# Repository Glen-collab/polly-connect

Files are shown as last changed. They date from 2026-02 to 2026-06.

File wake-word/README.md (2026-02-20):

# Wake Word Training - "Hey Polly"

This folder contains assets for training a custom wake word model.

## Current Status

Currently using **"Hey Jarvis"** from OpenWakeWord as a placeholder. Custom "Hey Polly" training is Phase 4.

## Training Process

### 1. Collect Audio Samples

**Positive samples** (47 recorded):
- Clear "Hey Polly" recordings
- Multiple speakers if possible
- Various distances from mic
- Different ambient noise levels

**Negative samples** (20 recorded):
- Random speech not containing wake word
- Common phrases that sound similar
- Background noise

### 2. Use Google Colab for Training

1. Go to [Google Colab](https://colab.research.google.com)
2. Open the OpenWakeWord training notebook:
   ```
   https://github.com/dscripka/openWakeWord/blob/main/notebooks/automatic_model_training.ipynb
   ```
3. Change runtime to **T4 GPU** (Runtime → Change runtime type)
4. Upload your samples:
   - `positive/` → "Hey Polly" clips
   - `negative/` → non-wake-word clips
5. Run all cells
6. Download the trained model (`.onnx` or `.tflite`)

### 3. Deploy to ESP32

**Option A: TFLite (recommended)**
- Smaller model size
- Native ESP32 support via TensorFlow Lite Micro
- Convert ONNX to TFLite if needed

**Option B: Edge Impulse**
- User-friendly web interface
- Handles conversion automatically
- Free tier available

### 4. Integration

Place the model file in `firmware/polly-esp32/` and update wake word detection code.

## Sample Requirements

### Recording Tips

- Use same mic type as target device (INMP441)
- 16kHz sample rate, mono
- 1-2 seconds per clip
- Include slight variations:
  - "Hey Polly"
  - "Hey, Polly"
  - "Hey Polly?"

### File Format

- WAV files preferred
- 16-bit PCM
- Naming: `positive_001.wav`, `negative_001.wav`

## Alternative: Picovoice Porcupine

For production, consider [Picovoice Porcupine](https://picovoice.ai/):
- Professional-grade accuracy
- Easy custom wake word training
- Free tier for personal use
- Native ESP32 support

## Resources

- [OpenWakeWord](https://github.com/dscripka/openWakeWord)
- [Edge Impulse](https://www.edgeimpulse.com/)
- [Picovoice Porcupine](https://picovoice.ai/platform/porcupine/)
- [TensorFlow Lite Micro](https://www.tensorflow.org/lite/microcontrollers)

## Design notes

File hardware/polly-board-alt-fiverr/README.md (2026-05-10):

# Polly PCB v2 — Fiverr alternate

Drop the Fiverr designer's KiCad project + production files here when ready.
This sits alongside `hardware/polly-board/` (Paul's canonical v2) so we can
manufacture and bench-test both designs and pick a winner.

Use `hardware/COMPONENTS_FOR_DESIGNER.md` as the spec and Paul's project at
`hardware/polly-board/` as the reference layout.

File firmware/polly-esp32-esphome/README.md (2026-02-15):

# Polly ESP32-S3 Voice Assistant (ESPHome + microWakeWord)

On-device wake word detection using **microWakeWord** integrated with Home Assistant and Polly Connect server.

## Why ESPHome + Home Assistant?

✅ **microWakeWord ecosystem** - Access to [hundreds of community wake words](https://github.com/TaterTotterson/microWakeWords)
✅ **Easy customization** - YAML configuration instead of C++ programming
✅ **Proven and stable** - Used by thousands in Home Assistant community
✅ **OTA updates** - Update firmware wirelessly
✅ **Web dashboard** - Monitor and control from browser

## Hardware Requirements

### Required:
1. **ESP32-S3 Development Board** with PSRAM (8MB recommended)
2. **INMP441 I2S MEMS Microphone** (~$2-5)

### Optional:
3. **RGB LED** for status indication (WS2812 or discrete RGB)

### Wiring Diagram (INMP441 → ESP32-S3):

```
INMP441 Pin    ESP32-S3 GPIO    Purpose
-----------    -------------    -------
WS             GPIO 42          I2S Word Select (LRCLK)
SD             GPIO 41          I2S Serial Data (DIN)
SCK            GPIO 40          I2S Serial Clock (BCLK)
L/R            GND              Channel Select (Left)
VDD            3.3V             Power
GND            GND              Ground
```

**Optional RGB LED:**
```
LED Pin        ESP32-S3 GPIO
-------        -------------
Red            GPIO 48
Green          GPIO 47
Blue           GPIO 21
GND            GND
```

## Software Requirements

### 1. Install Home Assistant

**Option A: Run on Same Computer as Polly Server**
```bash
# Install Home Assistant Core (Python)
python3 -m pip install homeassistant
hass
```
Access at: `http://localhost:8123`

**Option B: Separate Raspberry Pi / VM**
- Download Home Assistant OS: https://www.home-assistant.io/installation/
- Flash to SD card or install in VM
- Access at: `http://homeassistant.local:8123`

**Option C: Docker (Recommended for Testing)**
```bash
docker run -d \
  --name homeassistant \
  --privileged \
  --restart=unless-stopped \
  -e TZ=America/New_York \
  -v /PATH_TO_YOUR_CONFIG:/config \
  --network=host \
  ghcr.io/home-assistant/home-assistant:stable
```

### 2. Install ESPHome in Home Assistant

1. Open Home Assistant web interface
2. Go to **Settings** → **Add-ons**
3. Click **Add-on Store**
4. Search for **ESPHome**
5. Click **Install**
6. Start the ESPHome add-on
7. Open the ESPHome web UI

### 3. Install ESPHome CLI (Alternative)

If you prefer command-line:
```bash
pip install esphome
```

## Setup Steps

### Step 1: Configure Secrets

Edit `secrets.yaml`:
```yaml
wifi_ssid: "YourWiFiSSID"
wifi_password: "YourWiFiPassword"
api_encryption_key: ""  # Will be auto-generated
ota_password: "polly-ota-password"
```

Generate API encryption key:
```bash
openssl rand -base64 32
```

### Step 2: Compile and Flash Firmware

**Using ESPHome Dashboard (Easiest):**
1. Open ESPHome in Home Assistant
2. Click **+ New Device**
3. Give it a name: `polly-voice-assistant`
4. Choose **ESP32-S3**
5. Copy the contents of `polly-voice-assistant.yaml` into the editor
6. Click **Install** → **Plug into this computer**
7. Select the USB port and flash

**Using ESPHome CLI:**
```bash
cd firmware/polly-esp32-esphome

# Compile
esphome compile polly-voice-assistant.yaml

# Flash (ESP32 connected via USB)
esphome upload polly-voice-assistant.yaml
```

### Step 3: Verify Connection

1. Device should appear in Home Assistant **Settings** → **Devices & Services**
2. Click **Configure** and enter API encryption key
3. Device should show as "Online"

### Step 4: Test Wake Word Detection

1. Say **"Okay Nabu"** into the microphone
2. Watch the logs in ESPHome dashboard
3. LED should turn green when wake word detected
4. LED should turn blue when listening for command

**Check logs:**
```bash
esphome logs polly-voice-assistant.yaml
```

Expected output:
```
[microWakeWord] Wake word detected: Okay Nabu
[voice_assistant] Listening for command...
```

### Step 5: Bridge to Polly Server

#### A. Update Polly Server

The server has been updated with a new endpoint: `/api/commands/process`

This endpoint receives voice commands from Home Assistant and processes them through your Polly intent parser and database.

#### B. Configure Home Assistant Automation

1. In Home Assistant, go to **Settings** → **Automations & Scenes**
2. Click **Create Automation**
3. Choose **Start with an empty automation**
4. Switch to **YAML mode** (three dots menu)
5. Paste the contents from `home-assistant-config/polly-bridge-automation.yaml`
6. **Important**: Replace `YOUR_POLLY_SERVER_IP` with your actual server IP
7. Save the automation

**Or manually add to `configuration.yaml`:**
```yaml
# Add this to your Home Assistant configuration.yaml
automation: !include automations.yaml
rest_command: !include rest_commands.yaml
```

Then create `rest_commands.yaml`:
```yaml
polly_send_command:
  url: "http://192.168.1.100:8000/api/commands/process"
  method: POST
  content_type: "application/json"
  payload: >
    {
      "transcription": "{{ transcription }}",
      "device_id": "{{ device_id }}",
      "source": "home_assistant"
    }
```

### Step 6: Test End-to-End

1. **Start Polly Server:**
   ```bash
   cd server
   python main.py
   ```

2. **Say wake word:** "Okay Nabu"
3. **Say command:** "My keys are in the kitchen"
4. **Check Polly server logs:**
   ```
   [homeassistant] Received command: My keys are in the kitchen
   [intent_parser] Intent: store
   [database] Stored: keys → kitchen
   ```

5. **Test retrieval:**
   - Say: "Okay Nabu"
   - Say: "Where are my keys?"
   - Server should respond: "The keys are in the kitchen."

## Available Wake Words

### Pre-installed:
- **okay_nabu** (default)
- **hey_jarvis**
- **alexa**
- **hey_mycroft**

### Change Wake Word:

Edit `polly-voice-assistant.yaml`:
```yaml
micro_wake_word:
  model: hey_jarvis  # Change this line
  probability_cutoff: 0.97
  sliding_window_average_size: 5
```

Then reflash:
```bash
esphome upload polly-voice-assistant.yaml
```

### Use Community Wake Words:

Browse available models:
- https://github.com/TaterTotterson/microWakeWords
- https://github.com/esphome/micro-wake-word-models

Example using custom wake word from GitHub:
```yaml
micro_wake_word:
  models:
    - model: https://github.com/TaterTotterson/microWakeWords/raw/main/models/v2/computer.tflite
```

### Create Your Own Custom Wake Word:

1. Visit: https://www.kevinahrendt.com/micro-wake-word
2. Follow the training guide using Google Colab (free)
3. Download the `.tflite` model file
4. Host it on GitHub or local webserver
5. Reference it in your ESPHome config

**Or request from community:**
- Post in Home Assistant forums
- Many community members train wake words for others
- See: https://community.home-assistant.io

## Troubleshooting

### Wake word not detected

**Check microphone:**
```bash
esphome logs polly-voice-assistant.yaml
```

Look for I2S audio initialization:
```
[i2s_audio] Initializing I2S...
[microphone] Microphone started
```

**Adjust sensitivity:**
```yaml
micro_wake_word:
  probability_cutoff: 0.90  # Lower = more sensitive (default: 0.97)
  sliding_window_average_size: 3  # Lower = faster detection (default: 5)
```

**Check wiring:**
- INMP441 L/R pin MUST be connected to GND
- Verify GPIO pins match your configuration
- Check 3.3V power supply is stable

### Home Assistant not receiving commands

**Check automation:**
1. Go to **Settings** → **Automations & Scenes**
2. Find "Polly Voice Assistant Bridge"
3. Click **Run** to manually trigger
4. Check **Trace** for errors

**Check Polly server:**
```bash
curl -X POST http://localhost:8000/api/commands/process \
  -H "Content-Type: application/json" \
  -d '{"transcription":"test command","device_id":"test"}'
```

### ESP32 won't connect to WiFi

**Check secrets.yaml:**
- SSID is correct (case-sensitive)
- Password is correct
- WiFi is 2.4GHz (ESP32 doesn't support 5GHz)

**Enable fallback hotspot:**
1. ESP32 creates WiFi network: `polly-voice-assistant Fallback`
2. Password: `polly12345`
3. Connect and reconfigure WiFi

### OTA updates fail

**Use USB:**
```bash
esphome upload polly-voice-assistant.yaml --device /dev/ttyUSB0
```

**Increase timeout:**
```yaml
ota:
  - platform: esphome
    password: !secret ota_password
    safe_mode: true
    reboot_timeout: 15min
```

## Architecture Diagram

```
┌─────────────┐
│   INMP441   │ Microphone
└──────┬──────┘
       │ I2S Audio (16kHz)
       ↓
┌──────────────────────────────┐
│      ESP32-S3 (ESPHome)      │
│  ┌────────────────────────┐  │
│  │   microWakeWord        │  │
│  │   "Okay Nabu" → ✓      │  │
│  └───────────┬────────────┘  │
│              ↓                │
│  ┌────────────────────────┐  │
│  │   Voice Assistant      │  │
│  │   Record command audio │  │
│  └───────────┬────────────┘  │
└──────────────┼───────────────┘
               │ Home Assistant API
               ↓
┌──────────────────────────────┐
│      Home Assistant          │
│  ┌────────────────────────┐  │
│  │  Whisper (Transcribe)  │  │
│  │  "my keys are..."      │  │
│  └───────────┬────────────┘  │
│              ↓                │
│  ┌────────────────────────┐  │
│  │  Automation Bridge     │  │
│  │  Forward to Polly      │  │
│  └───────────┬────────────┘  │
└──────────────┼───────────────┘
               │ HTTP POST
               ↓
┌──────────────────────────────┐
│    Polly Connect Server      │
│  ┌────────────────────────┐  │
│  │  Intent Parser         │  │
│  │  "store: keys→kitchen" │  │
│  └───────────┬────────────┘  │
│              ↓                │
│  ┌────────────────────────┐  │
│  │  Database              │  │
│  │  Save location         │  │
│  └────────────────────────┘  │
└──────────────────────────────┘
```

## Performance

- **Wake Word Latency**: <100ms
- **End-to-End**: ~2-3 seconds (wake → response)
- **Bandwidth**: ~50KB for 5-second command
- **Power**: ~150mA @ 3.3V during listening

## Customization

### Add Speaker for TTS Response

```yaml
# Add I2S speaker (MAX98357A)
i2s_audio:
  - id: i2s_out
    i2s_lrclk_pin: GPIO13
    i2s_bclk_pin: GPIO12

speaker:
  - platform: i2s_audio
    id: speaker
    dac_type: external
    i2s_dout_pin: GPIO14
    mode: mono

# Update voice assistant to use speaker
voice_assistant:
  microphone: mic
  speaker: speaker  # Add this line
```

### Change LED Pins

Update the `output` section:
```yaml
output:
  - platform: ledc
    id: led_red
    pin: GPIO1  # Change to your red LED pin
  - platform: ledc
    id: led_green
    pin: GPIO2  # Change to your green LED pin
  - platform: ledc
    id: led_blue
    pin: GPIO3  # Change to your blue LED pin
```

### Multiple Wake Words

```yaml
micro_wake_word:
  models:
    - model: okay_nabu
    - model: hey_jarvis
    - model: alexa
```

ESP32-S3 can run up to 4 models simultaneously!

## Resources

- **ESPHome Documentation**: https://esphome.io
- **microWakeWord**: https://www.kevinahrendt.com/micro-wake-word
- **Community Wake Words**: https://github.com/TaterTotterson/microWakeWords
- **Home Assistant**: https://www.home-assistant.io
- **Polly Connect**: [Your GitHub repo]

## Support

For issues:
1. Check ESPHome logs first
2. Verify Home Assistant automation
3. Test Polly server endpoint manually
4. Ask in Home Assistant community forums

## License

This project integrates multiple open-source components:
- ESPHome: MIT License
- microWakeWord: Apache 2.0
- Home Assistant: Apache 2.0

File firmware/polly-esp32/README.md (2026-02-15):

# Polly ESP32-S3 - Porcupine Wake Word Integration

On-device wake word detection for ESP32-S3 using Picovoice Porcupine.

## Overview

This firmware implements local wake word detection on ESP32-S3 hardware, eliminating the need for continuous audio streaming to the server. The device only sends audio data to the Polly Connect server **after** detecting the wake word locally, reducing bandwidth by 90%+ and improving response latency.

**Features:**
- ✅ On-device wake word detection using Porcupine
- ✅ INMP441 I2S MEMS microphone support
- ✅ WiFi connectivity with auto-reconnect
- ✅ WebSocket communication with Polly Connect server
- ✅ 2-second pre-wake audio buffering (for better transcription)
- ✅ Dual-core FreeRTOS architecture
- ✅ PSRAM utilization for large buffers

## Hardware Requirements

### Required Components:
1. **ESP32-S3 Development Board**
   - Must have PSRAM (8MB recommended)
   - Any ESP32-S3 variant will work (DevKit, WROOM, etc.)

2. **INMP441 I2S MEMS Microphone**
   - Digital I2S output
   - High-quality omnidirectional
   - ~$2-5 on AliExpress/Amazon

### Wiring (INMP441 → ESP32-S3):
```
INMP441 Pin    ESP32-S3 GPIO    Purpose
-----------    -------------    -------
WS             GPIO 42          I2S Word Select (LRCLK)
SD             GPIO 41          I2S Serial Data (DIN)
SCK            GPIO 40          I2S Serial Clock (BCLK)
L/R            GND              Channel Select (Left)
VDD            3.3V             Power
GND            GND              Ground
```

**Note:** You can change GPIO pins by editing `main/config.h`

## Software Requirements

### 1. ESP-IDF Installation

Install ESP-IDF v5.1 or later:

```bash
# Clone ESP-IDF
cd ~
git clone --recursive https://github.com/espressif/esp-idf.git
cd esp-idf
git checkout v5.1  # or latest stable release

# Install ESP-IDF
./install.sh esp32s3

# Setup environment (add to ~/.bashrc for persistence)
. ~/esp-idf/export.sh
```

Verify installation:
```bash
idf.py --version
# Should show: ESP-IDF v5.1.x or later
```

### 2. Porcupine Library and Models

**Step 1: Create Picovoice Account**
1. Go to https://console.picovoice.ai/
2. Sign up for a free account
3. Copy your Access Key (you'll need this later)

**Step 2: Download Porcupine Library**

The pre-compiled Porcupine library for ESP32-S3:

```bash
cd components/porcupine/lib/

# Download from Porcupine repository
# Note: Check the latest Porcupine releases for the exact URL
wget https://github.com/Picovoice/porcupine/raw/master/lib/esp32/libpv_porcupine.a
```

**Step 3: Download Porcupine Header**

```bash
cd components/porcupine/include/

# Download the header file
wget https://github.com/Picovoice/porcupine/raw/master/include/pv_porcupine.h
```

**Step 4: Download Wake Word Model**

Choose one of the built-in wake words:

```bash
cd components/porcupine/models/

# Download "Jarvis" wake word model (recommended)
wget https://github.com/Picovoice/porcupine/raw/master/resources/keyword_files/esp32/jarvis_esp.ppn

# Or download other wake words:
# wget https://github.com/Picovoice/porcupine/raw/master/resources/keyword_files/esp32/alexa_esp.ppn
# wget https://github.com/Picovoice/porcupine/raw/master/resources/keyword_files/esp32/computer_esp.ppn
```

**Alternative: Custom Wake Word**
- Train custom wake word at https://console.picovoice.ai/
- Download `.ppn` file for ESP32 platform
- Update `components/porcupine/CMakeLists.txt` with new model name

## Configuration

Configure the project before building:

```bash
cd firmware/polly-esp32
idf.py menuconfig
```

Navigate to **"Polly ESP32 Configuration"** and set:

| Setting | Description | Example |
|---|---|---|
| WiFi SSID | Your WiFi network name | `MyHomeWiFi` |
| WiFi Password | Your WiFi password | `MyPassword123` |
| Maximum Retry | WiFi reconnect attempts | `5` |
| Server WebSocket URI | Polly Connect server URL | `ws://192.168.1.100:8000/api/audio/stream` |
| Picovoice Access Key | Your Picovoice access key | `YOUR_ACCESS_KEY_HERE` |
| Wake word sensitivity | Detection sensitivity (0.0-1.0) | `0.5` |
| Pre-wake audio buffer | Seconds of pre-buffered audio | `2` |

**Important Notes:**
- Replace `192.168.1.100` with your server's actual IP address
- You can find your server IP with: `ip addr show` (Linux) or `ipconfig` (Windows)
- Higher sensitivity = more detections but more false positives
- Lower sensitivity = fewer false positives but might miss wake words

## Building and Flashing

### Build the Firmware

```bash
cd firmware/polly-esp32

# Clean previous builds (optional)
idf.py fullclean

# Build the project
idf.py build
```

Expected output:
```
Project build complete. To flash, run:
  idf.py -p (PORT) flash
```

### Flash to ESP32-S3

Connect your ESP32-S3 via USB, then:

```bash
# Auto-detect port and flash
idf.py flash

# Or specify port explicitly
idf.py -p /dev/ttyUSB0 flash    # Linux
idf.py -p COM3 flash             # Windows
```

### Monitor Serial Output

```bash
# Start serial monitor
idf.py monitor

# Or flash and monitor in one command
idf.py flash monitor
```

**Keyboard shortcuts in monitor:**
- `Ctrl+]` - Exit monitor
- `Ctrl+T` then `Ctrl+H` - Show help

## Expected Boot Sequence

After flashing, you should see:

```
========================================
  Polly ESP32-S3 - Porcupine Wake Word
========================================
[main] Connecting to WiFi SSID: MyHomeWiFi
[wifi_manager] WiFi initialization complete
[wifi_manager] Got IP:192.168.1.150
[wifi_manager] Connected to SSID:MyHomeWiFi
[porcupine] Initializing Porcupine
[porcupine] Model size: 85234 bytes
[porcupine] Sensitivity: 0.50
[porcupine] Porcupine initialized successfully
[porcupine] Frame length: 512 samples
[porcupine] Sample rate: 16000 Hz
[audio_capture] Allocated circular buffer: 62 frames (63488 bytes)
[audio_capture] I2S initialized (16kHz, mono, 16-bit)
[audio_capture] GPIO: WS=42, SD=41, SCK=40
[websocket] WebSocket client started
[websocket] WebSocket connected
[main] Creating tasks...
[audio_capture] Audio capture task started
[wake_word] Wake word task started
[streaming] Streaming task started
========================================
System initialized successfully!
Listening for wake word...
========================================
```

## Testing Wake Word Detection

### 1. Basic Wake Word Test

Say **"Jarvis"** clearly into the microphone (1-3 meters away).

Expected logs:
```
[porcupine] *** WAKE WORD DETECTED! (index: 0) ***
[main] WAKE WORD DETECTED!
[main] State transition: IDLE -> WAKE_DETECTED
[streaming] Starting audio streaming...
[websocket] Sent wake_word_detected event
[streaming] Streaming 62 frames of pre-buffered audio
[streaming] Streaming live audio (max 5 seconds)...
```

### 2. Full Command Test

1. Say **"Jarvis"** (wake word)
2. Wait for acknowledgment (LED/log)
3. Say command: **"where are my keys"**
4. Wait for response

Expected logs:
```
[porcupine] *** WAKE WORD DETECTED! (index: 0) ***
[main] Starting audio streaming...
[websocket] Sent wake_word_detected event
[streaming] Audio streaming complete (312 live frames sent)
[websocket] Sent command_end event
[main] State transition: WAKE_DETECTED -> PROCESSING
[main] Transcription: where are my keys
[main] Intent: retrieve_item
[main] Response: The keys are in the kitchen.
[main] State transition: PROCESSING -> IDLE
[main] Ready for next wake word
```

### 3. Server Verification

On your Polly Connect server, check the logs:

```bash
cd server
python main.py
```

Expected server output:
```
[audio] Device connected: esp32-s3-001
[audio] Wake word detected by device: esp32-s3-001
[transcription] Transcribing audio...
[transcription] Result: where are my keys
[intent_parser] Intent: retrieve_item
[database] Query: SELECT location FROM items WHERE item='keys'
[audio] Response: The keys are in the kitchen.
```

## Troubleshooting

### Problem: Wake word not detected

**Solutions:**
1. **Increase sensitivity**: `idf.py menuconfig` → Set sensitivity to `0.7`
2. **Check microphone wiring**: Verify INMP441 connections
3. **Test microphone**: Check I2S logs for audio capture activity
4. **Check model**: Ensure correct wake word model is embedded
5. **Speak clearly**: Pronounce "Jarvis" distinctly, 1-2 meters from mic

Debug commands:
```bash
# Check if audio is being captured
idf.py monitor | grep "audio_capture"

# Check Porcupine processing
idf.py monitor | grep "porcupine"
```

### Problem: WebSocket connection fails

**Solutions:**
1. **Verify server IP**: `idf.py menuconfig` → Check Server URI
2. **Ping server**: `ping 192.168.1.100` from ESP32's network
3. **Check firewall**: Ensure port 8000 is open
4. **Restart server**: `cd server && python main.py`
5. **Check WiFi**: Verify ESP32 has IP address

Test WebSocket manually:
```bash
# Install wscat
npm install -g wscat

# Test connection
wscat -c ws://192.168.1.100:8000/api/audio/stream
```

### Problem: Out of memory error

**Solutions:**
1. **Verify PSRAM**: Check `sdkconfig.defaults` has `CONFIG_SPIRAM=y`
2. **Check hardware**: ESP32-S3 board must have PSRAM chip
3. **Reduce buffer**: Lower `AUDIO_BUFFER_SECONDS` in menuconfig

Check memory usage:
```bash
idf.py monitor | grep "Heap"
# Should show: Heap: ~200000 bytes, PSRAM: ~8000000 bytes
```

### Problem: Poor audio quality

**Solutions:**
1. **Check L/R pin**: INMP441 L/R must be connected to GND
2. **Verify GPIO**: Confirm WS=42, SD=41, SCK=40 in `config.h`
3. **Check power**: Ensure stable 3.3V supply
4. **Reduce noise**: Keep wires short, away from power lines

### Problem: False positives (random detections)

**Solutions:**
1. **Decrease sensitivity**: Set to `0.3` or `0.4`
2. **Reduce noise**: Move away from fans, air conditioners
3. **Use different wake word**: Try "Computer" instead of "Jarvis"

### Problem: Build errors

**Common errors:**

**"pv_porcupine.h: No such file"**
```bash
# Download the header file
cd components/porcupine/include/
wget https://github.com/Picovoice/porcupine/raw/master/include/pv_porcupine.h
```

**"libpv_porcupine.a: No such file"**
```bash
# Download the library
cd components/porcupine/lib/
wget https://github.com/Picovoice/porcupine/raw/master/lib/esp32/libpv_porcupine.a
```

**"jarvis_esp.ppn: No such file"**
```bash
# Download the wake word model
cd components/porcupine/models/
wget https://github.com/Picovoice/porcupine/raw/master/resources/keyword_files/esp32/jarvis_esp.ppn
```

## Customization

### Change Wake Word

To use a different wake word (e.g., "Computer" instead of "Jarvis"):

1. Download the model:
   ```bash
   cd components/porcupine/models/
   wget https://github.com/Picovoice/porcupine/raw/master/resources/keyword_files/esp32/computer_esp.ppn
   ```

2. Update `components/porcupine/CMakeLists.txt`:
   ```cmake
   target_add_binary_data(${COMPONENT_LIB}
       "${CMAKE_CURRENT_SOURCE_DIR}/models/computer_esp.ppn"
       BINARY
   )
   ```

3. Update `main/porcupine_manager.c`:
   ```c
   extern const uint8_t computer_ppn_start[] asm("_binary_computer_esp_ppn_start");
   extern const uint8_t computer_ppn_end[]   asm("_binary_computer_esp_ppn_end");

   ctx->model_buffer = computer_ppn_start;
   ctx->model_size = computer_ppn_end - computer_ppn_start;
   ```

4. Rebuild and flash:
   ```bash
   idf.py build flash
   ```

### Change GPIO Pins

Edit `main/config.h`:

```c
// GPIO Configuration (INMP441)
#define I2S_WS              GPIO_NUM_42  // Change to your WS pin
#define I2S_SD              GPIO_NUM_41  // Change to your SD pin
#define I2S_SCK             GPIO_NUM_40  // Change to your SCK pin
```

Then rebuild:
```bash
idf.py build flash
```

### Adjust Sensitivity

Via menuconfig:
```bash
idf.py menuconfig
# → Polly ESP32 Configuration → Wake word sensitivity
```

Or edit `main/config.h`:
```c
#define PORCUPINE_SENSITIVITY   0.7f  // Range: 0.0-1.0
```

## Architecture Overview

### System Flow

```
┌─────────────┐
│   INMP441   │ (Microphone)
│  Microphone │
└──────┬──────┘
       │ I2S Audio (16kHz, 16-bit, mono)
       ↓
┌─────────────────────────────────────────┐
│           ESP32-S3 Firmware             │
│  ┌─────────────────────────────────┐   │
│  │  Audio Capture Task (Core 0)    │   │
│  │  - Read 512-sample frames       │   │
│  │  - Store in circular buffer     │   │
│  │  - Send to queue                │   │
│  └───────────┬─────────────────────┘   │
│              │                          │
│              ↓                          │
│  ┌─────────────────────────────────┐   │
│  │  Wake Word Task (Core 1)        │   │
│  │  - Porcupine processing         │   │
│  │  - Detect "Jarvis"              │   │
│  │  - Trigger streaming task       │   │
│  └───────────┬─────────────────────┘   │
│              │ (wake detected)          │
│              ↓                          │
│  ┌─────────────────────────────────┐   │
│  │  Streaming Task (Core 0)        │   │
│  │  - Send wake_word_detected      │   │
│  │  - Stream pre-buffered audio    │   │
│  │  - Stream live audio (5s)       │   │
│  │  - Send command_end             │   │
│  └───────────┬─────────────────────┘   │
│              │ WebSocket                │
└──────────────┼─────────────────────────┘
               │
               ↓
┌──────────────────────────────────────────┐
│      Polly Connect Server (Python)       │
│  - Receive wake_word_detected event     │
│  - Receive audio_stream data            │
│  - Transcribe with Whisper              │
│  - Parse intent                          │
│  - Generate response                     │
│  - Send TTS audio (future)               │
└──────────────────────────────────────────┘
```

### Memory Layout

- **Flash (8MB)**:
  - Application: ~300 KB
  - Porcupine library: ~1.5 MB
  - Wake word model: ~100 KB
  - Remaining: ~6.1 MB free

- **SRAM (512 KB)**:
  - FreeRTOS tasks: ~50 KB
  - WiFi/TCP stack: ~100 KB
  - Remaining: ~360 KB free

- **PSRAM (8 MB)**:
  - Circular audio buffer: ~64 KB
  - Porcupine runtime: ~200 KB
  - Frame buffers: ~10 KB
  - Remaining: ~7.7 MB free

### FreeRTOS Tasks

| Task | Core | Priority | Stack | Purpose |
|---|---|---|---|---|
| `audio_capture` | 0 | 5 | 8 KB | Read I2S audio frames |
| `wake_word` | 1 | 6 | 16 KB | Porcupine wake word detection |
| `audio_stream` | 0 | 5 | 8 KB | Stream audio to server |
| `websocket` | 0 | 4 | 8 KB | WebSocket communication |

## Performance Metrics

- **Wake Word Latency**: <100ms from speech to detection
- **Bandwidth Savings**: 90%+ reduction (only streams 3-5s after wake)
- **Power Consumption**: ~150mA @ 3.3V during active listening
- **Detection Range**: 1-3 meters in quiet environment
- **False Positive Rate**: <1 per hour (at sensitivity 0.5)

## Future Enhancements

### Voice Activity Detection (VAD)
- Auto-detect end of command (no 5-second timeout)
- Implement silence detection algorithm
- Reduce latency by 2-3 seconds

### TTS Audio Playback
- Add I2S speaker output (e.g., MAX98357A)
- Receive and play `audio_chunk` events
- Complete offline voice assistant

### LED Feedback
- WS2812 RGB LED on GPIO 48
- Blue: Idle/listening
- Green: Wake word detected
- Yellow: Processing
- Red: Error

### Over-the-Air (OTA) Updates
- ESP-IDF OTA component integration
- Server endpoint for firmware updates
- No physical access needed for updates

## License

This project uses Picovoice Porcupine which requires attribution:
- Porcupine is licensed under Apache 2.0
- Attribution: "This product uses Porcupine from Picovoice"
- See https://picovoice.ai for terms

## Support

**Issues:**
- ESP32-S3 firmware: Check this README's Troubleshooting section
- Porcupine library: https://github.com/Picovoice/porcupine
- Polly Connect server: Check server documentation

**Resources:**
- ESP-IDF Documentation: https://docs.espressif.com/projects/esp-idf/
- Porcupine Documentation: https://picovoice.ai/docs/porcupine/
- Picovoice Console: https://console.picovoice.ai/

## Credits

- **Picovoice** for Porcupine wake word engine
- **Espressif** for ESP32-S3 and ESP-IDF
- **Polly Connect** server integration

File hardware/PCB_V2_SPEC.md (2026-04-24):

# Polly PCB v2 — Fully Assembled Production Board

## Status
**Schematic + PCB layout finalized by Paul P. (Upwork), April 17, 2026.** Glen approved; Paul closed his contract April 20 with ~24 hours logged. A separate designer was engaged to produce the manufacturing files (gerbers, BOM, CPL) from Paul's KiCad output and has not responded as of this file's date — if they don't surface, a new designer can pick this up directly from Paul's KiCad files.

**Final board render from Paul**: [`polly-board/polly_board_v2_final.png`](polly-board/polly_board_v2_final.png). This is what the delivered design looks like — dimensions, component placement, and test-point layout along the bottom edge all visible. A new designer should match this render exactly when producing manufacturing files.

**What a new designer needs to know:**
- The **schematic and board layout are done**. The remaining work is purely producing JLCPCB-ready manufacturing outputs: gerbers, drill files, a BOM CSV in LCSC format, and a CPL/POS CSV for pick-and-place.
- Paul's final KiCad files should live in `hardware/polly-board/` — if they're missing from the repo, Glen needs to get them from Paul before handoff.
- **Do NOT trust `polly_pcb_bom_jlcpcb.csv` or `polly_pcb-top-pos.csv` currently checked in.** Those are from the earlier Fiverr revision (5-pin headers for mic/amp, "5.1" ohm pull-downs instead of 5.1 kΩ, ~10 mm button spacing instead of 15 mm). They must be regenerated from Paul's final files.

For the full upstream paper trail, see:
- `polly-board/SCHEMATIC-FIXES.md` — 20 fixes applied to the first (Fiverr) designer's schematic
- `polly-board/DESIGNER-REVIEW.md` — review of first designer's revised schematic
- `polly-board/PCB-STATUS.md` — verified net list after schematic fixes

## Goal
Board comes from JLCPCB fully assembled. Zero hand soldering. Only two plug-in connections a customer ever touches: speaker wire (JST 2-pin) and LED wire for Polly's eyes (JST 3-pin). Flash firmware via USB-C, ship. No exposed programming header, no pin headers, no loose wires.

## Overview
- **MCU**: ESP32-S3-WROOM-1-N16R8 (built-in PCB antenna, 16MB flash, 8MB PSRAM)
- **Microphone**: ICS-43434 MEMS mic, I2S (soldered directly on board) — replaces INMP441 (out of stock at JLCPCB)
- **Amplifier**: MAX98357A I2S DAC (soldered directly on board)
- **LED**: WS2812B-mini addressable RGB (soldered on board, optional JST for external eyes)
- **Power**: USB-C 5V input → AMS1117-3.3 for 3.3V rail
- **Buttons**: BOOT (GPIO0, doubles as "Story" button in firmware) + RESET (EN) — minimum 15 mm apart on the perch edge
- **Programming**: USB-C for flashing. UART fallback exposed as **test points only** (no through-hole header, no DNP connector)
- **Board size**: 45 mm × 35 mm (2-layer)

---

## Components & LCSC Part Numbers

### U1 — ESP32-S3-WROOM-1-N16R8
- **LCSC**: C2913202
- **Package**: SMD module (19.2mm x 18mm)
- **CRITICAL**: Must be N16R8 (16MB flash + 8MB octal PSRAM). **NO SUBSTITUTIONS.** Previous order substituted N4R2 which is incompatible.
- Built-in PCB antenna (NOT the 1U variant — no external antenna needed)
- Pin assignments below

### U2 — AMS1117-3.3 (3.3V Regulator)
- **LCSC**: C6186
- **Package**: SOT-223
- **Connections**: VIN → +5V (VBUS), VOUT → +3.3V rail, GND → GND

### U3 — ICS-43434 MEMS Microphone (I2S)
- **LCSC**: confirm against Paul's final BOM when received. ICS-43434 was confirmed in JLCPCB stock as of Apr 2026; if it has since gone out of stock, the replacement must be **I2S** (not PDM — firmware does not support PDM).
- **Why not INMP441**: the original spec called for INMP441 (C2837371) but it was out of stock at JLCPCB when Paul sourced components. ICS-43434 (TDK) is the same-family successor — same I2S interface, same LGA-6 footprint class, and drop-in compatible with the firmware's SCK/WS/SD pinout.
- **Package**: LGA-6 (≈4×3 mm, bottom-port MEMS)
- **Connections**:
  - SCK → GPIO6 (clock)
  - WS → GPIO5 (word select)
  - SD → GPIO4 (data out)
  - L/R (channel select) → GND (hard-wired on PCB trace — selects left channel)
  - VDD → +3.3V (do NOT connect to +5V — will damage the part)
  - GND → GND
- **PCB notes**:
  - **Edge-mounted on the perch edge** — acoustic port faces outward (sideways through the stump wall), NOT down through the PCB
  - Verify ICS-43434 port orientation against the datasheet before placing — pinout and port location can differ from INMP441
  - Keep away from noisy traces (power, high-speed digital)
  - Keep as far as practical from the speaker JST to reduce acoustic feedback
  - Recommended: 100nF decoupling cap on VDD close to the mic

### U4 — MAX98357A I2S Amplifier
- **LCSC**: C2682619 (or search "MAX98357AETE+T")
- **Package**: TQFN-16 (3mm x 3mm)
- **Connections**:
  - BCLK → GPIO12 (bit clock)
  - LRCLK → GPIO11 (left/right clock)
  - DIN → GPIO10 (data in)
  - VDD → +5V (VBUS) — amp runs on 5V for louder output
  - GND → GND
  - GAIN → leave unconnected (default 9dB) or tie to GND for 12dB
  - SD_MODE → pull high with 100kΩ to VDD (enables amp; can tie to GPIO for mute control)
  - OUTP → Speaker + (via JST connector)
  - OUTN → Speaker - (via JST connector)
- **Supporting components**:
  - C5: 10µF ceramic cap on VDD (close to chip)
  - C6: 0.1µF ceramic cap on VDD (close to chip)
  - FB1: Ferrite bead on VDD line (optional, reduces noise)
  - R5: 100kΩ pull-up on SD_MODE to VDD

### LED1 — WS2812B-Mini (Addressable RGB LED)
- **LCSC**: C2890037 (or search "WS2812B-Mini" 3.5x3.5mm)
- **Package**: SMD 3535
- **Connections**:
  - DIN → GPIO48 (data in — NO series resistor, direct connection)
  - VDD → +3.3V or +5V
  - GND → GND
  - DOUT → JST connector pin 1 (for daisy-chaining to external LED eyes)
- **PCB notes**:
  - NO resistor on data line (remove R4 from v1 design)
  - Place on board edge so it's visible, or just use as data passthrough to JST

### J1 — USB-C Receptacle (Power + Data)
- **LCSC**: C165948 (HRO TYPE-C-31-M-12, 16-pin)
- **Connections** (same as v1):
  - VBUS → +5V rail
  - GND → GND
  - CC1 → 5.1kΩ → GND (R2)
  - CC2 → 5.1kΩ → GND (R3)
  - D+ → GPIO20 (USB data)
  - D- → GPIO19 (USB data)

### J2 — Speaker Output (JST-PH 2-pin)
- **LCSC**: C131337 (JST-PH 2.0mm, right-angle or vertical)
- **Connections**:
  - Pin 1 → MAX98357A OUTP
  - Pin 2 → MAX98357A OUTN

### J3 — LED Eyes (JST-PH 3-pin)
- **LCSC**: C157929 (JST-PH 2.0mm 3-pin, right-angle or vertical)
- **Connections**:
  - Pin 1 → WS2812B DOUT (data for external LEDs)
  - Pin 2 → +5V (power for external LEDs)
  - Pin 3 → GND

### SW1 — BOOT / Story Button
- **LCSC**: C221880 (PTS645 SMD tactile) — or right-angle / side-actuated equivalent (see perch-edge notes below)
- **Connection**: GPIO0 → GND when pressed
- **Firmware dual-use**: short press triggers story recording; holding on power-up enters flash mode. There is **no separate Story button** on the board — BOOT doubles as Story.

### SW2 — RESET Button
- **LCSC**: C221880 — or right-angle / side-actuated equivalent (see perch-edge notes below)
- **Connection**: EN → GND when pressed
- **Spacing from SW1**: minimum **15 mm** on the perch edge — needed so 3D-printed button caps don't collide and a user can press one without hitting the other.

### Passive Components

| Ref | Value | Package | LCSC | Purpose |
|-----|---|---|---|---|
| C1 | 100nF | 0805 | C49678 | Regulator output decoupling |
| C2 | 10µF | 0805 | C15850 | Regulator output bulk |
| C3 | 100nF | 0805 | C49678 | ESP32 decoupling |
| C4 | 10µF | 0805 | C15850 | Regulator input filter |
| C5 | 10µF | 0805 | C15850 | MAX98357A VDD bulk |
| C6 | 100nF | 0805 | C49678 | MAX98357A VDD decoupling |
| C7 | 100nF | 0805 | C49678 | INMP441 VDD decoupling |
| R1 | 10kΩ | 0805 | C17414 | EN pull-up |
| R2 | 5.1kΩ | 0805 | C27834 | USB CC1 pull-down |
| R3 | 5.1kΩ | 0805 | C27834 | USB CC2 pull-down |
| R5 | 100kΩ | 0805 | C25803 | MAX98357A SD_MODE pull-up |

**NOTE**: No R4 in v2. The 330Ω resistor on GPIO48 from v1 is removed — WS2812 needs a direct data connection.

---

## ESP32-S3 GPIO Pin Assignments

| GPIO | ESP32 Module Pin | Function | Connected To |
|---|---|---|---|
| GPIO0 | Pin 27 | BOOT button | SW1 → GND |
| GPIO4 | Pin 4 | Mic SD (data) | INMP441 SD |
| GPIO5 | Pin 5 | Mic WS (word select) | INMP441 WS |
| GPIO6 | Pin 6 | Mic SCK (clock) | INMP441 SCK |
| GPIO10 | Pin 18 | Amp DIN (data) | MAX98357A DIN |
| GPIO11 | Pin 19 | Amp LRC (left/right clock) | MAX98357A LRCLK |
| GPIO12 | Pin 20 | Amp BCLK (bit clock) | MAX98357A BCLK |
| GPIO19 | Pin 13 | USB D- | USB-C D- |
| GPIO20 | Pin 14 | USB D+ | USB-C D+ |
| GPIO48 | Pin 25 | LED Data | WS2812B DIN |
| EN | Pin 3 | Reset | R1 pull-up + SW2 → GND |

All other GPIO pins unused and left floating.

---

## PCB Layout Notes for Designer

### Placement
- ESP32 module near center, antenna end overhanging board edge OR clear of ground pour
- AMS1117 near USB-C connector (short power path)
- INMP441 near board edge, sound hole facing outward/upward
- MAX98357A near JST speaker connector
- Decoupling caps as close as possible to their respective ICs

### Perch Edge — Buttons, LED & Mic Cluster (IMPORTANT)
The PCB mounts **vertically** inside a 3D-printed parrot stump/perch that sits on a table. One edge of the board (the "perch edge") faces outward through the side of the stump. **All user-facing components must be grouped on this single edge.**

**Components on the perch edge** (final order, left to right, as approved with Paul):

```
SW2 (Reset) ─── LED1 ─── U3 (Mic) ─── SW1 (Story/Boot)
           ≥15 mm between SW1 and SW2 end-to-end
```

**Why the mic is on the perch edge:** The board is vertical inside the stump. If the mic faces down (bottom of board), it would be muffled against the table. If it faces up, it's buried inside the parrot body. Mounting the mic on the perch edge means the sound hole faces outward through the stump wall — clear line to the user's voice.

**Layout requirements:**
- **Button spacing: ≥15 mm between SW1 and SW2** (center-to-center). This is a firm rule — Glen confirmed it with Paul, driven by 3D-printed button-cap clearance and ergonomic press. The earlier Fiverr-era `polly_pcb-top-pos.csv` has them ~10 mm apart, which is WRONG — regenerate CPL from Paul's final layout, don't use the old file.
- **SW1 and SW2**: Use **right-angle / side-actuated tactile switches** so the press direction is horizontal (sideways off the board, toward the user through the stump wall). If right-angle variants aren't available in JLCPCB's assembly library, place top-press switches flush with the board edge so they can still be actuated through cutouts. Button caps are part of the 3D-printed stump design.
- **LED1 (WS2812B)**: Place on the board edge **side-firing** so light shines outward through the stump. The stump will have a small window/slot for the LED to glow through.
- **U3 (ICS-43434 mic)**: Mount on the perch edge with the **acoustic port hole facing outward** (not down through the PCB). Verify port orientation against the ICS-43434 datasheet before placing — do NOT copy the INMP441 orientation from memory, the port location may differ. The stump has a small hole aligned with the mic for voice pickup. Keep the mic as far as practical from the speaker JST (J2) to reduce acoustic feedback.
- **Alignment**: All four components should be flush with or within 1 mm of the Edge.Cuts boundary on the perch edge. The 3D-printed stump has precise cutouts for buttons, LED window, and mic hole — tolerances assume this alignment.
- **USB-C connector (J1)**: Place on the **bottom edge** (the edge that faces down into the table). Power cable runs out the bottom of the stump, hidden from view. USB-C is only used for flashing and power, not daily interaction.
- **JST connectors (J2 speaker, J3 LED eyes)**: Place on a non-perch edge (top or back). Wires run internally through the parrot body.
- **Programming test points**: In Paul's final render, the test points are laid out along the **bottom edge** alongside USB-C, as six labeled pads: **3P3, GND, EN, TX, RX, BOOT**. This is the UART fallback for field recovery — pogo-pin compatible, no through-hole header, no DNP connector. Nothing customer-facing beyond the USB-C plug and the two JSTs. Match the pad labels and ordering from the render.

### Routing
- Keep analog audio traces (INMP441 SD, MAX98357A output) away from digital noise
- Ground pour on both layers
- No copper under ESP32 antenna area
- VDD and GND traces to INMP441 should be clean (no switching noise nearby)
- USB D+/D- should be ~90Ω differential impedance (short traces OK)

### Ground Pour
- Both layers, connected with vias
- Keep clear under ESP32 antenna area

### Board Size
- **Final: 45 mm × 35 mm** (width × height, per `polly-board/polly_board_v2_final.png`). Paul's Apr 14 intermediate was 36×45; the final delivered layout is 45×35 — always match the render, not any in-flight numbers from Upwork messages.
- 2-layer (F.Cu + B.Cu)

---

## What the Customer Gets

A fully assembled PCB with:
1. ESP32-S3 with WiFi (no external antenna)
2. Built-in microphone (hears voice)
3. Built-in amplifier (drives speaker)
4. RGB LED (status indicator)
5. USB-C (power + firmware flash)
6. Two JST connectors to plug in: **speaker** and **LED eyes**

Flash firmware via USB-C. Plug in speaker. Plug in LED wire to parrot eyes. Done.

---

## JLCPCB Order Notes

1. **SMT Assembly**: All components assembled by JLCPCB (both sides if needed)
2. **BOM verification**: Verify ALL LCSC part numbers before ordering. Parts go out of stock.
3. **NO SUBSTITUTIONS on U1 (ESP32-S3-WROOM-1-N16R8, C2913202)**. Add order note: "Do not substitute ESP32 module. Must be N16R8 variant."
4. **Quantity**: Order 5-10 prototypes first to verify before production run
5. **Include JST connectors in BOM** — they should solder the JST headers on the board too

---

## Files Needed from Designer

1. Updated KiCad schematic (.kicad_sch)
2. Updated PCB layout (.kicad_pcb)
3. JLCPCB-ready exports:
   - Gerber files (board outline, copper, mask, silk, drill)
   - BOM CSV (LCSC format: Comment, Designator, Footprint, LCSC Part#)
   - CPL/POS CSV (component placement: Designator, Mid X, Mid Y, Rotation, Layer)
4. Assembly drawings (if needed for INMP441 orientation)

## Existing KiCad Project

Base files in `hardware/polly-board/`:
- `polly_pcb.kicad_pro` — project
- `polly_pcb.kicad_sch` — schematic (v1/Fiverr revision — Paul's finalized schematic should replace this once delivered)
- `polly_pcb.kicad_pcb` — layout (v1/Fiverr revision — Paul's finalized layout should replace this once delivered)
- `PCB-STATUS.md` — v1 net list reference (pin assignments still valid)

---

## Designer Handoff — What's Left To Finish

If a new designer is picking this up to produce manufacturing files, here's the punch list. **The schematic and board layout are already done** (by Paul P., Apr 2026). This is not a from-scratch redesign — do not re-route the board unless Paul's final files turn out to be unrecoverable.

### 1. Obtain Paul's final KiCad files
- Glen to request from Paul, or retrieve from Upwork message attachments (last deliverable was posted Apr 16–17, 2026 with screenshot reference `image (311).png`).
- Expected files: `polly_pcb.kicad_sch`, `polly_pcb.kicad_pcb`, `polly_pcb.kicad_pro`, and any library tables Paul added.
- Drop them into `hardware/polly-board/`, replacing the v1 files currently there.

### 2. Verify Paul's design against this spec
Before generating manufacturing files, open the KiCad project and confirm:
- [ ] Mic footprint is **ICS-43434** (LGA-6), acoustic port facing outward on the perch edge
- [ ] SW1 and SW2 are **≥15 mm apart** on the perch edge
- [ ] Perch-edge order is SW2 — LED1 — U3 — SW1 (left to right)
- [ ] USB-C on the bottom edge
- [ ] J2 (speaker JST) and J3 (LED eyes JST) on a non-perch edge
- [ ] No mid-board programming header — UART exposed as test points only
- [ ] R2, R3 are **5.1 kΩ** pull-downs to GND on CC1/CC2 (NOT 5.1 ohms, NOT pull-ups — this was bug #1 from the Fiverr revision)
- [ ] ESP32 3V3 and GND are not swapped (Fiverr-revision bug #2)
- [ ] USB D+/D- on **GPIO20 / GPIO19**, not GPIO38 / GPIO45
- [ ] SW1 → GPIO0, SW2 → EN (not GPIO18)
- [ ] ICS-43434 VDD tied to **+3.3V**, not +5V
- [ ] MAX98357A VIN tied to **+5V (VBUS)**, not +3.3V
- [ ] WS2812B DIN wired directly to GPIO48 (no series resistor — R4 removed from v1 design)
- [ ] Board outline is **45 × 35 mm** (match `polly-board/polly_board_v2_final.png`)
- [ ] Bottom-edge test points labeled **3P3, GND, EN, TX, RX, BOOT**

Full fix list is in `hardware/polly-board/SCHEMATIC-FIXES.md` (20 original errors) and `hardware/polly-board/DESIGNER-REVIEW.md` (remaining issues after first revision). Paul's final design should have all of these resolved — this checklist is just a spot-check.

### 3. Generate JLCPCB-ready outputs
- **Gerbers**: standard JLCPCB preset (F.Cu, B.Cu, F.Mask, B.Mask, F.Silks, B.Silks, Edge.Cuts, F.Paste, B.Paste, and drill files)
- **BOM CSV**: LCSC format — columns `Comment, Designator, Footprint, LCSC`. Every line must have a valid in-stock LCSC part number. Verify every part right before ordering; LCSC parts go out of stock routinely.
- **CPL / POS CSV**: pick-and-place. Columns: `Designator, Mid X, Mid Y, Rotation, Layer`
- Save outputs into `hardware/polly-board/production/` (create the folder). Do NOT overwrite the stale `polly_pcb_bom_jlcpcb.csv` or `polly_pcb-top-pos.csv` already in the repo — those are v1 Fiverr-era and kept for history only.

### 4. Critical order notes for JLCPCB
- **U2 (ESP32 module)**: the BOM entry must be `ESP32-S3-WROOM-1-N16R8` / **LCSC C2913202**. **Add a human-readable order note: "Do not substitute the ESP32 module. Must be N16R8 (16MB flash + 8MB octal PSRAM)."** A previous order was substituted to N4R2, which is incompatible with this firmware and bricked the batch.
- **SMT assembly**: both sides if Paul placed components on F.Cu and B.Cu (confirm from his layout)
- **Include the JST headers (J2, J3) in the SMT BOM** — they should be soldered by JLCPCB too, not hand-soldered later
- **Quantity**: order 5–10 prototypes first, validate, then scale

### 5. Deliverables back to Glen
- `.zip` of gerbers + drill
- BOM CSV
- CPL CSV
- Assembly drawing (if ICS-43434 orientation needs it — recommended)
- Updated KiCad project committed to the repo

---

## History

- **2026-03-02** — Initial schematic from Fiverr contractor; 20 errors documented in `SCHEMATIC-FIXES.md`
- **2026-03-02** — Fiverr designer's revision reviewed; 4 real fixes still needed plus 3 clarifications (see `DESIGNER-REVIEW.md`)
- **2026-03-03** — Schematic verified correct after Fiverr fixes applied (`PCB-STATUS.md`)
- **2026-04-08** — Upwork contract awarded to Paul P. for PCB layout
- **2026-04-09** — Paul flagged MSM261DGT003 as PDM (incompatible with firmware) and INMP441 as out of stock; Glen proposed ICS-43434 (TDK, I2S, LGA-6) as replacement
- **2026-04-12** — Paul confirmed ICS-43434 in stock, proposed converting mid-board programming header to test points
- **2026-04-13** — Glen confirmed: keep BOOT + RESET only (BOOT doubles as Story in firmware), 15 mm button separation, test points over header
- **2026-04-14** — Paul delivered reworked layout at 36 × 45 mm; MEMS mic confirmed I2S; programming header converted to test points
- **2026-04-16** — Paul posted final PCB layout for review (`image (311).png` in Upwork thread, archived in the repo as `polly-board/polly_board_v2_final.png`). Final board size **45 × 35 mm**, six labeled bottom-edge test points (3P3 / GND / EN / TX / RX / BOOT)
- **2026-04-17** — Glen approved
- **2026-04-20** — Paul closed contract, ~24 hours logged. Manufacturing-file generation handed to a separate designer (currently unresponsive as of 2026-04-24).

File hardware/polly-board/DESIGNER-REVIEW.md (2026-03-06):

# Designer's Revised Schematic — Review Notes

**Date:** 2026-03-02
**Reviewed against:** Working breadboard prototype + SCHEMATIC-FIXES.md

---

## What the Designer FIXED CORRECTLY

| Item | Before | After | Status |
|---|---|---|---|
| ESP32 3V3/GND | Swapped (would fry chip) | 3V3 → +3.3V, GND → GND | FIXED |
| VBUS → Regulator | SBU2 was feeding U1 | VBUS → U1 pin 3 (IN) | FIXED |
| U1 GND | Floating | Connected to GND | FIXED |
| USB-C GND | Isolated | Connected to GND | FIXED |
| USB D+ | GPIO38 (wrong) | GPIO20 (correct) | FIXED |
| USB D- | GPIO45 (wrong) | GPIO19 (correct) | FIXED |
| Shield | Floating | Connected to GND | FIXED |
| EN pull-up (R1) | Connected to GPIO37 | Connected to EN | FIXED |
| R3/R5 CC values | 5.1 ohm | 5.1kΩ | FIXED |
| GPIO48 LED | Was on GPIO43 | Now on J4 through R4 (330Ω) | FIXED |
| C4 | On wrong net | Between VBUS/IN and GND | FIXED |

---

## ISSUES STILL REMAINING

### Issue 1: CC1 and CC2 are PULL-UPS — should be PULL-DOWNS (CRITICAL)

**What the designer did:**
- CC1 → R3 (5.1kΩ) → **+3.3V**
- CC2 → R5 (5.1kΩ) → **+3.3V**

**What it should be:**
- CC1 → R3 (5.1kΩ) → **GND**
- CC2 → R5 (5.1kΩ) → **GND**

**Why this matters:** The USB-C spec requires 5.1kΩ pull-DOWN resistors to GND on CC1 and CC2. This tells the USB host "I am a device that wants power" (UFP / sink). Pull-ups to 3.3V would signal the opposite — that this board is a power SOURCE (DFP / host). The USB host may refuse to supply power, or worse, both sides try to source power.

**Fix:** Change R3 and R5 from connecting to +3.3V to connecting to **GND**.

---

### Issue 2: SW2 connects to GPIO18 — should be EN for reset

**What the designer did:**
- SW1 → GPIO0 → GND (labeled "Reset")
- SW2 → GPIO18 → GND

**What it should be:**
- SW1 → GPIO0 → GND (this is the **BOOT** button, not reset)
- SW2 → **EN** → GND (this is the **RESET** button)

**Why this matters:** There is no reset button on this board. SW2 on GPIO18 does nothing useful — GPIO18 has no special boot/reset function. The EN pin already has R1 (10kΩ) pulling it high, so it just needs a button to pull it low for reset.

To flash firmware, you hold BOOT (GPIO0 low), tap RESET (EN low), then release both. Without a working reset button, the user has to unplug/replug USB to reset.

**Fix:**
- Disconnect SW2 from GPIO18
- Connect SW2 between **EN** and **GND**
- Relabel SW1 as "BOOT" (not "Reset")
- Relabel SW2 as "RESET"

---

### Issue 3: J2 Pin 1 = +5V — INMP441 mic is a 3.3V device

**What the designer did:** J2 (mic header) Pin 1 → +5V

**What it should be:** The INMP441 mic is rated **1.8V to 3.3V max**. Applying 5V will damage it.

**Fix:** J2 power pin → **+3.3V** rail (AMS1117 output), not +5V

---

### Issue 4: J5 only has 4 pins — needs 5 pins

**What the designer did:** J5 is a 1x4 header (message was cut off at "Pin 1 → +3.")

**What it should be:** The MAX98357A breakout board has 5 connections: BCLK, LRC, DIN, VIN, GND. A 4-pin header is missing one signal.

J5 should be **1x5** with:

| Pin | Signal | Net |
|-----|---|-----|
| 1 | BCLK | GPIO12 |
| 2 | LRC | GPIO11 |
| 3 | DIN | GPIO10 |
| 4 | VIN | +5V (VBUS, for max speaker volume) |
| 5 | GND | GND |

**Also:** If J5 Pin 1 goes to +3.3V as the cutoff text suggests, the MAX98357A will work but at lower volume. **+5V is recommended** for audible speech volume in a room.

---

### Issue 5: J2 has 6 pins — expected 5 for INMP441

**What the designer did:** J2 is a 1x6 header. Pins 3-6 go to GPIOs (unspecified which ones).

**What it should be:** The INMP441 breakout has 5 pins: SCK, WS, SD, VDD, GND. A 6-pin header has one extra pin.

Confirm J2 pinout matches:

| Pin | Signal | Net |
|-----|---|-----|
| 1 | SCK | GPIO6 |
| 2 | WS | GPIO5 |
| 3 | SD | GPIO4 |
| 4 | VDD | +3.3V |
| 5 | GND | GND |
| 6 | (L/R select — optional) | GND or +3.3V (sets left/right channel) |

Pin 6 could be the INMP441 L/R pin — tie to GND for left channel (default). If the designer intended this, it's fine. Just needs to be confirmed.

---

### Issue 6: R2 (10kΩ) — unclear purpose

**What the designer added:** A new R2 = 10kΩ that wasn't in the original design. Its connections aren't described.

**Possible uses:**
- Pull-up on GPIO0 (boot button) — acceptable but not required since the ESP32-S3 has an internal pull-up on GPIO0
- Something else — needs confirmation from designer

**Ask the designer:** What does R2 (10kΩ) connect between?

---

### Issue 7: AMS1117 pin numbering — verify against footprint

**What the designer described:**
- Pin 3 = IN
- Pin 2 = GND
- Pin 1 = OUT

**Standard KiCad AMS1117 symbol:**
- Pin 1 = GND
- Pin 2 = Vout (output)
- Pin 3 = Vin (input)

The designer's description has pins 1 and 2 swapped compared to the standard symbol. This might just be ChatGPT misreading the schematic, OR the designer used a different symbol/footprint with non-standard pin numbering.

**Ask the designer:** Confirm the AMS1117 symbol pin mapping matches the SOT-223 footprint. On the physical SOT-223 package: Pin 1 (left) = GND, Pin 2 (center/tab) = Vout, Pin 3 (right) = Vin.

---

## Summary

| # | Issue | Severity | Fix |
|---|---|---|-----|
| 1 | CC1/CC2 pull-ups instead of pull-downs | **CRITICAL** — USB won't supply power | R3, R5 → GND not +3.3V |
| 2 | SW2 on GPIO18 instead of EN | **HIGH** — no reset button | SW2 → EN pin |
| 3 | J2 power pin = +5V | **HIGH** — will damage INMP441 mic | J2 power → +3.3V |
| 4 | J5 only 4 pins | **MEDIUM** — missing a connection | Change to 1x5 header |
| 5 | J2 has 6 pins | **LOW** — verify pinout | Confirm pin 6 purpose |
| 6 | R2 (10kΩ) unknown | **LOW** — verify | Ask designer what it connects to |
| 7 | AMS1117 pin numbering | **LOW** — may be description error | Verify against footprint |

**4 of the 7 are real fixes. The other 3 are just clarifications to confirm with the designer.**

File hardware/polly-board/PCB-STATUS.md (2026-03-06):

# Polly PCB - Layout Status

## Current State: SCHEMATIC VERIFIED — Ready for PCB Routing

**KiCad version:** 9.0.7
**Board size:** ~70mm x 50mm (Edge.Cuts rectangle)
**Layers:** 2-layer (F.Cu front, B.Cu back)
**Schematic verified:** 2026-03-03
**Designer:** Fiverr contractor (schematic fixes applied, reviewed and confirmed)

## Schematic: VERIFIED COMPLETE
All schematic errors from initial review have been fixed. Pin assignments confirmed to match the working breadboard prototype. Ready for PCB layout/routing.

## Components

| Ref | Component | Value/Footprint | Purpose |
|-----|---|---|---|
| U2 | ESP32-S3-WROOM-1 | PCM_Espressif | Main MCU |
| U1 | AMS1117-3.3 | SOT-223 | 5V → 3.3V regulator |
| J1 | USB-C Receptacle (16P) | HRO TYPE-C-31-M-12 | Power + USB data |
| J2 | 5-pin header (INMP441 mic) | PinHeader 2.54mm | Microphone breakout |
| J5 | 5-pin header (MAX98357A amp) | PinHeader 2.54mm | Amplifier breakout |
| J4 | 2-pin header (LED) | PinHeader 2.54mm | Status LED |
| SW1 | Push button (BOOT) | PTS645 SMD | GPIO0 → GND (flash mode) |
| SW2 | Push button (RESET) | PTS645 SMD | EN → GND (reset) |
| C1 | 100nF | 0805 SMD | Regulator output decoupling |
| C2 | 10uF | 0805 SMD | Regulator output bulk bypass |
| C3 | 100nF | 0805 SMD | ESP32 decoupling |
| C4 | 10uF | 0805 SMD | Regulator input filter |
| R1 | 10kΩ | 0805 SMD | EN pull-up |
| R2 | 5.1kΩ | 0805 SMD | USB CC2 pull-down to GND |
| R3 | 5.1kΩ | 0805 SMD | USB CC1 pull-down to GND |
| R4 | 330Ω | 0805 SMD | LED current limiter (GPIO48) |

## Verified Net List

```
USB-C (J1):
  VBUS (A4/A9/B4/B9) → +5V rail → U1 pin 3 (VI) → C4
  GND (A1/A12/B1/B12) → GND net
  CC1 (A5) → R3 (5.1kΩ) → GND
  CC2 (B5) → R2 (5.1kΩ) → GND
  D+ (A6/B6) → U2 pin 14 (GPIO20)
  D- (A7/B7) → U2 pin 13 (GPIO19)
  Shield (S1) → GND

AMS1117-3.3 Regulator (U1):
  Pin 3 (VI) → +5V (from VBUS)
  Pin 2 (VO) → +3.3V rail
  Pin 1 (GND) → GND

ESP32-S3-WROOM-1 (U2):
  Pin 1 (GND) → GND
  Pin 2 (3V3) → +3.3V
  Pin 3 (EN) → R1 (10kΩ) → +3.3V, also → SW2 → GND
  Pin 4 (GPIO4) → J2 pin 3 (mic SD)
  Pin 5 (GPIO5) → J2 pin 2 (mic WS)
  Pin 6 (GPIO6) → J2 pin 1 (mic SCK)
  Pin 13 (GPIO19) → USB D-
  Pin 14 (GPIO20) → USB D+
  Pin 18 (GPIO10) → J5 pin 3 (amp DIN)
  Pin 19 (GPIO11) → J5 pin 2 (amp LRC)
  Pin 20 (GPIO12) → J5 pin 1 (amp BCLK)
  Pin 25 (GPIO48) → R4 (330Ω) → J4 pin 1 (LED)
  Pin 27 (GPIO0) → SW1 → GND
  Pin 40 (GND) → GND
  Pin 41 (GND) → GND

Mic Header (J2) — INMP441:
  Pin 1 → GPIO6 (SCK)
  Pin 2 → GPIO5 (WS)
  Pin 3 → GPIO4 (SD)
  Pin 4 → +3.3V
  Pin 5 → GND

Amp Header (J5) — MAX98357A:
  Pin 1 → GPIO12 (BCLK)
  Pin 2 → GPIO11 (LRC)
  Pin 3 → GPIO10 (DIN)
  Pin 4 → +5V (VBUS)
  Pin 5 → GND

LED Header (J4):
  Pin 1 → R4 (330Ω) → GPIO48
  Pin 2 → GND

Capacitors:
  C1 (100nF): +3.3V → GND (near U1)
  C2 (10uF): +3.3V → GND (near U1)
  C3 (100nF): +3.3V → GND (near U2)
  C4 (10uF): +5V → GND (near U1 input)

Buttons:
  SW1 (BOOT): GPIO0 → GND when pressed
  SW2 (RESET): EN → GND when pressed
```

## PCB Routing Notes (for designer)

### Placement Guidelines
- U1 (regulator) near J1 (USB-C) — short power path
- C1, C2 close to U1 output
- C4 close to U1 input or J1
- C3 close to U2 pin 2 (3V3)
- ESP32-S3 antenna must overhang board edge or have ground clearance (no copper/ground pour under antenna)
- SW1 (BOOT) and SW2 (RESET) accessible from board edge

### After Routing
1. Add ground pour on both F.Cu and B.Cu (net = GND)
2. Keep antenna area clear of copper
3. Run DRC — should be clean except cosmetic silkscreen warnings
4. Fix any silkscreen overlaps

## ESP32-S3 Pin Assignments (from working prototype)

| Function | GPIO | ESP32-S3 Module Pin | Header |
|---|---|---|---|
| INMP441 SCK | GPIO 6 | Pin 6 | J2 Pin 1 |
| INMP441 WS | GPIO 5 | Pin 5 | J2 Pin 2 |
| INMP441 SD | GPIO 4 | Pin 4 | J2 Pin 3 |
| MAX98357A BCLK | GPIO 12 | Pin 20 | J5 Pin 1 |
| MAX98357A LRC | GPIO 11 | Pin 19 | J5 Pin 2 |
| MAX98357A DIN | GPIO 10 | Pin 18 | J5 Pin 3 |
| Status LED | GPIO 48 | Pin 25 | J4 Pin 1 (via R4) |
| Boot button | GPIO 0 | Pin 27 | SW1 → GND |
| EN/Reset | EN | Pin 3 | R1 pull-up + SW2 → GND |
| USB D- | GPIO 19 | Pin 13 | J1 D- |
| USB D+ | GPIO 20 | Pin 14 | J1 D+ |

## Files
- `polly_pcb.kicad_pro` — project settings
- `polly_pcb.kicad_sch` — schematic (verified complete)
- `polly_pcb.kicad_pcb` — PCB layout (needs re-routing after schematic changes)
- `SCHEMATIC-FIXES.md` — original fix list sent to designer (20 fixes)
- `DESIGNER-REVIEW.md` — review of designer's first revision

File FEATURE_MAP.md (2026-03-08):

# Polly Connect - Full Feature Map

## Core Identity
A parrot companion device for elderly users. Revolves around **one primary user** and their story. Caretakers/family can interact too (Polly asks their name). Web/mobile app for editing and management.

**The R2-D2 of devices, disguised as a parrot.**

---

## Feature 1: Legacy Book Writer (Story Mode)

### Story Mode
- User talks freely to Polly, WAV is recorded and saved
- Transcribed via Amazon Transcribe (or Whisper)
- Transcriptions are themed, organized by chapter/topic
- Compiled over time into a legacy family book

### Question Mode
- 5 guided questions per week + 15 follow-up questions = 20 questions/week
- 1,000+ total questions across a year
- Questions organized by themes: childhood, career, marriage, regrets, lessons, faith, etc.
- Answers are transcribed and stored (text only, no WAV)
- Both Story Mode and Question Mode feed into the same book

### Subscription Tiers
- **Basic**: 15 min/week story mode
- **Premium**: 30+ min/week story mode
- **Overage**: If user goes over, prompt to keep recording at premium upsell price

---

## Feature 2: WAV Button (Story Capture)

- Physical button on the ESP32 device (K1/+ on Waveshare, BOOT on breadboard)
- Caretaker or family member presses it to capture special family moments
- User can press it themselves to just talk and save for the book
- Press once to start recording, press again to stop (or auto-stops at 30 minutes)
- LED turns solid during recording; Polly announces "Recording started" / "Recording stopped"
- Saved WAV is transcribed and feeds into Legacy Book alongside Story Mode and Questions
- Think of it as a "save this moment" button

---

## Feature 3: Memory Storage ("Where's the hammer?")

### Voice Mode (Working)
- Store items + locations by voice: "The hammer is in the garage"
- Retrieve by voice: "Where's the hammer?" → "The hammer is in the garage"

### Camera Mode (Web/Mobile App)
- Take a photo of a wall, shelf, drawer, toolbox, etc.
- AI (ChatGPT Vision) identifies all visible items in a list
- User assigns a location: "put on west wall", "in right kitchen drawer"
- Bulk-imports all identified items into memory storage
- Makes retrieval easy later when user asks by voice

---

## Feature 4: Medication Reminders

### Scheduling
- Add via mobile app or by voice: "Grandma takes X pill at Y time"
- Add/remove/edit schedules easily on phone

### Alerts
- Polly squawks at the scheduled time
- Speaks: "Reminder! Take [X pill], [X amount] now."
- Follow-up check later: "Did you take your pills?"

### Compliance Tracking
- Documents whether pills were taken (yes/no + timestamp)
- Caretaker can view history on web/mobile app
- Huge value for remote family members monitoring care

---

## Feature 5: Daily Bible Verse

- 365+ verses, one per day
- Organized by ~50 topics:
  - Resilience, strength, old age, marriage, blessings, forgiveness, gratitude,
    hope, patience, wisdom, courage, comfort, peace, joy, faith, love,
    family, friendship, loss, healing, purpose, prayer, trust, mercy,
    kindness, humility, perseverance, rest, provision, protection,
    guidance, renewal, praise, thankfulness, contentment, grace,
    redemption, faithfulness, generosity, compassion, truth,
    righteousness, eternal life, salvation, obedience, service,
    community, stewardship, creation, sovereignty
- User or caretaker picks topic focus for the week (via voice or app)
- Daily verse + brief reflection/message about the verse
- Polly reads it each morning automatically or on command

---

## Feature 6: Weather (Real + Almanac)

- Trigger: "What's the weather?" / "Do I need an umbrella?"
- **Real weather** from Weather.gov API (free, no key needed)
- Auto-detects location from device IP via geolocation
- Current conditions + today's forecast + tomorrow + Farmer's Almanac fun fact
- Falls back to pre-loaded almanac forecasts if API fails
- 2-hour cache per IP to minimize API calls

---

## Feature 7: Personalized Music (Suno AI)

- Takes legacy questions + answers from the user's story
- Generates personalized songs from their life experiences
- User picks genre preference (country, gospel, folk, jazz, etc.)
- Frequency: once a month or based on subscription tier
- Example: A country song about grandma growing up on the farm
- Delivered via app and/or played through the device
- Emotional keepsake tied directly to their legacy book content

---

## Feature 8: Jokes & Personality

- 1,040+ jokes + 100 kid jokes (fart, poop, dinosaur, unicorn)
- Casual conversation triggers: "Tell me a joke", "Make me laugh", "Cheer me up"
- Kid jokes: "Tell me a kid joke", "Tell me a fart joke", "Tell me a dinosaur joke"
- SSML punchline timing with 2-second dramatic pause
- Seasonal rotation keeps it fresh
- This is what makes Polly feel alive — not just a tool, but a companion

---

## Feature 8b: Parrot Sounds & Ambient Personality

- 5 short squawks (0.6-1.8s) + 3 parakeet chatter clips (~50s each)
- **Startup squawk**: plays when device connects (confirms Polly is ready)
- **Post-response squawk**: 50% chance after any TTS response
- **Idle squawk**: random every 5-60 minutes (configurable)
- **Chatter**: random every 15 min-4 hours (configurable)
- **Quiet Hours**: Polly goes to sleep at bedtime, wakes up in the morning (configurable)
- **Snooze**: temporarily quiet all sounds from web portal (30 min, 1 hr, 2 hr, 8 hr)
- **Interruptible**: "Be quiet", "Shut up", "Hush", "Shush" with sassy responses
- All sounds server-side — no firmware changes needed

---

## Feature 9: Help & Navigation

- Voice-driven commands:
  - "What can you do?" / "Help" → capabilities overview
  - "Repeat that" / "Say that again" → replays last response
  - "Skip" / "Next question" / "I don't know" → moves on
  - "Stop" / "I'm done" / "That's enough" → ends current interaction
  - "Be quiet" / "Hush" → silences Polly's squawking
  - "What time is it?" → current time
  - "What day is it?" → current date
  - "Thank you" → polite response
  - "Who is [name]?" → family tree lookup
  - "Goodbye" / "Good night" → farewell
- Discoverable and forgiving — designed for elderly users

---

## Feature 9b: Family Message Board

- **Status updates**: "Dad is going to work" / "I'm going for a walk"
- **Direct messages**: "Tell Dad I'm going to the store"
- **Check messages**: "Any messages?" / "Read my messages"
- **Person queries**: "Where is Dad?"
- **Clear by person**: "Dad is home" (clears dad's messages)
- **Clear all**: "Clear the board"
- Messages auto-expire after 24 hours
- Web message board at /web/messages (send/delete/clear)
- Family tree names loaded for person recognition

---

## Feature 10: Web & Mobile App (Caretaker Portal)

### For Caretakers / Family
- Edit transcriptions (fix misspelled names, pronunciation errors, clean up flow)
- Manage medication schedules (add/remove/edit)
- View medication compliance history
- Choose Bible verse topics for the week
- View and export legacy book progress

### Camera → Memory Storage
- Take photo of wall/shelf/drawer
- AI identifies items → assign locations → bulk import to memory

### For the Primary User (simplified view)
- Listen to their stories
- View their book progress
- Play their personalized songs

---

## Multi-User Model

- **Device = one primary user** (the elder whose story it is)
- Others can contribute stories — Polly asks for their name
- All contributions tagged by speaker, feed into the legacy book
- Caretakers manage everything via the app
- Multiple family members can have app access

---

## Subscription Tiers (Proposed)

| Feature | Basic ($20/mo) | Premium ($29/mo) | Notes |
|---|---|---|---|
| Memory Storage | Unlimited | Unlimited | Core feature |
| Question Mode | 5 questions/week | 20 questions/week | + follow-ups |
| Story Mode | 15 min/week | 30+ min/week | WAV saved |
| WAV Button | Yes | Yes | |
| Medication Reminders | 3 reminders | Unlimited | |
| Bible Verse | Daily | Daily + topic choice | |
| Farmer's Almanac | Weekly | Weekly | |
| Jokes | Yes | Yes | |
| Personalized Song | — | 1/month (Suno) | Premium perk |
| Web/Mobile App | View only | Full edit access | |
| Legacy Book Export | Annual | Quarterly + on-demand | |

---

## Tech Stack (Current → Target)

### Deployed Stack (Live at polly-connect.com)
- **Hardware:** ESP32-S3 (breadboard + Waveshare ESP32-S3-AUDIO)
- **Server:** AWS EC2 + Python 3.11 + FastAPI + Uvicorn
- **STT:** Google Cloud STT (free tier)
- **TTS:** AWS Polly (female voice, SSML support)
- **Database:** SQLite (22 tables, WAL mode)
- **AI:** OpenAI GPT-4o (Vision photo scan, chapter drafts), GPT-3.5-turbo (follow-ups)
- **Weather:** Weather.gov API (free) + IP geolocation
- **SSL:** Let's Encrypt via certbot + Nginx reverse proxy
- **Domain:** polly-connect.com (GoDaddy)
- **Wake word:** Server-side VAD (RMS threshold detection)
- **WiFi Provisioning:** AP captive portal ("Polly-Setup") with DNS redirect

---

## Architecture Overview

```
[ ESP32 Parrot Device ]
        |
        |  audio / wake word / button
        v
[ Brain API — AWS Cloud ]
        |
        ├── Amazon Transcribe (speech → text)
        ├── Amazon Polly (text → speech)
        ├── OpenAI API (reasoning, writing, vision)
        ├── Suno API (music generation)
        |
        ├── S3 (WAV, transcripts, books, songs)
        ├── DynamoDB (memory, Q&A, meds, profiles)
        |
        v
[ Web / Mobile App ]
        |
        ├── Caretaker portal (edit, manage, view)
        └── Camera → AI item recognition → memory
```

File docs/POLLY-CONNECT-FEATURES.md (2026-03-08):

# Polly Connect - Complete Feature Reference

**Version:** March 2026
**Live URL:** https://polly-connect.com
**Status:** Deployed and operational

---

## What Is Polly Connect?

Polly Connect is a voice-powered companion device and cloud platform designed for elderly care and family legacy preservation. A small ESP32-S3 device sits in the home and listens for voice commands. It tells jokes, reads bible verses, asks guided questions, records family stories, manages medication reminders, and over time builds a printed family legacy book from the conversations it captures.

The system has three audiences:
- **The elder** — talks to Polly like a companion, shares stories, hears jokes and scripture
- **The caretaker** — manages medications, reviews transcripts, monitors engagement via web portal
- **The family** — views stories, photos, and book progress through a read-only family portal

---

## Hardware

### Breadboard Prototype (ESP32-S3)
- **Board:** ESP32-S3-WROOM-1 with 8MB PSRAM and 16MB flash
- **Microphone:** INMP441 I2S MEMS mic (GPIO 4/5/6)
- **Speaker:** MAX98357A I2S amplifier (GPIO 10/11/12)
- **Status LED:** GPIO 48 (solid on during recording, blinks on wake)
- **Story Button:** GPIO 0 (BOOT button, doubles as story record toggle during runtime)
- **Power:** USB-C, 5V via AMS1117-3.3 regulator
- **Connectivity:** WiFi (2.4GHz), streams audio to cloud server via WebSocket

### Waveshare ESP32-S3 AI Smart Speaker
- **Board:** Waveshare ESP32-S3-AUDIO with ES7210 (4-ch ADC), ES8311 (DAC), TCA9555 (I/O expander)
- **I2C bus:** SDA=GPIO11, SCL=GPIO10 (shared for ES7210, ES8311, TCA9555)
- **I2S bus:** MCLK=GPIO12, BCLK=GPIO13, WS=GPIO14, DOUT=GPIO16, DIN=GPIO15
- **Buttons:** K1/+ (story record), K2/SET, K3, BOOT, Reset — via TCA9555 I/O expander
- **Story Button:** K1/+ (TCA9555 Port 1 bit 1) — press to start/stop story recording
- **WiFi Provisioning:** AP captive portal ("Polly-Setup"), DNS redirect, force-provision via BOOT hold

### Custom PCB (In Progress)
- KiCad 9.0.7 schematic verified and complete
- 70mm x 50mm 2-layer board
- All components on 5-pin breakout headers for mic and amp
- Boot button (GPIO0) and Reset button (EN)
- USB-C for power and firmware flashing

---

## Voice Features

### Wake Word Detection
- Server-side VAD (Voice Activity Detection) with RMS threshold monitoring
- ESP32 streams continuous audio to server; server detects speech onset
- Pre-roll buffer captures 1.5 seconds before trigger so nothing is missed
- 3-second cooldown after responses to prevent speaker feedback loops

### Speech-to-Text
- **Engine:** Google Cloud STT (free tier: 60 minutes/month)
- Real-time transcription of voice commands and story answers
- Segment-based transcription during long recordings (3s silence gaps)

### Text-to-Speech
- **Engine:** AWS Polly (female voice)
- Audio sent back to ESP32 as chunked base64 over WebSocket
- Plays through MAX98357A speaker

### Conversation Modes
| Mode | Trigger | Behavior |
|---|---|---|
| COMMAND | Wake word | Normal mode — listens for commands, 2s silence timeout |
| STORY_PROMPT | "Ask me a question" | Polly asks a guided question, waits for answer (8s timeout) |
| STORY_LISTEN | "Record my story" | Free-form storytelling, Polly just listens (8s timeout) |
| FOLLOWUP_WAIT | After story answer | ECHO-BRIDGE-INVITE follow-up question (8s timeout) |
| STORY_RECORD | Button press | Full WAV recording with live transcription (15s timeout, 30min max) |
| AWAITING_RELATIONSHIP | New speaker intro | Asks "How do you know [owner]?" (8s timeout) |

### Voice Commands
- "Tell me a joke" — random joke from 1,040-joke database
- "Tell me a kid joke" / "Tell me a fart joke" — 100 silly kid jokes
- "Read me a bible verse" / "Verse about hope" — daily verse from 336-verse collection
- "What's the weather" / "Do I need an umbrella?" — real local weather + almanac fun fact
- "Ask me a family question" — guided family question (story mode)
- "Tell me a story" / "Record my story" — free-form story mode
- "How many stories do I have?" — story progress
- "My keys are on the counter" / "Where are my keys?" — item memory
- "What are my medications?" / "I took my medicine" — medication info + logging
- "Tell Dad I'm going to the store" — leave a message
- "Dad is going to work" / "I'm going for a walk" — status update
- "Any messages?" — check message board
- "Where is Dad?" — person location query
- "Dad is home" — clear person's messages
- "Clear the board" — clear all messages
- "Who is Mia?" — family tree lookup
- "What time is it?" / "What day is it?" — time and date
- "Be quiet" / "Hush" / "Shut up" — silence squawking
- "My name is [name]" — speaker introduction and identity tracking
- "Help" / "What can you do?" — capabilities overview
- K1/+ button press — start/stop WAV story recording (up to 30 minutes)

---

## Story Collection System

### How Stories Are Captured

**Voice-triggered (always available):**
1. User says "ask me a question" or "record my story"
2. Polly enters conversational mode (no wake word needed between exchanges)
3. User speaks; audio is transcribed in real time
4. Transcript saved to database

**Button-triggered WAV recording (GPIO0):**
1. User or caretaker presses the story button
2. LED turns solid on; Polly announces "Recording started"
3. ALL audio is captured as a WAV file while also transcribing in segments
4. Press button again to stop (or auto-stops at 30 minutes)
5. WAV file saved to server + full transcript saved to database
6. Original voice recording available for playback on web portal

### ECHO-BRIDGE-INVITE Follow-Up Engine
After each story answer, Polly generates a natural follow-up using behavioral psychology:

- **ECHO** — Reflects back a keyword from what the person said ("The kitchen table...")
- **BRIDGE** — Connects emotionally ("That sounds like it meant something special.")
- **INVITE** — Asks a follow-up question ("What did it smell like when she was cooking?")

Follow-ups are template-based (always free) with optional AI enhancement when OpenAI API key is configured. Up to 3 follow-ups per question, then a warm closing.

### Memory Extraction
Every story answer is automatically analyzed and tagged:
- **People mentioned** (family words + proper names)
- **Locations** (place keywords with context)
- **Emotions** (12 categories: joy, love, nostalgia, sadness, fear, anger, pride, gratitude, humor, courage, peace, adventure)
- **Life phase** (childhood, adolescence, young adult, adult, midlife, elder)
- **Jungian bucket** (see Legacy Book section below)

No machine learning required — pure keyword heuristics that run instantly.

---

## Legacy Book System

### The Jungian Narrative Arc (Hero's Journey)
Every memory is automatically classified into one of six narrative stages:

| Stage | What It Covers | Example |
|---|---|---|
| Ordinary World | Everyday life, family rhythms, childhood | "What did a normal day look like?" |
| Call to Adventure | Moments that changed everything | "When did you realize things were different?" |
| Crossing Threshold | Big decisions, no going back | "What was the hardest decision you made?" |
| Trials, Allies & Enemies | Hard times, who helped, who didn't | "Who stood by you when it got tough?" |
| Transformation | How you changed, what you became | "How were you different after all that?" |
| Return with Knowledge | Wisdom, lessons, legacy | "What would you tell your grandkids?" |

### Intelligent Question Selection
The Engagement Tracker monitors which narrative buckets and life phases have gaps:
- If "transformation" stories are thin, Polly asks deeper reflective questions
- If "childhood" is well-covered but "young adult" is empty, Polly steers there
- Perspective rotation after 10+ memories: revisit stories from emotion, relationship, lesson, and legacy angles

### Chapter Assembly
The Book Builder groups memories into 14 chapter templates:
- "Where It All Started" (ordinary world / childhood)
- "The Kitchen Table" (ordinary world / childhood)
- "Growing Up" (ordinary world / adolescence)
- "When Things Changed" (call to adventure / adolescence)
- "Stepping Out" (call to adventure / young adult)
- "The Decision" (crossing threshold / young adult)
- "Love and Beginnings" (crossing threshold / young adult)
- "The Hard Years" (trials / adult)
- "Who Stood By Me" (trials / adult)
- "Raising a Family" (trials / adult)
- "How I Changed" (transformation / adult)
- "Finding My Way" (transformation / midlife)
- "What I Know Now" (return with knowledge / reflection)
- "For the Grandkids" (return with knowledge / reflection)

Each chapter needs 5+ memories to be marked "ready." Large groups automatically split into parts. Chapters can always receive more memories and be regenerated.

### AI Chapter Draft Generation
When a chapter has enough memories, one click generates a full narrative draft:
- OpenAI GPT-4o weaves 5-10 memories into 7-10 paragraphs of prose
- Preserves the speaker's voice and emotional tone
- Adds gentle transitions between memories
- Opens with scene-setting, closes with reflection
- Cost: ~$0.02-0.05 per chapter, under $1 for a full book

### PDF Book Export
Print-ready 6x9 inch PDF generated on demand:
- **Trim size:** 6" x 9" (standard memoir format)
- **Margins:** gutter 0.85", outside 0.65", top/bottom 0.75" (KDP/Lulu safe for soft and hardcover)
- **Layout:** title page, copyright, optional dedication, table of contents, chapters, back matter
- **Typography:** Times Roman, justified body text, indented paragraphs
- **QR codes:** Each chapter can include a scannable code linking to the original voice recording
- **Page numbers:** Centered bottom, skipped on title/copyright
- **Compatible with:** Amazon KDP (via Book Bolt), Lulu, IngramSpark, Blurb

### Service Tiers
| Tier | Price | What's Included |
|---|---|---|
| Free (with device) | $0 | Voice capture, web dashboard, transcript review, story progress |
| Legacy Book | $49-99 | AI chapters, PDF export, 1 printed softcover book |
| Premium Package | $149-249 | Editor review, custom cover, 3 hardcover copies, QR audio companion |

---

## Medication Reminder System

### Setup
- Add medications via web portal: name, dosage, times, active days
- Accepts flexible time input: "8am", "2:30 PM", "14:00"
- Day-of-week checkboxes for active days

### Voice Reminders
- Background scheduler checks medication times every minute
- At scheduled time: plays a squawk sound (random 1-of-5) + TTS announcement
- Pushed directly to ESP32 via WebSocket — no user action needed
- Tenant-aware: only sends to devices belonging to the medication's tenant
- Dedup prevents duplicate sends within the same minute

### Dashboard Alerts
- Live medication status on dashboard (polls every 60 seconds)
- Color-coded badges: OVERDUE (red), Soon (yellow), Scheduled (green), Not Today (gray)
- Countdown minutes to next dose

### Calendar Export
- Download .ics file for phone calendar import
- RRULE-based recurring events with 5-minute advance alarms
- Works with Apple Calendar, Google Calendar, Outlook

---

## Web Portal

**URL:** https://polly-connect.com/web/
**Design:** Mobile-first, Tailwind CSS, responsive
**Auth:** Cookie-based sessions, 72-hour duration

### Pages

| Page | URL | Who Can Access | Purpose |
|---|-----|---|---|
| Login | /web/login | Everyone | Email + password login |
| Register | /web/register | Everyone | Create account + household |
| Family Login | /web/family | Everyone | 6-digit code + name (no password) |
| Dashboard | /web/dashboard | All logged in | Stats, recent stories, med alerts, book progress |
| Stories | /web/stories | All logged in | Story list with audio playback, edit links |
| Story Edit | /web/stories/{id}/edit | All logged in | Edit transcript and speaker name |
| Legacy Book | /web/book | All logged in | Book progress, arc coverage, chapter outline, PDF export |
| Book Chapters | /web/book/chapters | All logged in | Chapter list with status badges and memory previews |
| Chapter Detail | /web/book/chapters/{n} | All logged in | Source memories, AI draft editor, generate/regenerate |
| Book Export | /web/book/export | All logged in | Download 6x9 print-ready PDF |
| Transcriptions | /web/transcriptions | All logged in | Review/verify/correct transcripts |
| Photos | /web/photos | All logged in | Photo gallery with upload, tags, captions |
| Memory | /web/memory | All logged in | Item storage + AI photo scan |
| Medications | /web/medications | All logged in | Add/edit/delete medications |
| Med Edit | /web/medications/{id}/edit | Owner only | Edit medication details |
| Med Calendar | /web/medications/calendar | All logged in | Download .ics calendar |
| Setup | /web/setup | Owner only | Owner/caretaker names and emails |
| Settings | /web/settings | Owner only | Preferences, squawk intervals, quiet hours, snooze, family codes |
| Messages | /web/messages | All logged in | Family message board (send/delete/clear) |
| Devices | /web/devices | Owner only | Manage Polly devices + API keys |

### AI Photo Scan
- Upload a photo of a shelf, wall, drawer, etc.
- OpenAI GPT-4o Vision identifies specific items ("claw hammer" not "hammer")
- Items appear as editable cards — user can rename before saving
- Location field with autocomplete from previously-used locations
- Batch save stores all items to Polly's memory
- Cost: ~$0.005-0.01 per scan

### Family Access
- Owner generates a 6-digit family access code in Settings
- Family members log in with just their name + the code (no email/password)
- Family sessions are read-only — can view stories, photos, book progress
- Cannot edit medications, settings, or device management

---

## Multi-Tenant Architecture

- Each household is a "tenant" with isolated data
- **Tables:** tenants, accounts, web_sessions
- **tenant_id** on all 15 data tables (not shared data like bible_verses)
- Per-device API keys for ESP32 authentication
- Backward compatible: global POLLY_API_KEY falls back to tenant #1
- SQLite with WAL mode for concurrent access
- Password hashing: SHA-256 with random salt

---

## Infrastructure

### Server
- **AWS EC2** instance at 3.14.130.158
- **OS:** Amazon Linux
- **Runtime:** Python 3.11 + FastAPI + Uvicorn
- **Database:** SQLite (21 tables, WAL mode)
- **Process:** systemd service (auto-restart)

### Domain and SSL
- **Domain:** polly-connect.com (GoDaddy, auto-renews Jan 2027)
- **SSL:** Let's Encrypt via certbot (auto-renewing, expires May 2026)
- **Proxy:** Nginx reverse proxy (port 80/443 to :8000)

### Deployment
```
git push origin master
ssh into EC2
cd /opt/polly-connect && git pull origin master
sudo systemctl restart polly-connect
```

---

## Parrot Sounds & Ambient Personality

- 5 short squawks (0.6-1.8s) + 3 parakeet chatter clips (~50s each)
- Startup squawk on device connect (confirms Polly is ready)
- Post-response squawk: 50% chance after any TTS response
- Idle squawk interval: configurable (5-60 minutes, default 10)
- Chatter interval: configurable (15 min-4 hours, default 45 min)
- **Quiet Hours**: automatic bedtime/wake schedule (default 9 PM-7 AM)
- **Snooze**: temporarily quiet all sounds from web portal (30 min / 1 hr / 2 hr / 8 hr)
- **Interruptible**: "Be quiet", "Shut up", "Hush", "Shush" with sassy responses
- All sounds auto-converted to 16kHz mono, volume reduced to 30%
- All server-side — no firmware changes needed

---

## Family Message Board

- Voice status updates: "Dad is going to work" / "I'm going for a walk"
- Voice messages: "Tell Dad I'm going to the store"
- Voice queries: "Any messages?" / "Where is Dad?"
- "Dad is home" clears dad's messages from board
- Messages auto-expire after 24 hours
- Web message board at /web/messages (send/delete/clear)
- Family tree names loaded for person recognition
- Status vs. direct message readback formatting

---

## Database Schema (22 Tables)

| Table | Purpose |
|---|---|
| tenants | Household/account grouping |
| accounts | User login credentials |
| web_sessions | Active browser sessions |
| user_profiles | Owner preferences and settings |
| devices | ESP32 devices with API keys |
| stories | Voice transcripts and WAV recordings |
| story_tags | Tags on stories (speaker, topic) |
| memories | Structured memories (tagged with bucket, life phase, emotions) |
| memory_verifications | Audit trail for verified memories |
| chapter_drafts | AI-generated book chapter text |
| question_sessions | Which questions have been asked/answered |
| medications | Medication names, dosages, schedules |
| medication_logs | Medication reminder delivery log |
| items | Stored items (location memory) |
| photos | Uploaded photos with captions and tags |
| family_members | Known family members and relationships |
| sessions | Voice conversation sessions |
| joke_history | Which jokes have been told |
| bible_verses | 336 verses (shared, not per-tenant) |
| almanac_weather | 52-week weather forecasts (shared) |
| family_messages | Message board (from, to, message, expiry) |

---

## Data Content

| Content Type | Count | Source |
|---|---|---|
| Jokes | 1,040 | Curated JSON files |
| Family Questions | 70 | Curated, Jungian-tagged |
| General Questions | 312 | Curated JSON files |
| Bible Verses | 336 | Curated, topic-categorized |
| Almanac Forecasts | 52 | Weekly forecasts |

---

## Key Technical Files

| File | Purpose |
|---|---|
| server/main.py | FastAPI app, service wiring, static mount |
| server/config.py | Settings, .env loading, timezone |
| server/core/database.py | 21 tables, migrations, all CRUD |
| server/core/command_processor.py | All voice intent handling |
| server/core/conversation_state.py | 6 conversation modes, timeouts |
| server/api/audio.py | WebSocket audio streaming (continuous + event-based) |
| server/api/web.py | All web portal routes |
| server/core/echo_bridge_invite.py | ECHO-BRIDGE-INVITE follow-up engine |
| server/core/narrative_arc.py | Jungian arc tracking, question guidance |
| server/core/memory_extractor.py | Auto-tagging of people, emotions, life phase |
| server/core/book_builder.py | Chapter assembly + AI draft generation |
| server/core/book_pdf.py | 6x9 PDF export with QR codes |
| server/core/story_recorder.py | WAV recording session manager |
| server/core/engagement.py | Question selection + progress tracking |
| server/core/vision.py | OpenAI GPT-4o Vision for photo scanning |
| server/core/family_identity.py | Speaker intro + relationship tracking |
| server/core/web_auth.py | Session handling, login, family access |
| server/core/medications.py | Medication scheduler + voice push |
| server/core/squawk.py | Parrot sounds, intervals, quiet hours, snooze |
| server/core/intent_parser.py | Voice command recognition (35+ intents) |
| firmware/polly-s3-wakeword/main/main.c | ESP32 firmware — breadboard (INMP441 + MAX98357A) |
| firmware/polly-waveshare-s3/main/main.c | ESP32 firmware — Waveshare (ES7210 + ES8311 + TCA9555 + K1 button) |

---

## What's Next

### Immediate (Pre-Trial)
- Flash second Waveshare device for family deployment
- Full end-to-end voice pipeline test (test_A automated suite)
- Family trial: real story capture with Grandma

### Short Term
- Install OpenAI package on EC2 for AI chapter generation
- Test print via Book Bolt / KDP
- Audio companion web page behind QR codes

### Medium Term
- KiCad PCB routing and fabrication
- Lulu API integration for automated print-on-demand
- Cover template generator with family photos
- Mobile app wrapper (PWA or native)
- Suno AI personalized music generation

### Long Term
- Multi-device household support
- Video message recording
- Integration with smart home (Home Assistant)
- Subscription model for ongoing story capture + annual book updates

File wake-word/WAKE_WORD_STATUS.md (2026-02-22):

# Wake Word Training Status

## Current State: v3 Model Working!

| Version | Recall | False Positive Rate | Notes |
|---|---|---|---|
| v1 | 0% | 0% | Said "no" to everything |
| v2 | 100% | 100% | Said "yes" to everything |
| **v3** | **57% (55/96)** | **8% (12/149)** | **Usable!** |

**v3 training stats (from Colab):**
- Accuracy: 74%, Recall: 73.2%, False Positives/Hour: 0.0
- 3 training sequences (10000 + 1000 + 1000 steps)
- Trained with 5000 synthetic Piper TTS samples + 96 real positives
- 4 Piper voices: libritts_r (904 speakers), lessac, amy, cori
- Augmented across 254 batches with room impulse responses + background noise

**v3 local test results:**
- Positive avg score: 0.494, most detections score 0.8+
- Negative avg score: 0.075, most score 0.001
- 12 false positives worth investigating (could be phonetically similar phrases)
- Threshold 0.5 — lowering to 0.4 would improve recall but increase false positives

### Files on PC
- `hey_polly.onnx` + `hey_polly.onnx.data` — v3 model (working)
- `test_model.py` — Local test script (`py test_model.py`)
- `COLAB_CLEAN_SLATE.md` — Battle-tested Colab training guide (v3)
- `positive/` — 96 real "Hey Polly" samples
- `negative/` — 149 real non-wake-word samples
- `record_samples.py` / `analyze_samples.py` — Sample recording/analysis tools
- `hey_polly_samples.zip` — Zipped samples for Colab upload

### Google Drive Backup
- `My Drive/hey_polly_training/` — Model + training log + augmented data

## Hardware (ESP32-S3-WROOM-1-N16R8)
- **Mic:** INMP441 — SCK=GPIO6, WS=GPIO5, SD=GPIO4
- **Speaker:** MAX98357A — BCLK=GPIO12, LRC=GPIO11, DIN=GPIO10
- **LED:** GPIO48
- **Flash:** 16MB, **PSRAM:** 8MB Octal

## Firmware Options

### Option A: Server-Side Wake Word (Fastest to Deploy)
The .onnx model can't run directly on ESP32-S3 (OpenWakeWord is too heavy). Instead:
1. ESP32 streams audio to Polly server over WiFi
2. Server runs OpenWakeWord with `hey_polly.onnx`
3. On detection → server signals ESP32 to start recording command
4. Server runs Whisper STT → processes → returns TTS audio

**Pros:** Uses the model we just trained, no conversion needed
**Cons:** Requires WiFi connection, slight latency, server must be running

### Option B: ESPHome + microWakeWord (Best On-Device)
The ESPHome config (`firmware/polly-esp32-esphome/polly-voice-assistant.yaml`) already has microWakeWord set up with "okay_nabu". To use a custom "Hey Polly":
1. Retrain using microWakeWord's training pipeline (separate from OpenWakeWord)
2. Produces a .tflite model optimized for ESP32-S3
3. Load custom model in ESPHome config
4. Integrates with Home Assistant voice pipeline

**Pros:** Fully on-device wake word, low latency, works offline
**Cons:** Requires retraining with microWakeWord pipeline, needs Home Assistant

### Option C: ESP-IDF Standalone (Current Firmware)
The ESP-IDF firmware (`firmware/polly-s3-wakeword/`) uses ESP-SR WakeNet with "Hi ESP":
- Could swap to server-side detection (Option A hybrid)
- ESP-SR WakeNet uses its own model format, can't load .onnx directly
- Self-contained, talks directly to Polly FastAPI server

## What Needs to Happen Next

### Step 1: Choose Deployment Path
- **Option A** is fastest — just add an audio streaming endpoint to the server
- **Option B** is best long-term — on-device detection, no server dependency for wake word

### Step 2: Server Endpoint (for Option A or as fallback)
- Add WebSocket or HTTP streaming endpoint to FastAPI server
- Run OpenWakeWord with `hey_polly.onnx` on incoming audio
- After detection: Whisper STT → process query → TTS response

### Step 3: Flash and Test
- Update WiFi credentials in firmware for home network
- Install ESP-IDF v5.4.x (if using Option C) or ESPHome (if Option B)
- Build, flash, test end-to-end

### Step 4: Improve Model (Optional)
- Record more samples (200+ positive, 300+ negative)
- Investigate the 12 false positive negative samples
- Retrain with more Piper voices and higher augmentation rounds
- Target: 80%+ recall with <3% false positives

## Colab Training Guide
See `COLAB_CLEAN_SLATE.md` for the full, tested Colab notebook guide. All dependency issues and patches are documented and built into the cells.

## Recording More Samples
```bash
cd C:\Users\big_g\Desktop\polly-connect\wake-word
python record_samples.py positive    # say "Hey Polly" naturally
python record_samples.py negative    # say other phrases, background noise
python record_samples.py review      # listen back to recordings
python analyze_samples.py            # check quality
```

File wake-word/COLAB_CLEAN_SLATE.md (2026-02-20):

# Hey Polly Wake Word Training — Clean Slate v3

> Start a **brand new Colab notebook**. Paste each cell in order.
> Every phase saves a checkpoint to Google Drive so you never lose progress.

---

## Phase 1: Google Drive + System Setup

### Cell 1 — Mount Google Drive FIRST
```python
from google.colab import drive
drive.mount('/content/drive')

import os
SAVE = "/content/drive/MyDrive/hey_polly_training"
os.makedirs(SAVE, exist_ok=True)
print(f"Save dir: {SAVE}")
print("Everything important gets backed up here!")
```

### Cell 2 — Check environment
```python
!python --version
!nvidia-smi --query-gpu=name,memory.total --format=csv,noheader 2>/dev/null || echo "CPU-only (slower but works)"
```

### Cell 3 — Install ALL system dependencies at once
```python
%%bash
apt-get update -qq > /dev/null 2>&1
apt-get install -y -qq espeak-ng git-lfs ffmpeg > /dev/null 2>&1
espeak-ng --version
git lfs version
echo "System deps OK"
```

### Cell 4 — Install ALL Python dependencies at once
```python
import sys
!{sys.executable} -m pip install -q \
    piper-tts \
    openwakeword \
    onnxruntime \
    numpy \
    soundfile \
    audiomentations \
    scipy \
    torch \
    torchaudio \
    speechbrain \
    torchinfo \
    torchmetrics \
    torch_audiomentations \
    pronouncing \
    mutagen \
    acoustics \
    onnxscript \
    datasets \
    huggingface_hub \
    tensorflow \
    tqdm \
    pyyaml

# Verify the two critical imports
from piper import PiperVoice
print("piper-tts OK")
from openwakeword.model import Model
print("openwakeword OK")
```

> **If openwakeword fails to import**, restart the runtime (Runtime → Restart runtime),
> then re-run Cell 1 (Drive mount) and Cell 4 only.

---

## Phase 2: Download Voice Models

### Cell 5 — Download Piper voice models
```python
from huggingface_hub import hf_hub_download
import os, shutil

voices_dir = "/content/voices"
os.makedirs(voices_dir, exist_ok=True)

models = [
    ("rhasspy/piper-voices", "en/en_US/lessac/medium/en_US-lessac-medium.onnx"),
    ("rhasspy/piper-voices", "en/en_US/lessac/medium/en_US-lessac-medium.onnx.json"),
    ("rhasspy/piper-voices", "en/en_US/libritts_r/medium/en_US-libritts_r-medium.onnx"),
    ("rhasspy/piper-voices", "en/en_US/libritts_r/medium/en_US-libritts_r-medium.onnx.json"),
    ("rhasspy/piper-voices", "en/en_US/amy/medium/en_US-amy-medium.onnx"),
    ("rhasspy/piper-voices", "en/en_US/amy/medium/en_US-amy-medium.onnx.json"),
    ("rhasspy/piper-voices", "en/en_GB/cori/medium/en_GB-cori-medium.onnx"),
    ("rhasspy/piper-voices", "en/en_GB/cori/medium/en_GB-cori-medium.onnx.json"),
]

for repo_id, filename in models:
    basename = filename.split("/")[-1]
    print(f"Downloading {basename}...")
    path = hf_hub_download(repo_id=repo_id, filename=filename, local_dir=voices_dir)
    flat_path = f"{voices_dir}/{basename}"
    if os.path.abspath(path) != os.path.abspath(flat_path):
        shutil.copy2(path, flat_path)
    print(f"  {os.path.getsize(flat_path):,} bytes")

print("\nAll voice models OK")
```

---

## Phase 3: Clone Repos + Fix Resource Models

### Cell 6 — Clone piper-sample-generator
```python
!rm -rf /content/piper-sample-generator
!git clone --depth 1 https://github.com/rhasspy/piper-sample-generator.git /content/piper-sample-generator
print("piper-sample-generator OK")
```

### Cell 7 — Clone OpenWakeWord + copy resource models from pip package
```python
import os, shutil

# Clone the repo (for training scripts)
!rm -rf /content/openWakeWord
!git clone --depth 1 https://github.com/dscripka/openWakeWord.git /content/openWakeWord

# Git LFS doesn't reliably pull the resource models on Colab.
# Instead, copy them from the pip-installed openwakeword package.
import openwakeword
pip_res = os.path.join(os.path.dirname(openwakeword.__file__), "resources", "models")
git_res = "/content/openWakeWord/openwakeword/resources/models"
os.makedirs(git_res, exist_ok=True)

print("Copying resource models from pip package to git clone:")
for f in os.listdir(pip_res):
    shutil.copy2(f"{pip_res}/{f}", f"{git_res}/{f}")
    print(f"  {f}: {os.path.getsize(f'{git_res}/{f}'):,} bytes")

# Verify the two critical files
for needed in ["melspectrogram.onnx", "embedding_model.onnx"]:
    path = f"{git_res}/{needed}"
    assert os.path.exists(path) and os.path.getsize(path) > 1000, f"MISSING: {needed}"

print("\nResource models OK!")
```

### Cell 8 — Install OpenWakeWord training extras
```python
import sys
!cd /content/openWakeWord && {sys.executable} -m pip install -q ".[train]"
print("Training extras installed OK")
```

---

## Phase 4: Verify Piper TTS Works

### Cell 9 — Generate 5 test samples
```python
import sys, os
sys.path.insert(0, '/content/piper-sample-generator')
from generate_samples import generate_samples_onnx

test_dir = "/content/test_piper"
os.makedirs(test_dir, exist_ok=True)

print("Generating 5 test samples...")
generate_samples_onnx(
    text=["hey polly"],
    output_dir=test_dir,
    model="/content/voices/en_US-lessac-medium.onnx",
    max_samples=5,
    length_scales=(0.75, 1.0, 1.25),
    noise_scales=(0.667,),
    noise_scale_ws=(0.8,),
)

files = sorted(os.listdir(test_dir))
print(f"\nGenerated {len(files)} files:")
for f in files:
    print(f"  {f} — {os.path.getsize(f'{test_dir}/{f}'):,} bytes")

assert len(files) >= 5, f"FAILED: Expected 5 files, got {len(files)}"
print("\n=== PIPER TTS WORKS! ===")
```

### Cell 10 — Listen to a sample
```python
import IPython.display as ipd
ipd.Audio("/content/test_piper/0.wav")
```

> **STOP if Cell 9 failed.** Don't continue until Piper generates files.

---

## Phase 5: Generate Full Synthetic Dataset

### Cell 11 — Generate ~5000 samples
```python
import sys, os, shutil
sys.path.insert(0, '/content/piper-sample-generator')
from generate_samples import generate_samples_onnx

output_dir = "/content/synthetic_positive"
if os.path.exists(output_dir):
    shutil.rmtree(output_dir)

counter = 0

def gen(model_path, n, length_scales, noise_scales, noise_ws, max_spk=None):
    global counter
    temp = "/content/_temp"
    if os.path.exists(temp): shutil.rmtree(temp)
    os.makedirs(temp)
    kw = dict(text=["hey polly"], output_dir=temp, model=model_path,
              max_samples=n, length_scales=length_scales,
              noise_scales=noise_scales, noise_scale_ws=noise_ws)
    if max_spk: kw["max_speakers"] = max_spk
    generate_samples_onnx(**kw)
    os.makedirs(output_dir, exist_ok=True)
    for f in sorted(os.listdir(temp)):
        os.rename(f"{temp}/{f}", f"{output_dir}/{counter}.wav")
        counter += 1
    shutil.rmtree(temp)

print("=== libritts_r (4000 samples) ===")
gen("/content/voices/en_US-libritts_r-medium.onnx", 4000,
    (0.75, 0.85, 1.0, 1.15, 1.3), (0.667, 0.8), (0.8,), max_spk=200)
print(f"  Total: {counter}")

print("\n=== lessac (350 samples) ===")
gen("/content/voices/en_US-lessac-medium.onnx", 350,
    (0.7,0.8,0.9,1.0,1.1,1.2,1.3,1.5), (0.5,0.667,0.8,1.0), (0.6,0.8,1.0))
print(f"  Total: {counter}")

print("\n=== amy (350 samples) ===")
gen("/content/voices/en_US-amy-medium.onnx", 350,
    (0.7,0.8,0.9,1.0,1.1,1.2,1.3,1.5), (0.5,0.667,0.8,1.0), (0.6,0.8,1.0))
print(f"  Total: {counter}")

print("\n=== cori (300 samples) ===")
gen("/content/voices/en_GB-cori-medium.onnx", 300,
    (0.7,0.8,0.9,1.0,1.1,1.2,1.3,1.5), (0.5,0.667,0.8,1.0), (0.6,0.8,1.0))

print(f"\n{'='*40}")
print(f"TOTAL: {counter} synthetic samples")
```

### Cell 12 — CHECKPOINT: Save synthetic samples to Drive
```python
import shutil, os
SAVE = "/content/drive/MyDrive/hey_polly_training"

# Zip for faster copy
!cd /content && zip -q -r synthetic_positive.zip synthetic_positive/
shutil.copy2("/content/synthetic_positive.zip", f"{SAVE}/synthetic_positive.zip")
size = os.path.getsize(f"{SAVE}/synthetic_positive.zip") / 1e6
print(f"Saved synthetic_positive.zip to Drive ({size:.0f} MB)")
```

---

## Phase 6: Upload Real Samples + Organize
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

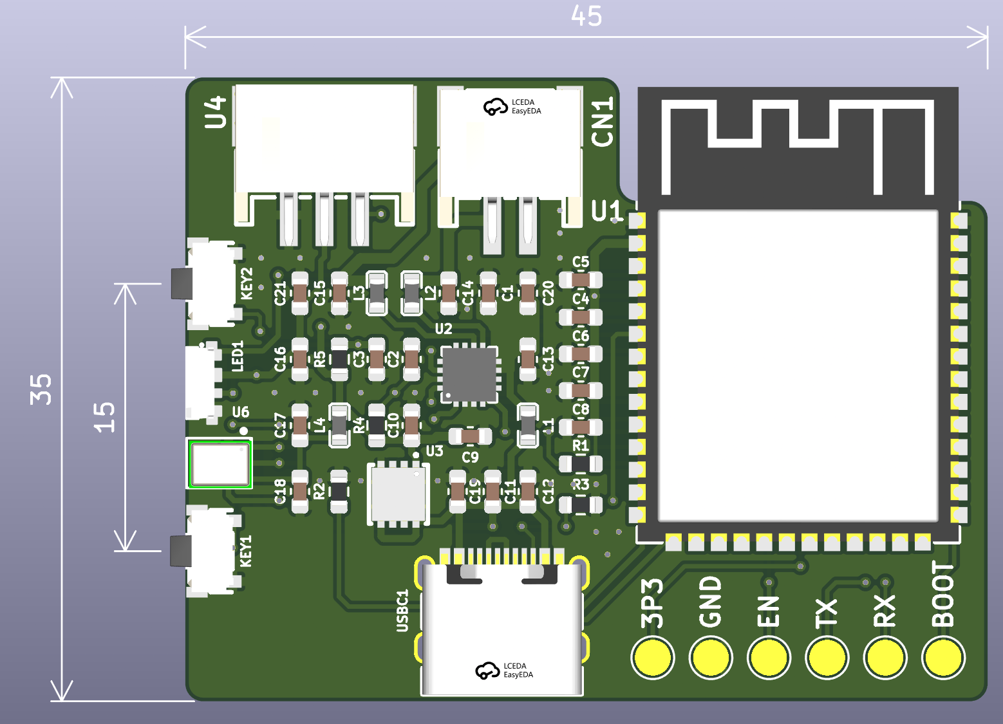
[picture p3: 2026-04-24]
hardware/polly-board/polly_board_v2_final.png

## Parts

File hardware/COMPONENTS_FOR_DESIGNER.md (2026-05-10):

# Polly PCB v2 — Canonical Spec

**Source of truth:** `hardware/polly-board/Polly_v2.*` — the KiCad project Paul P. (Upwork) delivered in April 2026.
The schematic, BOM, CPL, and gerbers there are what gets manufactured. This document explains the choices and the
non-negotiable details so a new designer can review or extend the board without re-litigating decisions.

**Board:** 45 × 35 mm, 2-layer FR4, fully SMT-assembled by JLCPCB.

**End-user connections (only these are customer-facing):**
- USB-C (power + firmware flash)
- JST-PH 2-pin SMD (speaker wire out)
- JST-PH 3-pin SMD (LED chain to Polly's eyes)

No exposed pin headers. No hand soldering. UART fallback exposed as **labeled SMD test pads along the bottom edge**
(pogo-pin probe, not a connector).

---

## BOM (Paul's v2, manufactured by JLCPCB)

All part numbers are JLCPCB LCSC codes. Verify stock right before ordering — LCSC parts rotate in and out.

| Ref | Component | LCSC | Package | Notes |
|-----|---|---|---|---|
| U1 | **ESP32-S3-WROOM-1-N16R8** | **C2913202** | SMD module | **DO NOT SUBSTITUTE.** Must be N16R8 (16 MB flash, 8 MB octal PSRAM). A previous order was substituted to N4R2, which is incompatible with the firmware. Add this as a human-readable order note to JLCPCB. |
| U2 | MAX98357AETE+T | C910544 | TQFN-16 (3×3 mm) | I2S mono audio amp. Runs on **+5V (SP_5V)** for max volume — do NOT tie VDD to +3.3V. **GAIN_SLOT tied to GND = 15 dB (loudest setting).** **SD_MODE controlled by GPIO13** (firmware drives high to enable amp, low to mute — saves power and kills idle hiss). |
| U3 | AP7361-33FGE-7 | C460392 | DFN-8 | 5V → 3.3V LDO regulator, 1 A capability, low noise. Replaces AMS1117 from the v1 spec — better part for clean audio rails. |
| U6 | **ICS-43434** (TDK, I2S MEMS mic) | **C5656610** | LGA-6 | I2S MEMS mic. Replaces MSM261DGT003 (PDM, incompatible with firmware) and INMP441 (out of stock at JLCPCB). 3.3V only (5V will damage the part). |
| LED1 | **SK6812SIDE-A-RVS** | **C2890037** | SMD 4P, side-emit reverse-mount | Addressable RGB, side-firing through a window in the perch / stump wall. Same one-wire 800 kHz protocol as WS2812 — firmware works unchanged. **No series resistor on the data line** (direct GPIO48 → DIN). DOUT chains off-board through the LED-eyes JST. |
| USBC1 | USB-C receptacle (16-pin) | C165948 | TYPE-C-31-M-12 | Power + USB 2.0 data. Place on the **bottom edge** of the board. |
| CN1 | JST-PH 2-pin SMD (speaker out) | **C295747** | S2B-PH-SM4-TB, 2.0 mm pitch, side-entry SMD | Pin 1 = OUTP, Pin 2 = OUTN. SMD = no through-hole soldering at JLCPCB. |
| U4 | JST-PH 3-pin SMD (LED eyes out) | **C265101** | S3B-PH-SM4-TB, 2.0 mm pitch, side-entry SMD | **Pin 1 = DATA (chain-out from LED1 DOUT), Pin 2 = +5V, Pin 3 = GND.** Customer pigtails MUST match this pin order — DATA is on pin 1, not the middle pin. |
| KEY1 | **RESET button** | C255810 | SMD tactile (1TS003B-2500-3500A-CT) | EN → GND when pressed. |
| KEY2 | **BOOT / Story button** | C255810 | SMD tactile (1TS003B-2500-3500A-CT) | GPIO0 → GND when pressed. Doubles as Story button in firmware (short press = record, hold on power-up = flash mode). |

**Passives (all 0603):**

| Ref | Value | LCSC | Purpose |
|-----|---|---|---|
| C1, C20 | 4.7 µF | C69335 | USB_5V / SP_5V bulk |
| C10, C12, C13, C18, C2, C21, C3, C4, C5 | 100 nF | C1590 | Decoupling across rails (ESP32, LDO, amp, mic) — including **C2 100nF on EN-to-GND** (RC reset filter) and **C3 100nF on BOOT-to-GND** (debounce) |
| C11, C17, C19, C6, C7, C8, C9 | 10 µF | C70225 | Bulk caps on 3.3V rails and USB VBUS |
| C14, C15 | 470 pF | C1620 | Class-D speaker output EMI filter (paired with L2/L3) |
| C16 | 1 µF | C1592 | LED chain bulk |
| L1, L2, L3, L4 | 120 Ω @ 100 MHz | C14709 | Ferrite beads — **L1 splits USB_5V from SP_5V** (audio gets clean 5V), **L2/L3 on speaker outputs** (Class-D filter), **L4 splits ESP_3V3 from MIC_3V3** (clean mic supply) |
| R1 | 100 kΩ | C14675 | MAX98357A SD_MODE pull-up to GPIO13 |
| R2, R3 | 5.1 kΩ | C14677 | USB-C CC1 / CC2 pull-**downs to GND** |
| R4, R5 | 10 kΩ | C15401 | EN pull-up + BOOT pull-up to +3.3V |

---

## GPIO Pin Assignments (firmware-locked — DO NOT CHANGE)

| GPIO | Function | Connected to |
|---|---|---|
| GPIO0 | BOOT / Story button | KEY2 → GND |
| GPIO4 | Mic SD (I2S data) | U6 SD |
| GPIO5 | Mic WS (I2S word select) | U6 WS |
| GPIO6 | Mic SCK (I2S clock) | U6 SCK |
| GPIO10 | Amp DIN | U2 DIN |
| GPIO11 | Amp LRCLK | U2 LRCLK |
| GPIO12 | Amp BCLK | U2 BCLK |
| **GPIO13** | **Amp SD_MODE (software enable)** | U2 SD_MODE via R1 100k. Firmware must drive HIGH at boot to enable the amp. |
| GPIO19 | USB D- | USBC1 D- |
| GPIO20 | USB D+ | USBC1 D+ |
| GPIO48 | RGB LED data | LED1 DIN |
| EN | Reset | R4 pull-up + KEY1 → GND, with C2 100nF RC filter |

All other GPIOs left floating.

---

## Layout Rules (must match)

See `polly-board/polly_board_v2_final.png` for the visual reference.

1. **Board size: 45 × 35 mm**, 2-layer.
2. **Perch edge** (the edge that faces outward through the 3D-printed stump wall) carries all user-facing components:
   - Left to right: **KEY1 (Reset) — LED1 — U6 (Mic) — KEY2 (Story/BOOT)**
   - **Minimum 15 mm between KEY1 and KEY2** (button cap clearance, ergonomic press)
   - Mic acoustic port faces outward sideways, not down through the PCB
   - LED side-firing through a window in the stump
   - All four components flush with or within 1 mm of the Edge.Cuts boundary
3. **Bottom edge** carries USB-C and six labeled SMD test pads: **3P3, GND, EN, TX, RX, BOOT** (for UART-based firmware recovery via pogo pins).
4. **JSTs (CN1 speaker, U4 LED eyes)** on a non-perch edge — top or back. Wires route internally.
5. **Mic ↔ speaker JST** kept as far apart as the board allows, to reduce acoustic feedback.
6. **ESP32 PCB antenna** overhangs board edge OR has no ground pour / no copper directly beneath it.

---

## Non-negotiable electrical details (don't repeat past mistakes)

- **CC1 and CC2**: 5.1 **kΩ** (NOT 5.1 Ω) pull-**down** to GND (NOT pull-up to 3.3V). USB-C host will refuse to supply power otherwise.
- **USB D+ = GPIO20, USB D- = GPIO19** (native USB).
- **KEY1 (RESET) on EN**, **KEY2 (BOOT) on GPIO0**.
- **R4 (EN pull-up) tied to EN pin** + **C2 100nF on EN-to-GND** for clean reset.
- **ICS-43434 VDD = +3.3V only**. +5V damages it.
- **MAX98357A VDD = +5V (SP_5V via L1 ferrite bead from VBUS)**, NOT +3.3V (quieter at 3.3V).
- **MAX98357A GAIN_SLOT = GND** for 15 dB max gain.
- **MAX98357A SD_MODE = GPIO13 via R1 100k** — firmware must drive HIGH at boot.
- **WS2812 / SK6812 data line direct from GPIO48** — no series resistor.
- **ESP32 module 3V3 pin → +ESP_3P3, GND pins → GND**. Not swapped.
- **Ground pour on both layers**, connected by vias, clear of antenna area.

---

## What to deliver

1. KiCad project (`.kicad_pro`, `.kicad_sch`, `.kicad_pcb`) — already committed at `hardware/polly-board/Polly_v2.*`
2. JLCPCB-ready gerbers (zip) — already at `hardware/polly-board/production/Polly_V2.zip`
3. BOM CSV in LCSC format (`Designator, Footprint, Quantity, Value, LCSC Part #`) — at `hardware/polly-board/production/Polly_V2_bom.csv`
4. CPL / POS CSV (`Designator, Mid X, Mid Y, Rotation, Layer`) — at `hardware/polly-board/production/Polly_V2_positions.csv`

Order quantity: **5–10 prototypes first** for validation before any production run.

---

## Alternate designs in flight

- **Paul P. (Upwork) — `hardware/polly-board/`** — current canonical, manufactured-ready.
- **Fiverr designer (alt) — `hardware/polly-board-alt-fiverr/`** — alternate v2 layout being developed in parallel as a price/quality comparison. Glen plans to assemble both and bench-test before locking in a single design for production.

If you're a new designer joining the project, **start from Paul's files**. If asked to do an "alt" version, copy his project as your starting reference rather than redrawing from scratch.

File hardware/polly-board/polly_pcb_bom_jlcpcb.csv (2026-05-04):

Comment | Designator | Footprint | LCSC
100nF | C1,C3 | C_0805_2012Metric | C49678
10uF | C2,C4 | C_0805_2012Metric | C15850
USB_C_Receptacle_USB2.0_16P | J1 | USB_C_Receptacle_HRO_TYPE-C-31-M-12 | C165948
Conn_01x05 | J2,J5 | PinHeader_1x05_P2.54mm_Vertical | C358687
Conn_01x02 | J4 | PinHeader_1x02_P2.54mm_Vertical | C376042
10k | R1 | R_0805_2012Metric | C17414
5.1k | R2,R3 | R_0805_2012Metric | C27834
330 | R4 | R_0805_2012Metric | C23138
SW_Push | SW1,SW2 | SW_SPST_PTS645Sx43SMTR92 | C221880
AMS1117-3.3 | U1 | SOT-223-3_TabPin2 | C6186
ESP32-S3-WROOM-1-N16R8 | U2 | ESP32-S3-WROOM-1 | C2913202

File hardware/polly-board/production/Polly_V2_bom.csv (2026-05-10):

Designator | Footprint | Quantity | Value | LCSC Part #
C1, C20 | 0603 | 2 | 4.7uF | C69335
C10, C12, C13, C18, C2, C21, C3, C4, C5 | 0603 | 9 | 100nF | C1590
C11, C17, C19, C6, C7, C8, C9 | 0603 | 7 | 10uF | C70225
C14, C15 | 0603 | 2 | 470pF | C1620
C16 | 0603 | 1 | 1uF | C1592
CN1 | CONN-SMD_P2.00_S2B-PH-SM4-TB-LF-SN | 1 | S2B-PH-SM4-TB | C295747
KEY1, KEY2 | KEY-SMD_1TS003B-2500-3500A-CT | 2 | SW2 | C255810
L1, L2, L3, L4 | L0603 | 4 | 120Ω@100MHz | C14709
LED1 | LED-SMD_4P-L4.0-W1.6-L | 1 | SK6812SIDE-A-RVS | C2890037
R1 | 0603 | 1 | 100k | C14675
R2, R3 | 0603 | 2 | 5.1k | C14677
R4, R5 | 0603 | 2 | 10k | C15401
U1 | WIRELM-SMD_ESP32-S3-WROOM-1 | 1 | ESP32-S3-WROOM-1 | C2913202
U2 | TQFN-16_L3.0-W3.0-P0.50-BL-EP1.5 | 1 | MAX98357AETE+T | C910544
U3 | U-DFN3030-8_L3.0-W3.0-P0.65-BL-EP | 1 | AP7361-33FGE-7 | C460392
U4 | CONN-SMD_S3B-PH-SM4-TB-LF-SN | 1 | S3B-PH-SM4-TB | C265101
U6 | MIC-SMD_6P-L3.5-W2.7-P0.90-BL | 1 | ICS-43434_C5656610 | C5656610
USBC1 | USB-C_SMD-TYPE-C-31-M-12_1 | 1 | TYPE-C-31-M-12 | C165948

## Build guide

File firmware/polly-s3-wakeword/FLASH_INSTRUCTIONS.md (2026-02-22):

# Polly S3 Wake Word - Flash Instructions

## What This Does
- ESP32-S3 listens continuously for "Hi ESP" wake word (placeholder)
- On detection: beep → record your speech → send to Polly server → play response
- Wake word runs 100% locally on the chip (no cloud needed for detection)
- Custom "Hey Polly" wake word will replace "Hi ESP" after training

## Hardware Wiring

### INMP441 Microphone
| INMP441 Pin | ESP32-S3 Pin |
|---|---|
| VDD | 3.3V |
| GND | GND |
| SCK | GPIO6 |
| WS | GPIO5 |
| SD | GPIO4 |
| L/R | GND |

### MAX98357A Speaker Amp
| MAX98357A Pin | ESP32-S3 Pin |
|---|---|
| VIN | 5V |
| GND | GND |
| BCLK | GPIO12 |
| LRC | GPIO11 |
| DIN | GPIO10 |

### Speaker
- Connect speaker wires to + and - on MAX98357A

## Step 1: Install ESP-IDF (One Time)

1. Download the **ESP-IDF v5.4.x Windows Installer** from:
   https://dl.espressif.com/dl/esp-idf/

2. Run the installer:
   - Install to default `C:\Espressif\`
   - Select ESP-IDF v5.4.x
   - Check ALL chip targets (especially ESP32-S3)
   - Let it install everything (Python, Git, CMake, toolchains)

3. After install, you'll have a new shortcut:
   **"ESP-IDF 5.4 CMD"** in your Start Menu
   USE THIS for all commands below (not regular cmd/PowerShell)

## Step 2: Plug In ESP32-S3

1. Connect ESP32-S3 to your PC via USB cable
2. Check which COM port it's on:
   - Open Device Manager → Ports (COM & LPT)
   - Look for "USB-SERIAL" or "CP210x" or "CH340"
   - Note the COM number (e.g., COM3)

   If no COM port shows up, you may need a driver:
   - CP2102: https://www.silabs.com/developers/usb-to-uart-bridge-vcp-drivers
   - CH340: https://www.wch-ic.com/downloads/CH341SER_EXE.html

## Step 3: Build

Open **ESP-IDF 5.4 CMD** from Start Menu, then:

```
cd C:\Users\big_g\Desktop\polly-connect\firmware\polly-s3-wakeword

idf.py set-target esp32s3

idf.py build
```

First build takes 5-10 minutes (downloads ESP-SR models, compiles everything).
Subsequent builds are much faster.

## Step 4: Flash

```
idf.py -p COM3 flash
```

Replace COM3 with your actual COM port from Step 2.

If it says "failed to connect":
1. Hold the BOOT button on the ESP32-S3
2. Press and release the RESET button
3. Release the BOOT button
4. Try the flash command again

## Step 5: Monitor (See Serial Output)

```
idf.py -p COM3 monitor
```

You should see:
```
=== Polly Connect - ESP32-S3 Wake Word ===
Microphone initialized (INMP441 on GPIO 5/4/6)
Speaker initialized (MAX98357A on GPIO 15/16/17)
WiFi connected! IP: 192.168.x.x
WakeNet initialized - listening for 'Hi ESP'
Say 'Hi ESP' to activate!
```

When you say "Hi ESP", you should see:
```
*** WAKE WORD DETECTED! ***
Recording started...
Silence detected - stopping recording
Recorded 24000 samples (1.5 seconds)
Sending 48000 bytes to server...
```

Press Ctrl+] to exit the monitor.

## Step 6: Build + Flash + Monitor (All at Once)

For convenience, you can do all three in one command:

```
idf.py -p COM3 flash monitor
```

## Troubleshooting

### "No COM port found"
- Try a different USB cable (some are charge-only)
- Try the other USB port on the ESP32-S3 (some boards have two)
- Install the USB driver (see Step 2)

### "Failed to connect to ESP32-S3"
- Use the BOOT + RESET button combo (see Step 4)
- Make sure you're using USB, not UART

### "WiFi connection failed"
- Edit `main/main.c` line 60-61 with your home WiFi credentials
- Rebuild and reflash

### "No wake word model found"
- Make sure `sdkconfig.defaults` has `CONFIG_SR_WN_WN9_HIESP=y`
- Delete the `build/` folder and rebuild: `idf.py fullclean && idf.py build`

### Mic not working (no audio levels)
- Check wiring: SCK→GPIO5, WS→GPIO4, SD→GPIO6, L/R→GND
- Make sure INMP441 gets 3.3V (NOT 5V!)
- Try swapping L/R pin to 3.3V (right channel) and change code

## Before Flashing: Edit Your WiFi

Open `main/main.c` and update lines 60-61 with your HOME WiFi:

```c
#define WIFI_SSID      "Your_Home_WiFi"
#define WIFI_PASSWORD   "Your_Home_Password"
```

Also update line 64 with your PC's IP address on your home network:

```c
#define SERVER_HOST     "192.168.1.100"
```

To find your PC's IP: open CMD and type `ipconfig`

## What's Next

After confirming wake word works with "Hi ESP":
1. Train custom "Hey Polly" model using your recorded samples
2. Swap the model file
3. Design PCB in KiCad with these exact pin assignments

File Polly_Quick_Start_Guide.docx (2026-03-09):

# Polly Connect

Quick Start Guide

Step 1: Plug In Polly

- Plug the power cable into Polly and into a wall outlet. Place Polly in the kitchen or living room where you spend the most time. Wait for the green light.

Step 2: Connect to WiFi

- On your phone, go to WiFi settings.
- Look for a network called "Polly-Setup" and connect to it.
- A setup page will appear — select your home WiFi and enter the password.
- Polly will restart and connect. The light will turn solid green when ready.

Step 3: Talk to Polly

- Say "Hey Polly" to wake her up, then ask your question or give a command.

Step 4: Try These Commands

- "Hey Polly, what time is it?" — Get the current time
- "Hey Polly, what's the weather?" — Hear today's forecast
- "Hey Polly, tell me a joke" — Hear a joke
- "Hey Polly, tell me a kid joke" — Kid-friendly joke
- "Hey Polly, read me a Bible verse" — Daily scripture
- "Hey Polly, tell me a story" — Hear a family story
- "Hey Polly, what are my medications?" — Medication reminders
- "Hey Polly, ask me a question" — Record a family story

Step 5: Record a Story (Button)

- Press the + button on Polly to start recording a story. Press it again to stop. Polly will save it automatically.

Step 6: View Stories Online

- Go to polly-connect.com on any phone or computer.
- Log in with the email and password your caretaker set up.
- Family members can use the 6-digit Family Access Code to view stories (read-only).

Need help? Contact your caretaker or visit polly-connect.com

Polly Connect © 2026

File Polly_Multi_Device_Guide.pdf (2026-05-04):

# Polly Connect — Multi-Device Guide

### Setting Up a New Polly Device

1. Power on your new Polly. It will create a WiFi network called Polly-Setup.
2. On your phone, connect to the Polly-Setup WiFi network.
3. A setup page will appear. Enter your home WiFi name, password, and the 6-digit claim code from your setup card.
4. Polly will restart, connect to your WiFi, and link to the server.
5. Log in at polly-connect.com. If you see a 'Connect Your Device' prompt, enter the same claim code. If it already shows as claimed, you're all set!

Each device gets its own unique identity. You can name them (Kitchen Polly, Bedroom Polly, etc.) on the Devices page.

### Customizing Each Polly

When you have multiple Pollys, the Settings page shows device tabs so you can customize each one:
Polly Sounds — Different squawk intervals, chatter frequency, and volume per device. Quiet Hours — Bedroom Polly sleeps 9 PM–7 AM, Office Polly sleeps 8 PM–3 AM. Snooze — Snooze one Polly without affecting the others.
Kid Mode — Turn on kid-friendly jokes for the kids' room Polly.
Reminders — Assign reminders to specific devices. Morning vitamins on Kitchen Polly, bedtime reminder on Bedroom Polly.

If you don't customize a device, it inherits the default settings from your account.

### What All Your Pollys Share

All devices on your account share the same:
Stories, photos, and family tree
Legacy book and chapters
Family message board — leave a message on one, hear it on any Stored items ('Where are my keys?')
Blessings and prayer recordings

Think of it like having the same parrot in multiple rooms — same personality, same memories, different perch.

### Tips for Multiple Pollys

Talk to the closest one. Each Polly listens independently. Talk to whichever is nearest.
Two people can talk at the same time — to different Pollys. Each handles its own conversation.
Messages sync instantly. Leave a message at work, your family hears 'Message! Message!' at home.
Snooze is per-device. Snooze the bedroom Polly for nap time without silencing the kitchen one.
Reminders are flexible. Your 4 AM vitamins can go to just your device — your partner's Polly stays quiet.

polly-connect.com

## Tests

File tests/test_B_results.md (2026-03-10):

# Test Suite B — Prayer & Story Intent Coverage

**Date:** 2026-03-10
**Result:** 270 tests passed, 0 failed
**Combined (A + B):** 453 tests passed, 0 failed

---

## What Test B Covers

Test B systematically tests the two newest feature sets — **Prayer** (Phase 27) and **Stories** (Phases 0-5, 23) — covering every voice phrase, theme route, edge case, and cross-intent guard.

### Prayer Tests (175 cases)

| Category | Tests | What's Covered |
|---|---|---|
| Basic phrases | 19 | Every way to say "pray" — direct, polite, casual |
| Time-based themes | 6 | Bedtime, goodnight, morning, evening → correct theme |
| Emotional triggers | 28 | Natural speech ("I'm worried", "I miss her") → correct theme |
| Theme keywords | 26 | "Pray for strength/hope/peace..." → themed prayer, NOT person name |
| Keyword NOT person | 28 | All 28 theme words confirmed as NOT extracted as pray_for |
| Pray for person | 16 | Name extraction: "pray for Ryan", "prayer for Glen", "pray over Ryan" |
| Generic not extracted | 5 | "pray for me/us/family/kids" → pray_for stays None |
| Family-specific | 6 | Family prayer phrases → family theme |
| Healing contexts | 2 | Health/healing triggers |
| Edge cases | 11 | Cross-intent guards, unknown names, skip list coverage |
| Natural speech | 9 | Realistic STT transcriptions with "polly" prefix |
| Regressions | 4 | All prayer bugs from bugs.md |

### Story Tests (95 cases)

| Category | Tests | What's Covered |
|---|---|---|
| Hear stories | 26 | "tell me a story", "read me a story", "play my stories", "what did grandma say" |
| Query extraction | 4 | "tell me about grandma" → query="grandma" |
| Tell/record story | 16 | "let me tell you about...", "record my story", "story time" |
| Family questions | 14 | "interview me", "ask me about my life", "give me a question" |
| Story progress | 11 | "how many stories", "how's my book", "book progress" |
| Introductions | 5 | "This is Sarah", "My name is Joe" + relationship extraction |
| Cross-intent guards | 10 | Story vs prayer, story vs messages, story vs bible |
| Priority order | 5 | Intent priority verified: stories > jokes > messages > bible > prayer > items |
| Natural speech (hear) | 6 | "polly tell me a story", "can you read a story for me" |
| Natural speech (record) | 7 | "polly let me tell you about...", "hey polly story time" |
| Regressions | 5 | "what did i miss" → messages, "say a prayer for ryan" extraction |

---

## Bugs Found & Fixed During Test B Creation

### 1. Contraction normalization mangling words (NEW)
- **Symptom:** "give me strength" → unknown, "give me a question" → unknown
- **Root cause:** `"ive " → "i've "` was plain `.replace()` — matched inside "g**ive** me" → "gi've me"
- **Fix:** Changed `im`/`ive` contractions to use `re.sub(r'\b...')` word boundaries
- **File:** `server/core/intent_parser.py`
- **Affected phrases:** "give me strength", "give me a question", "give me a joke", "give me a verse", any phrase with "give"

### 2. "bless" not in gratitude theme keywords
- **Symptom:** "bless this day" → prayer with no theme (expected gratitude)
- **Fix:** Added "bless" to gratitude theme word list
- **File:** `server/core/intent_parser.py`

### 3. "happiness" not in joy theme keywords
- **Symptom:** "pray for happiness" → prayer with no theme (expected joy)
- **Fix:** Added "happiness" to joy theme word list
- **File:** `server/core/intent_parser.py`

### 4. "read me one of my stories" not recognized
- **Symptom:** → unknown (phrase not in hear_stories list)
- **Fix:** Added to `_hear_stories_phrases`
- **File:** `server/core/intent_parser.py`

### 5. Test A: "tell me a story" was in tell_story test
- **Symptom:** "tell me a story" correctly routes to hear_stories (user wants to HEAR a story), but test_A expected tell_story
- **Fix:** Moved to hear_stories test, added explicit test documenting this behavior

---

## Prayer Intent — Complete Voice Phrase Reference

### Direct Requests
```
say a prayer          pray for me           pray with me
let's pray            let us pray           can you pray
i need a prayer       prayer                pray
say a prayer for me   will you pray         i want to pray
help me pray          lead me in prayer     lead a prayer
can we pray           would you pray        pray for us
pray over me
```

### Time-Based (auto-themed)
```
bedtime prayer → rest        goodnight prayer → rest
nighttime prayer → rest      evening prayer → rest
morning prayer → strength    start the day with prayer → strength
```

### Emotional Triggers (auto-themed)
```
i'm worried → anxiety        i'm scared → anxiety
i miss him/her → grief       i feel alone → loneliness
i'm having a hard day → strength    i need some hope → hope
i need peace → peace         i'm thankful → gratitude
praise god → gratitude       bless this day → gratitude
give me strength → strength  i'm struggling → strength
```

### Theme Keywords (NOT treated as person names)
```
pray for strength/courage/resilience/perseverance → strength
pray for hope → hope
pray for peace/comfort/grace/mercy/calm → peace
pray for faith/wisdom/guidance → faith
pray for healing/health → healing
pray for forgiveness → forgiveness
pray for blessings/glory → gratitude
pray for joy/happiness → joy
pray for family/kids/grandchildren → family
```

### Pray For Person
```
pray for [name]              prayer for [name]
say a prayer for [name]      pray over [name]
pray for [name] please
```

---

## Story Intent — Complete Voice Phrase Reference

### Hear/Play Stories (hear_stories)
```
tell me a story              read me a story
play a story                 share a story
narrate a story              story reading
play my stories              read my stories
tell me my story             read me one of my stories
tell me about [topic]        any stories about [topic]
what did grandma say         what has she said
do you have any stories      play back
```

### Record a Story (tell_story)
```
let me tell you about...     i remember when...
i want to tell you...        let me share...
i have a story               story time
record my story              take my story
i want to share...           i have something to share
let me tell you something    can i tell you something
i got a story                i have a memory to share
```

### Family Questions (family_question)
```
ask me about my family       family question
ask me a family question     family story
ask me about my life         interview me
give me a question           ask me about my past
ask me about growing up
```

### Story Progress (story_progress)
```
how many stories             my progress
story progress               how's my book
book progress                how far along are we
how many have we done
```

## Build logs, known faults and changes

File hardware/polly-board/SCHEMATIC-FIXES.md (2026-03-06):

# Polly PCB Schematic Fix List

**Project:** Polly Connect — ESP32-S3 Voice Companion Board
**Date:** 2026-03-02
**KiCad Version:** 9.0.7
**Schematic File:** `polly_pcb.kicad_sch`

This document lists all schematic errors found during review, organized by priority. The working prototype pinout (breadboard) is the source of truth for all GPIO assignments.

---

## Reference: Working Prototype Pin Assignments

| Function | GPIO | ESP32-S3-WROOM-1 Module Pin |
|---|---|---|
| INMP441 SCK (mic clock) | GPIO 6 | Pin 6 |
| INMP441 WS (mic word select) | GPIO 5 | Pin 5 |
| INMP441 SD (mic data out) | GPIO 4 | Pin 4 |
| MAX98357A BCLK (amp bit clock) | GPIO 12 | Pin 20 |
| MAX98357A LRC (amp left/right) | GPIO 11 | Pin 19 |
| MAX98357A DIN (amp data in) | GPIO 10 | Pin 18 |
| Status LED | GPIO 48 | Pin 25 |
| Boot Button | GPIO 0 | Pin 27 |
| EN / Reset | EN | Pin 3 |
| USB D- | GPIO 19 | Pin 13 |
| USB D+ | GPIO 20 | Pin 14 |

---

## PRIORITY 1 — Power (will destroy components if not fixed)

### Fix 1.1: ESP32 3V3 and GND are swapped

**Problem:** U2 pin 2 (3V3 power input) is connected to the GND net. U2 pin 1 (GND) is connected to the +3.3V net. Building this as-is will destroy the ESP32 module.

**Fix:** Swap the two net connections on the ESP32:
- U2 **Pin 1** (GND) → connect to **GND** net
- U2 **Pin 2** (3V3) → connect to **+3.3V** net
- U2 **Pin 40** (GND) → connect to **GND** net
- U2 **Pin 41** (GND) → connect to **GND** net

---

### Fix 1.2: USB-C VBUS not connected to voltage regulator

**Problem:** The USB-C VBUS pins (J1 pins A4, A9, B4, B9) are not connected to anything useful. Instead, J1 pin B8 (SBU2 — a sideband pin, NOT a power pin) is mistakenly routed to U1 input.

**Fix:**
- Disconnect J1 pin B8 (SBU2) from U1 input — leave SBU2 unconnected
- Connect J1 VBUS pins (A4/A9/B4/B9) → U1 pin 3 (VI, regulator input)
- This is the +5V rail from USB

---

### Fix 1.3: AMS1117 regulator GND pin is floating

**Problem:** U1 pin 1 (GND) has no connection. The regulator cannot function without a ground return path.

**Fix:** Connect U1 **pin 1** (GND) → **GND** net

---

### Fix 1.4: USB-C GND pins isolated from board GND

**Problem:** J1 GND pins (A1, A12, B1, B12) connect only to each other but have no wire to the rest of the circuit's GND net.

**Fix:** Connect J1 GND pins → **GND** net (one wire from the group to the GND rail is sufficient)

---

### Fix 1.5: USB-C shield pin

**Problem:** J1 shield pin (S1) is floating.

**Fix:** Connect J1 **S1** (shield) → **GND** net

---

## PRIORITY 2 — USB-C CC Pull-Downs (required for power delivery)

### Fix 2.1: CC1 and CC2 pull-down resistors not connected

**Problem:** USB-C pins CC1 (J1 pin A5) and CC2 (J1 pin B5) are both completely isolated. Without 5.1k ohm pull-down resistors to GND, the USB host will not recognize the device and will not supply power.

R2 and R3 exist in the schematic but are not wired to CC1/CC2 or GND.

**Fix:**
- Connect J1 **pin A5** (CC1) → **R3 pin 1**
- Connect R3 **pin 2** → **GND**
- Connect J1 **pin B5** (CC2) → **R2 pin 1**
- Connect R2 **pin 2** → **GND**

---

### Fix 2.2: CC pull-down resistor values are wrong

**Problem:** R2 and R3 are labeled "5.1" which means 5.1 ohms. The USB-C specification requires 5.1 kilohms (5100 ohms).

**Fix:** Change both R2 and R3 values from **"5.1"** to **"5.1k"** (5100 ohms)

---

## PRIORITY 3 — USB Data Lines (required for programming/flashing)

### Fix 3.1: USB D+ connected to wrong GPIO

**Problem:** USB D+ (J1 pin A6) is routed to U2 GPIO38 (module pin 31). On the ESP32-S3, the native USB D+ pin is GPIO20 (module pin 14). GPIO38 has no USB function.

Also, J1 pin B7 (D- on the B side) is incorrectly shorted to the same net as D+.

**Fix:**
- Disconnect J1 pin A6 (D+) from U2 pin 31 (GPIO38)
- Connect J1 pin A6 (D+) → U2 **pin 14** (GPIO20)
- For USB 2.0: short J1 pin B6 to J1 pin A6 (both D+ sides together)

---

### Fix 3.2: USB D- connected to wrong GPIO

**Problem:** USB D- (J1 pin A7) is routed to U2 GPIO45 (module pin 26). The native USB D- pin is GPIO19 (module pin 13).

**Fix:**
- Disconnect J1 pin A7 (D-) from U2 pin 26 (GPIO45)
- Connect J1 pin A7 (D-) → U2 **pin 13** (GPIO19)
- For USB 2.0: short J1 pin B7 to J1 pin A7 (both D- sides together)

---

## PRIORITY 4 — Button and Control Pin Fixes

### Fix 4.1: Boot button on wrong GPIO

**Problem:** SW1 connects to U2 GPIO18 (module pin 11). The ESP32-S3 boot mode pin is GPIO0 (module pin 27). GPIO0 must be held LOW during reset to enter download/flash mode.

**Fix:**
- Disconnect SW1 pin 2 from U2 pin 11 (GPIO18)
- Connect SW1 **pin 1** → **GND**
- Connect SW1 **pin 2** → U2 **pin 27** (GPIO0)

Note: The boot button should pull GPIO0 to GND when pressed. A 10k pull-up on GPIO0 to 3.3V is recommended but the ESP32-S3 has an internal pull-up on GPIO0, so it is optional.

---

### Fix 4.2: Reset button not connected

**Problem:** SW2 pin 2 is floating. It should connect to the ESP32 EN (enable/reset) pin to allow manual reset.

**Fix:**
- Connect SW2 **pin 1** → **GND**
- Connect SW2 **pin 2** → U2 **pin 3** (EN)

Pressing SW2 pulls EN low, resetting the ESP32.

---

### Fix 4.3: EN pull-up resistor on wrong pin

**Problem:** R1 (10k ohm) connects between +3.3V and U2 GPIO37 (module pin 30). It should connect to the EN pin instead. EN requires an external pull-up to keep the chip running.

**Fix:**
- Disconnect R1 pin 2 from U2 pin 30 (GPIO37)
- Connect R1 **pin 1** → **+3.3V**
- Connect R1 **pin 2** → U2 **pin 3** (EN)

This keeps EN high (chip running) and SW2 can pull it low to reset.

---

### Fix 4.4: LED resistor on wrong GPIO

**Problem:** R4 (330 ohm) connects to U2 GPIO43/TXD (module pin 37). The status LED should be on GPIO48 (module pin 25), which is the onboard RGB LED pin on most ESP32-S3 dev boards and matches the firmware.

**Fix:**
- Disconnect R4 pin 2 from U2 pin 37 (GPIO43)
- Connect R4 **pin 2** → U2 **pin 25** (GPIO48)
- R4 pin 1 should connect to the LED anode (or +3.3V if driving LED to ground through GPIO)

---

## PRIORITY 5 — Header Power Pin Fixes

### Fix 5.1: INMP441 mic header (J2) power pins

**Problem:** J2 pin 5 is connected to +5V. The INMP441 is a 3.3V-only device (rated 1.8V to 3.3V max). Applying 5V will damage the microphone.

**Fix:**
- J2 **Pin 4** (VDD) → connect to **+3.3V** rail (AMS1117 output)
- J2 **Pin 5** (GND) → connect to **GND** net

INMP441 header pinout should be:

| J2 Pin | Signal | Net |
|---|---|-----|
| 1 | SCK | GPIO6 (already correct) |
| 2 | WS | GPIO5 (already correct) |
| 3 | SD | GPIO4 (already correct) |
| 4 | VDD | +3.3V |
| 5 | GND | GND |

---

### Fix 5.2: MAX98357A amp header (J5) power pins

**Problem:** J5 pin 4 is connected to +3.3V and J5 pin 5 is connected to +3.3V. The MAX98357A can operate from 2.5V to 5.5V, but 5V gives significantly more speaker volume. Pin 5 should be GND, not power.

**Fix:**
- J5 **Pin 4** (VIN) → connect to **+5V** rail (VBUS, before the regulator)
- J5 **Pin 5** (GND) → connect to **GND** net

MAX98357A header pinout should be:

| J5 Pin | Signal | Net |
|---|---|-----|
| 1 | BCLK | GPIO12 (already correct) |
| 2 | LRC | GPIO11 (already correct) |
| 3 | DIN | GPIO10 (already correct) |
| 4 | VIN | +5V (VBUS) |
| 5 | GND | GND |

---

### Fix 5.3: Speaker output header (J4)

**Problem:** J4 (2-pin speaker output header) pins are both isolated.

**Fix:** These connect to the speaker terminals on the MAX98357A breakout board, so they may not need board-level connections. If J4 is intended as a pass-through, leave as-is or connect to J5's speaker output pins. Confirm intended use.

---

## PRIORITY 6 — Capacitor Placement Verification

Once the power net swap (Fix 1.1) is corrected, verify these capacitors are on the correct nets:

| Ref | Value | Pin 1 (+) Should Connect To | Pin 2 (-) Should Connect To | Purpose |
|-----|---|---|---|---|
| C1 | 100nF | +3.3V (U1 output) | GND | Regulator output decoupling |
| C2 | 10uF | +3.3V (U1 output) | GND | Regulator output bulk bypass |
| C3 | 100nF | +3.3V (near U2) | GND | ESP32 decoupling |
| C4 | 10uF | +5V (U1 input / VBUS) | GND | Regulator input filter |

Place C1 and C2 physically close to U1 (AMS1117). Place C3 close to U2 (ESP32 3V3 pin). Place C4 near the USB-C connector or U1 input.

---

## Summary: What Is Already Correct (no changes needed)

These connections are verified correct and should NOT be changed:

| Connection | Status |
|---|---|
| GPIO 4 (pin 4) → J2 Pin 3 (mic SD) | CORRECT |
| GPIO 5 (pin 5) → J2 Pin 2 (mic WS) | CORRECT |
| GPIO 6 (pin 6) → J2 Pin 1 (mic SCK) | CORRECT |
| GPIO 10 (pin 18) → J5 Pin 3 (amp DIN) | CORRECT |
| GPIO 11 (pin 19) → J5 Pin 2 (amp LRC) | CORRECT |
| GPIO 12 (pin 20) → J5 Pin 1 (amp BCLK) | CORRECT |
| ESP32-S3-WROOM-1 footprint (PCM_Espressif) | CORRECT |
| AMS1117-3.3 as 5V→3.3V regulator | CORRECT |
| R1 = 10k (EN pull-up value) | CORRECT |
| R4 = 330 ohm (LED current limiter value) | CORRECT |

---

## Complete Corrected Net List

After all fixes are applied, the schematic should have these connections:

```
USB-C (J1):
  VBUS (A4/A9/B4/B9) → +5V rail → U1 pin 3 (VI) → C4 pin 1
  GND (A1/A12/B1/B12) → GND net
  CC1 (A5) → R3 (5.1k) → GND
  CC2 (B5) → R2 (5.1k) → GND
  D+ (A6/B6) → U2 pin 14 (GPIO20)
  D- (A7/B7) → U2 pin 13 (GPIO19)
  Shield (S1) → GND

AMS1117-3.3 Regulator (U1):
  Pin 3 (VI) → +5V (from VBUS)
  Pin 2 (VO) → +3.3V rail
  Pin 1 (GND) → GND

ESP32-S3-WROOM-1 (U2):
  Pin 1 (GND) → GND
  Pin 2 (3V3) → +3.3V
  Pin 3 (EN) → R1 (10k) → +3.3V, also → SW2 → GND
  Pin 4 (GPIO4) → J2 pin 3 (mic SD)
  Pin 5 (GPIO5) → J2 pin 2 (mic WS)
  Pin 6 (GPIO6) → J2 pin 1 (mic SCK)
  Pin 13 (GPIO19) → J1 D- (A7/B7)
  Pin 14 (GPIO20) → J1 D+ (A6/B6)
  Pin 18 (GPIO10) → J5 pin 3 (amp DIN)
  Pin 19 (GPIO11) → J5 pin 2 (amp LRC)
  Pin 20 (GPIO12) → J5 pin 1 (amp BCLK)
  Pin 25 (GPIO48) → R4 (330 ohm) → LED
  Pin 27 (GPIO0) → SW1 → GND
  Pin 40 (GND) → GND
  Pin 41 (GND) → GND

Mic Header (J2) — INMP441:
  Pin 1 → GPIO6 (SCK)
  Pin 2 → GPIO5 (WS)
  Pin 3 → GPIO4 (SD)
  Pin 4 → +3.3V
  Pin 5 → GND

Amp Header (J5) — MAX98357A:
  Pin 1 → GPIO12 (BCLK)
  Pin 2 → GPIO11 (LRC)
  Pin 3 → GPIO10 (DIN)
  Pin 4 → +5V (VBUS)
  Pin 5 → GND

Capacitors:
  C1 (100nF): +3.3V → GND (near U1)
  C2 (10uF): +3.3V → GND (near U1)
  C3 (100nF): +3.3V → GND (near U2)
  C4 (10uF): +5V → GND (near U1 input)

Buttons:
  SW1 (BOOT): GPIO0 → GND when pressed
  SW2 (RESET): EN → GND when pressed
```

---

## Total Fix Count

| Priority | Fixes | Category |
|---|---|---|
| P1 | 5 fixes | Power and ground (board won't power on) |
| P2 | 2 fixes | USB-C CC pull-downs (no power delivery) |
| P3 | 2 fixes | USB data lines (can't flash firmware) |
| P4 | 4 fixes | Buttons and control pins |
| P5 | 3 fixes | Header power pins (component damage risk) |
| P6 | 4 verifications | Capacitor placement |
| **Total** | **20 fixes** | |

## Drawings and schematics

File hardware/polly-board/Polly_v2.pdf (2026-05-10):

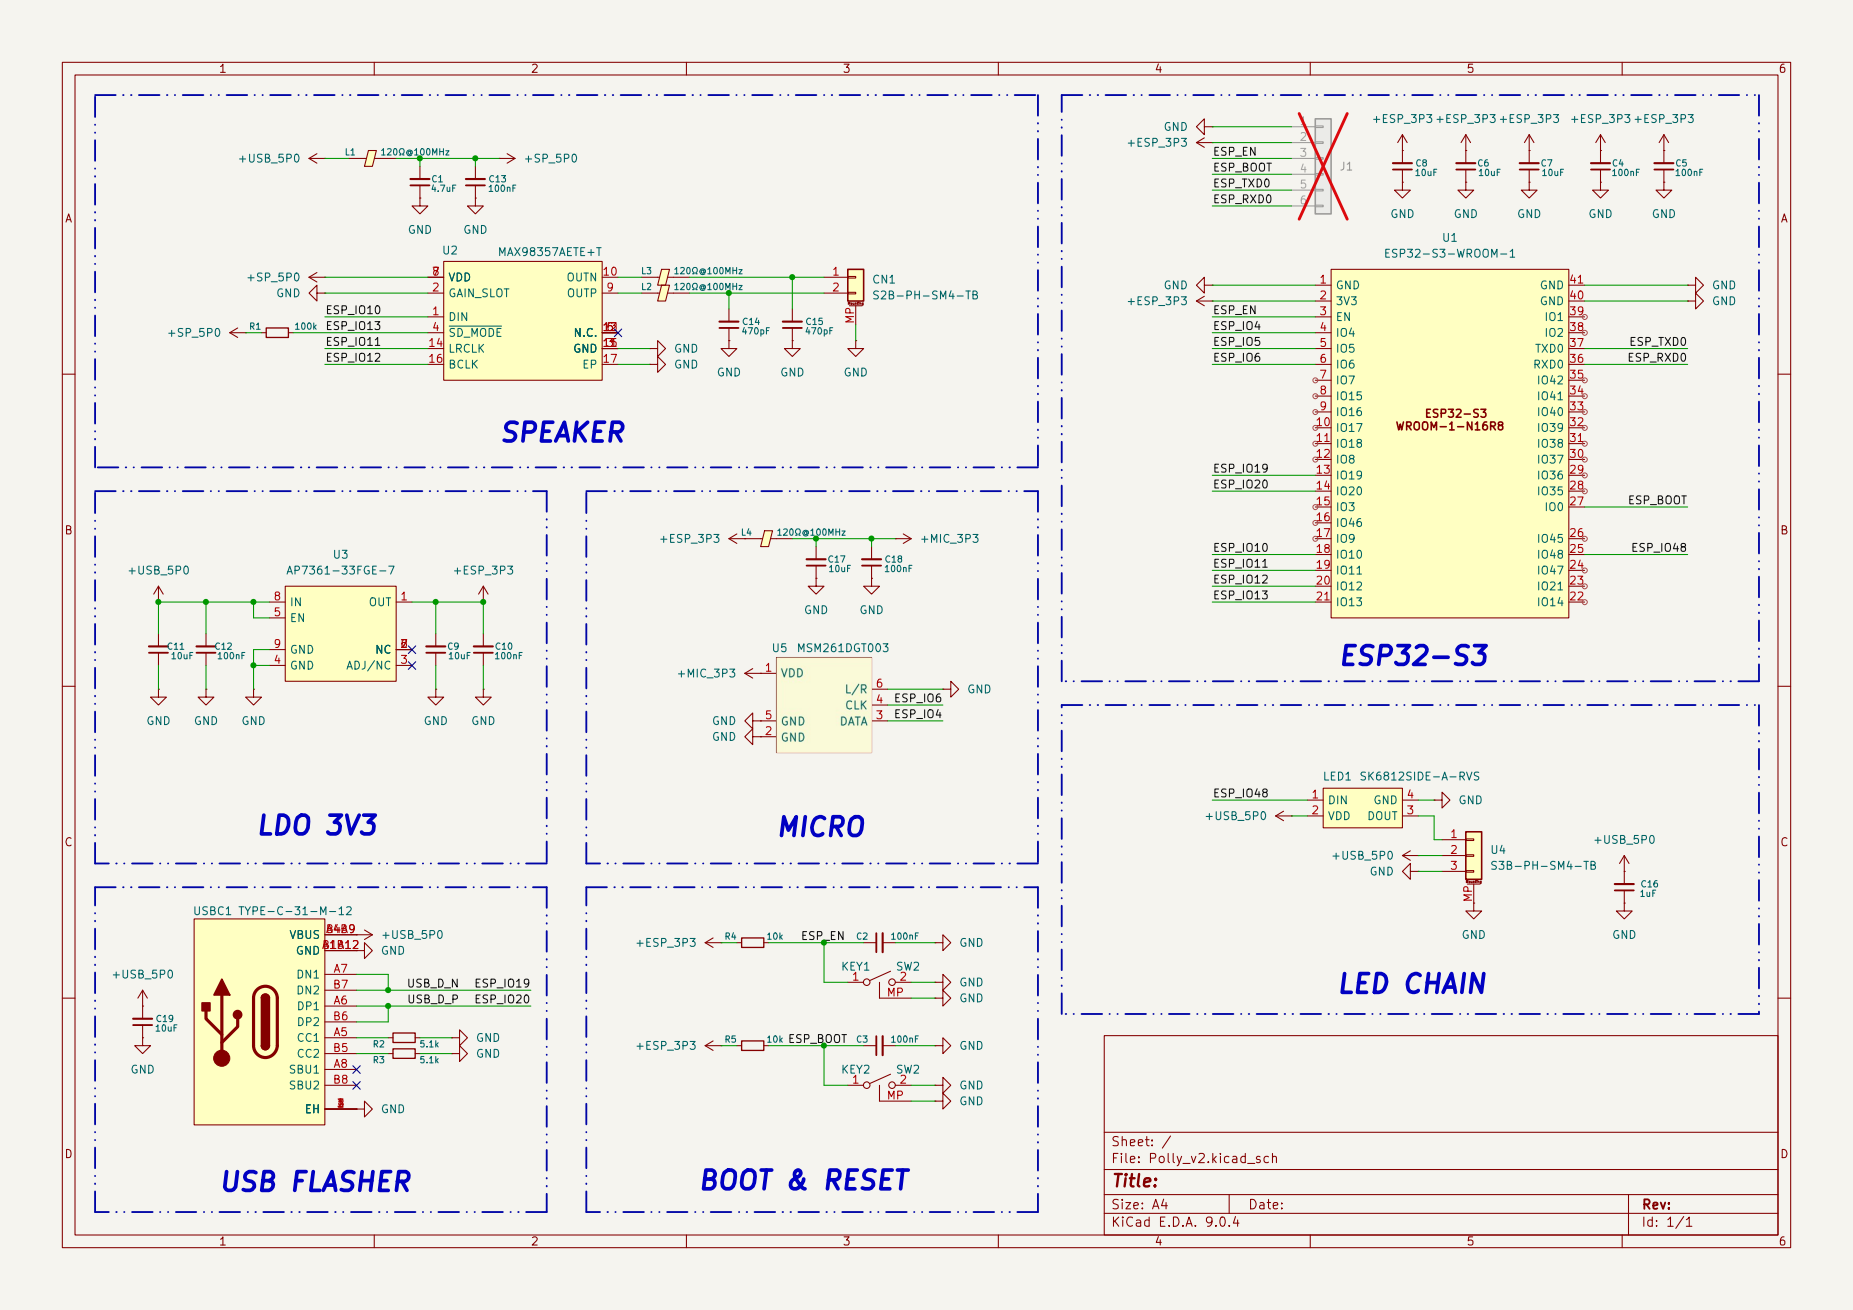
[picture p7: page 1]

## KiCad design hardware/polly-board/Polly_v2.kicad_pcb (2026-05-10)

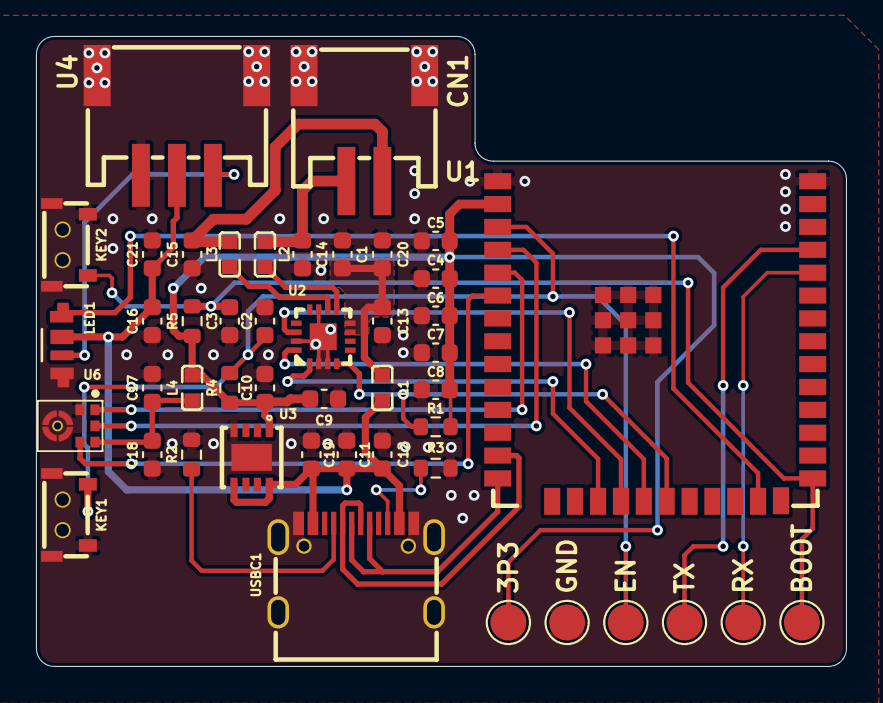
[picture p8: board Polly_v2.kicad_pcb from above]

Board: 2 copper layers, 45.0 x 35.0 mm, 46 parts (0 on the bottom side), 26 nets.

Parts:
C1, C20: 4.7uF; C_0603_1608Metric
C2, C3, C4, C5, C10, C12, C13, C18, C21: 100nF; C_0603_1608Metric
C6, C7, C8, C9, C11, C17, C19: 10uF; C_0603_1608Metric
C14, C15: 470pF; C_0603_1608Metric
C16: 1uF; C_0603_1608Metric
CN1: S2B-PH-SM4-TB; CONN-SMD_P2.00_S2B-PH-SM4-TB-LF-SN
KEY1, KEY2: SW2; KEY-SMD_1TS003B-2500-3500A-CT
L1, L2, L3, L4: 120Ω@100MHz; L0603
LED1: SK6812SIDE-A-RVS; LED-SMD_4P-L4.0-W1.6-L
R1: 100k; R_0603_1608Metric
R2, R3: 5.1k; R_0603_1608Metric
R4, R5: 10k; R_0603_1608Metric
TP1, TP2, TP3, TP4, TP5, TP6: TestPoint; TestPoint_Pad_D2.0mm
U1: ESP32-S3-WROOM-1; WIRELM-SMD_ESP32-S3-WROOM-1
U2: MAX98357AETE+T; TQFN-16_L3.0-W3.0-P0.50-BL-EP1.5
U3: AP7361-33FGE-7; U-DFN3030-8_L3.0-W3.0-P0.65-BL-EP
U4: S3B-PH-SM4-TB; CONN-SMD_S3B-PH-SM4-TB-LF-SN
U6: ICS-43434_C5656610; MIC-SMD_6P-L3.5-W2.7-P0.90-BL
USBC1: TYPE-C-31-M-12; USB-C_SMD-TYPE-C-31-M-12_1

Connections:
+ESP_3P3: C4.2, C5.2, C6.2, C7.2, C8.2, C9.2, C10.2, L4.1, R1.1, R4.1, R5.1, TP2.1, U1.2 (3V3), U3.1 (OUT)
+MIC_3P3: C17.2, C18.2, L4.2, U6.5 (VDD)
+SP_5P0: C1.2, C13.2, C20.2, L1.2, U2.7 (VDD), U2.8 (VDD)
+USB_5P0: C11.2, C12.2, C16.2, C19.2, C21.2, L1.1, LED1.2 (VDD), U3.5 (EN), U3.8 (IN), U4.2, USBC1.A4B9 (VBUS), USBC1.B4A9 (VBUS)
/ESP_BOOT: C3.1, KEY2.2, R5.2, TP4.1, U1.27 (IO0)
/ESP_EN: C2.1, KEY1.1, R4.2, TP3.1, U1.3 (EN)
/ESP_IO4: U1.4 (IO4), U6.6 (SD)
/ESP_IO5: U1.5 (IO5), U6.1 (WS)
/ESP_IO6: U1.6 (IO6), U6.4 (SCK)
/ESP_IO10: U1.18 (IO10), U2.1 (DIN)
/ESP_IO11: U1.19 (IO11), U2.14 (LRCLK)
/ESP_IO12: U1.20 (IO12), U2.16 (BCLK)
/ESP_IO13: R1.2, U1.21 (IO13), U2.4 (~SD_MODE)
/ESP_IO19: U1.13 (IO19), USBC1.A7 (DN1), USBC1.B7 (DN2)
/ESP_IO20: U1.14 (IO20), USBC1.A6 (DP1), USBC1.B6 (DP2)
/ESP_IO48: LED1.1 (DIN), U1.25 (IO48)
/ESP_RXD0: TP6.1, U1.36 (RXD0)
/ESP_TXD0: TP5.1, U1.37 (TXD0)
GND: C1.1, C2.2, C3.2, C4.1, C5.1, C6.1, C7.1, C8.1, C9.1, C10.1, C11.1, C12.1, C13.1, C14.1, C15.1, C16.1, C17.1, C18.1, C19.1, C20.1, C21.1, CN1.MP, KEY1.0, KEY1.2, KEY2.1, KEY2.MP, LED1.4 (GND), R2.2, R3.2, TP1.1, U1.1 (GND), U1.40 (GND), U1.41 (GND), U2.2 (GAIN_SLOT), U2.3 (GND), U2.11 (GND), U2.15 (GND), U2.17 (EP), U3.4 (GND), U3.9 (GND), U4.3, U4.MP, U6.2 (LR), U6.3 (GND), USBC1.1 (EH), USBC1.2 (EH), USBC1.3 (EH), USBC1.4 (EH), USBC1.A1B12 (GND), USBC1.B1A12 (GND)
unnamed: C14.2, CN1.2, L2.2
unnamed: C15.2, CN1.1, L3.2
unnamed: LED1.3 (DOUT), U4.1
unnamed: L3.1, U2.10 (OUTN)
unnamed: L2.1, U2.9 (OUTP)
unnamed: R2.1, USBC1.A5 (CC1)
unnamed: R3.1, USBC1.B5 (CC2)

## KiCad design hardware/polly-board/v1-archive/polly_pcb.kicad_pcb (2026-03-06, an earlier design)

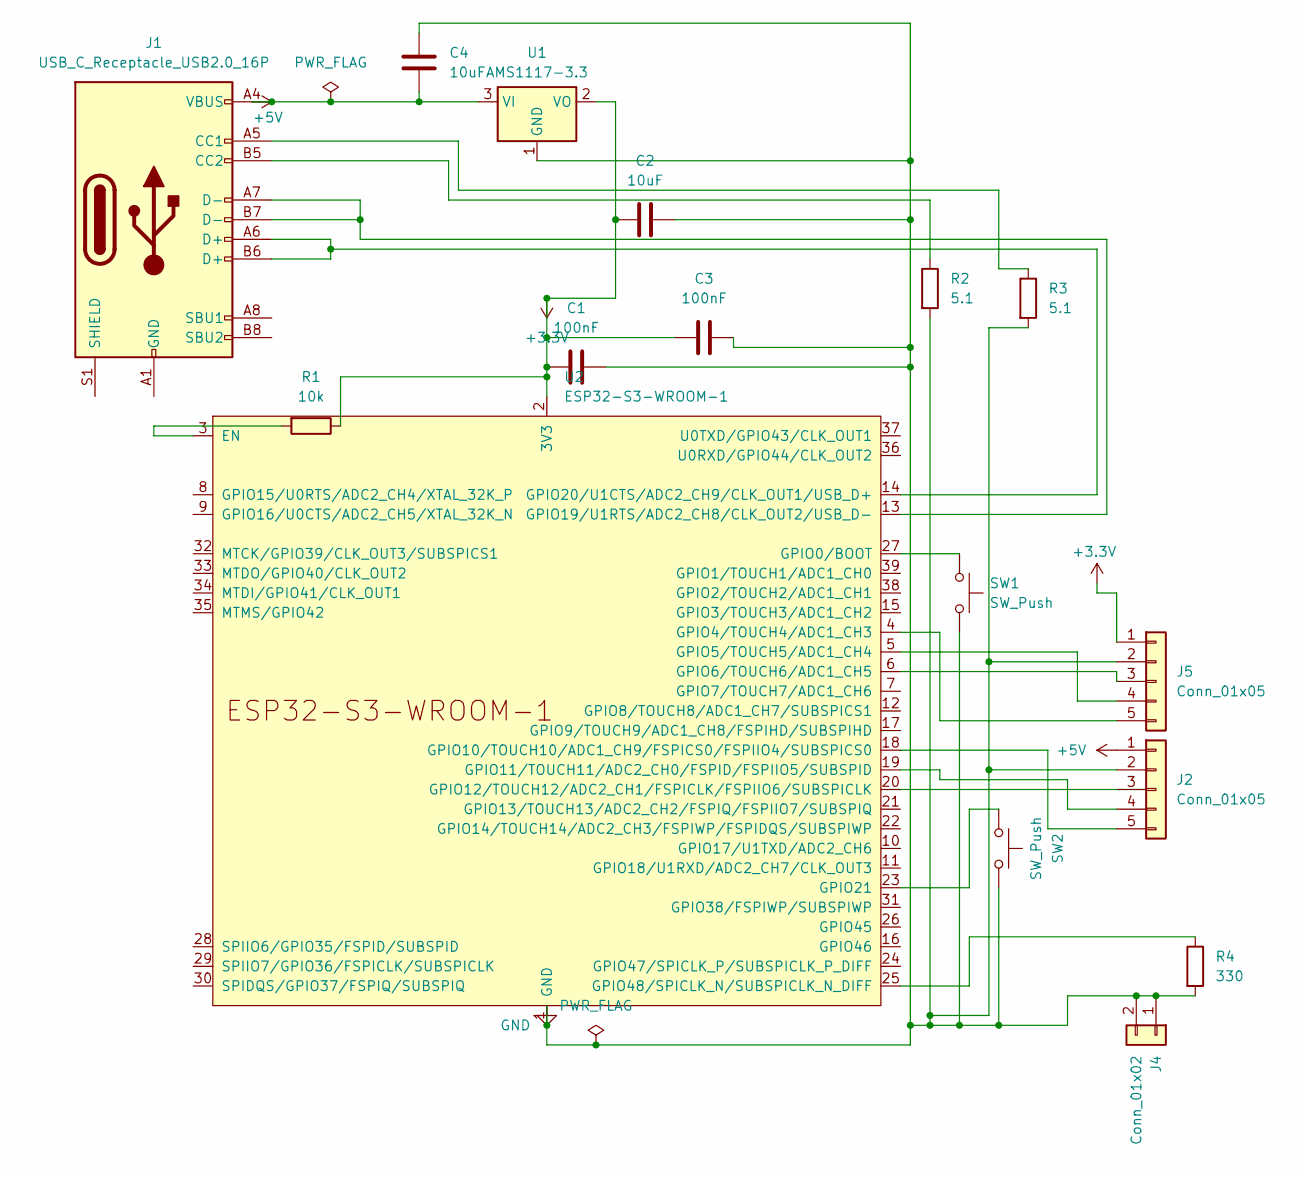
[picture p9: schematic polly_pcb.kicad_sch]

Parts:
C1, C3: 100nF; C_0805_2012Metric
C2, C4: 10uF; C_0805_2012Metric
J1: USB_C_Receptacle_USB2.0_16P; USB_C_Receptacle_HRO_TYPE-C-31-M-12
J2, J5: Conn_01x05; PinHeader_1x05_P2.54mm_Vertical
J4: Conn_01x02; PinHeader_1x02_P2.54mm_Vertical
R1: 10k; R_0805_2012Metric
R2, R3: 5.1; R_0805_2012Metric
R4: 330; R_0805_2012Metric
SW1, SW2: SW_Push; SW_SPST_PTS645Sx43SMTR92
U1: AMS1117-3.3; SOT-223-3_TabPin2
U2: ESP32-S3-WROOM-1

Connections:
+3.3V: C1.2, C2.2, C3.2, J5.1, R1.1, U1.2 (VO), U2.2 (3V3)
+5V: C4.2, J1.A4 (VBUS), J1.A9 (VBUS), J1.B4 (VBUS), J1.B9 (VBUS), J2.1, U1.3 (VI)
GND: C1.1, C2.1, C3.1, C4.1, J2.2, J4.1, J4.2, J5.2, R2.2, R3.2, R4.2, SW1.2, SW2.2, U1.1 (GND), U2.1 (GND), U2.40 (GND), U2.41 (GND)
unnamed: J1.A5 (CC1), R3.1
unnamed: J1.B5 (CC2), R2.1
unnamed: J1.A1 (GND), J1.A12 (GND), J1.B1 (GND), J1.B12 (GND)
unnamed: J2.3, U2.20 (GPIO12/TOUCH12/ADC2_CH1/FSPICLK/FSPIIO6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)
unnamed: J2.4, U2.19 (GPIO11/TOUCH11/ADC2_CH0/FSPID/FSPIIO5/S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)
unnamed: J2.5, U2.18 (GPIO10/TOUCH10/ADC1_CH9/FSPICS0/FSPIIO4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)
unnamed: J5.3, U2.6 (GPIO6/TOUCH6/ADC1_CH5)
unnamed: J5.4, U2.5 (GPIO5/TOUCH5/ADC1_CH4)
unnamed: J5.5, U2.4 (GPIO4/TOUCH4/ADC1_CH3)
unnamed: R1.2, U2.3 (EN)
unnamed: SW1.1, U2.27 (GPIO0/BOOT)
unnamed: J1.A7 (D-), J1.B7 (D-), U2.13 (GPIO19/U1RTS/ADC2_CH8/CLK_OUT2/USB_D-)
unnamed: J1.A6 (D+), J1.B6 (D+), U2.14 (GPIO20/U1CTS/ADC2_CH9/CLK_OUT1/USB_D+)
unnamed: SW2.1, U2.23 (GPIO21)
unnamed: R4.1, U2.25 (GPIO48/SPICLK_N/SUBSPICLK_N_DIFF)

Board: 2 copper layers, 16 parts (0 on the bottom side), 18 nets, no tracks yet.

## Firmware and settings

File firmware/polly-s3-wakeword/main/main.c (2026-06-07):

/**
 * Polly Connect - ESP32-S3 WebSocket Streaming Firmware
 *
 * Hardware: ESP32-S3-WROOM-1-N16R8 + INMP441 mic + MAX98357A speaker
 *
 * Flow:
 *   1. Boot -> init I2S mic/speaker -> init WiFi
 *   2. Connect WebSocket to server (/api/audio/continuous)
 *   3. Continuously stream mic audio (binary frames) to server
 *   4. Server runs OpenWakeWord -> sends wake_word_detected
 *   5. Server records until silence, runs Whisper STT -> intent -> TTS
 *   6. Server sends response text + audio_chunk frames back
 *   7. ESP32 plays TTS audio, resumes streaming
 *
 * GPIO Wiring (INMP441):
 *   SCK  -> GPIO6
 *   WS   -> GPIO5
 *   SD   -> GPIO4
 *   L/R  -> GND (left channel)
 *   VDD  -> 3.3V
 *   GND  -> GND
 *
 * GPIO Wiring (MAX98357A speaker amp):
 *   BCLK -> GPIO12
 *   LRC  -> GPIO11
 *   DIN  -> GPIO10
 *   VIN  -> 5V
 *   GND  -> GND
 */

#include <stdio.h>
#include <string.h>
#include <math.h>
#include <inttypes.h>

#include "freertos/FreeRTOS.h"
#include "freertos/task.h"
#include "freertos/event_groups.h"
#include "freertos/semphr.h"

#include "esp_log.h"
#include "esp_err.h"
#include "esp_system.h"
#include "esp_wifi.h"
#include "esp_event.h"
#include "nvs_flash.h"

#include "driver/i2s_std.h"
#include "driver/gpio.h"
#include "led_strip.h"

#include "esp_websocket_client.h"
#include "cJSON.h"
#include "mbedtls/base64.h"
#include "esp_http_server.h"
#include "esp_netif.h"
#include "lwip/sockets.h"
#include "esp_ota_ops.h"
#include "esp_http_client.h"
#include "esp_app_format.h"

static const char *TAG = "POLLY";

/* --- Configuration --- */

// Firmware version (for OTA updates)
#define FW_VERSION      "1.0.2"
#define FW_VARIANT      "breadboard"

// WiFi
#define WIFI_SSID       "SpectrumSetup-73"
#define WIFI_PASSWORD   "orangegate448"
#define WIFI_MAX_RETRY  10
#define WIFI_MAX_SAVED  5   // Max remembered WiFi networks

// Server
#define SERVER_HOST     "polly-connect.com"
#define SERVER_PORT     8000
#define WS_URI          "ws://" SERVER_HOST ":8000/api/audio/continuous"

// Device identity & API key (change these per-device when flashing)
#define DEVICE_ID       "polly001"
#define DEVICE_API_KEY  "oyiyfCEOd0QXTv5EPL8f9XBnFkNDAp8UwoTi5yRzAVw"  // polly001 registered to tenant 1 (Glen)

// I2S Microphone (INMP441) pins
#define I2S_MIC_SCK     GPIO_NUM_6
#define I2S_MIC_WS      GPIO_NUM_5
#define I2S_MIC_SD      GPIO_NUM_4

// I2S Speaker (MAX98357A) pins
#define I2S_SPK_BCLK    GPIO_NUM_12
#define I2S_SPK_LRC     GPIO_NUM_11
#define I2S_SPK_DIN     GPIO_NUM_10

// Audio
#define SAMPLE_RATE     16000
#define CHUNK_SAMPLES   480         // 30ms chunks for streaming
#define CHUNK_BYTES     (CHUNK_SAMPLES * sizeof(int16_t))  // 960 bytes

// Status LED (built-in on most S3 devkits)
#define LED_PIN         GPIO_NUM_48

// Story mode button (GPIO0 = BOOT button, free during runtime)
#define STORY_BUTTON    GPIO_NUM_0
#define DEBOUNCE_MS     300

// WebSocket
#define WS_BUFFER_SIZE  4096        // 4KB buffer (smaller = less memory pressure)
#define WS_RECONNECT_MS 5000

// Response audio buffer (30 seconds max, in PSRAM)
#define RESPONSE_AUDIO_MAX (SAMPLE_RATE * 2 * 30)  // 960000 bytes

/* --- Globals --- */

static i2s_chan_handle_t mic_handle = NULL;
static i2s_chan_handle_t spk_handle = NULL;

static EventGroupHandle_t wifi_event_group;
#define WIFI_CONNECTED_BIT BIT0
static int wifi_retry_count = 0;

static esp_websocket_client_handle_t ws_client = NULL;
static volatile bool ws_connected = false;
static volatile bool ota_in_progress = false;

// Flags set by WebSocket event handler, consumed by streaming task
static volatile bool wake_detected = false;
static volatile bool streaming_paused = false;

// Story recording state
static volatile bool story_recording = false;
static volatile bool story_button_pressed = false;
static uint32_t last_button_time = 0;

// Response audio accumulation (PSRAM)
static uint8_t *response_audio = NULL;
static size_t response_audio_len = 0;
static SemaphoreHandle_t response_mutex = NULL;
static volatile bool response_complete = false;

// JSON message accumulation (for fragmented WebSocket messages)
static char *msg_accum = NULL;
static size_t msg_accum_len = 0;
#define MSG_ACCUM_SIZE  32768       // 32KB


/* --- RGB LED (WS2812 on GPIO48) --- */

static led_strip_handle_t led_strip = NULL;

typedef enum {
    LED_OFF = 0,        // Idle — waiting for wake word
    LED_GREEN,          // Listening — wake word detected, recording
    LED_WHITE_PULSE,    // Thinking — sent to server, waiting for response
    LED_BLUE,           // Playing — speaking back
    LED_RED,            // Disconnected / error
    LED_RED_BLINK,      // Provisioning mode
    LED_YELLOW,         // Story recording
} led_state_t;

static volatile led_state_t current_led_state = LED_OFF;

static void led_init(void)
{
    led_strip_config_t strip_config = {
        .strip_gpio_num = LED_PIN,
        .max_leds = 1,
        .led_model = LED_MODEL_WS2812,
        .color_component_format = LED_STRIP_COLOR_COMPONENT_FMT_GRB,
        .flags.invert_out = false,
    };
    led_strip_rmt_config_t rmt_config = {
        .clk_src = RMT_CLK_SRC_DEFAULT,
        .resolution_hz = 10 * 1000 * 1000,
        .flags.with_dma = false,
    };
    ESP_ERROR_CHECK(led_strip_new_rmt_device(&strip_config, &rmt_config, &led_strip));
    led_strip_clear(led_strip);
}

static void led_rgb(uint8_t r, uint8_t g, uint8_t b)
{
    if (!led_strip) return;
    led_strip_set_pixel(led_strip, 0, r, g, b);
    led_strip_refresh(led_strip);
}

static void led_set(int on)
{
    if (on) {
        current_led_state = LED_GREEN;
        led_rgb(0, 40, 0);
    } else {
        current_led_state = LED_OFF;
        led_rgb(0, 0, 0);
    }
}

static void led_pulse_task(void *arg)
{
    // Smooth breathing effect: fade up and down while in WHITE_PULSE state
    int brightness = 0;
    int direction = 2;  // step size per tick
    while (1) {
        if (current_led_state != LED_WHITE_PULSE) {
            vTaskDelay(pdMS_TO_TICKS(50));
            continue;
        }
        brightness += direction;
        if (brightness >= 40) { brightness = 40; direction = -2; }
        if (brightness <= 3) { brightness = 3; direction = 2; }
        led_rgb(brightness, brightness, brightness);
        vTaskDelay(pdMS_TO_TICKS(30));  // ~33fps, smooth pulse
    }
}

static void led_state_set(led_state_t state)
{
    current_led_state = state;
    switch (state) {
        case LED_OFF:          led_rgb(0, 0, 0);      break;
        case LED_GREEN:        led_rgb(0, 40, 0);     break;
        case LED_WHITE_PULSE:  break;  // Pulse task handles this
        case LED_BLUE:         led_rgb(0, 0, 40);     break;
        case LED_RED:          led_rgb(40, 0, 0);     break;
        case LED_RED_BLINK:    led_rgb(40, 0, 0);     break;
        case LED_YELLOW:       led_rgb(40, 30, 0);    break;
    }
}


/* --- Story Button (GPIO0 / BOOT) --- */

static void IRAM_ATTR story_button_isr(void *arg)
{
    uint32_t now = xTaskGetTickCountFromISR();
    if ((now - last_button_time) > pdMS_TO_TICKS(DEBOUNCE_MS)) {
        last_button_time = now;
        story_button_pressed = true;
    }
}

static void story_button_init(void)
{
    gpio_config_t btn_cfg = {
        .pin_bit_mask = (1ULL << STORY_BUTTON),
        .mode = GPIO_MODE_INPUT,
        .pull_up_en = GPIO_PULLUP_ENABLE,
        .pull_down_en = GPIO_PULLDOWN_DISABLE,
        .intr_type = GPIO_INTR_NEGEDGE,  // button press = falling edge (active low)
    };
    gpio_config(&btn_cfg);
    gpio_install_isr_service(0);
    gpio_isr_handler_add(STORY_BUTTON, story_button_isr, NULL);
    ESP_LOGI(TAG, "Story button initialized on GPIO%d", STORY_BUTTON);
}


/* --- I2S Microphone --- */

static esp_err_t mic_init(void)
{
    i2s_chan_config_t chan_cfg = I2S_CHANNEL_DEFAULT_CONFIG(I2S_NUM_0, I2S_ROLE_MASTER);
    chan_cfg.dma_desc_num = 8;
    chan_cfg.dma_frame_num = 480;

    ESP_ERROR_CHECK(i2s_new_channel(&chan_cfg, NULL, &mic_handle));

    i2s_std_config_t std_cfg = {
        .clk_cfg = I2S_STD_CLK_DEFAULT_CONFIG(SAMPLE_RATE),
        .slot_cfg = I2S_STD_PHILIPS_SLOT_DEFAULT_CONFIG(I2S_DATA_BIT_WIDTH_16BIT, I2S_SLOT_MODE_MONO),
        .gpio_cfg = {
            .mclk = I2S_GPIO_UNUSED,
            .bclk = I2S_MIC_SCK,
            .ws   = I2S_MIC_WS,
            .dout = I2S_GPIO_UNUSED,
            .din  = I2S_MIC_SD,
            .invert_flags = {
                .mclk_inv = false,
                .bclk_inv = false,
                .ws_inv   = false,
            },
        },
    };
    std_cfg.slot_cfg.slot_mask = I2S_STD_SLOT_LEFT;

    ESP_ERROR_CHECK(i2s_channel_init_std_mode(mic_handle, &std_cfg));
    ESP_ERROR_CHECK(i2s_channel_enable(mic_handle));

    ESP_LOGI(TAG, "Microphone initialized (INMP441 on GPIO %d/%d/%d)",
             I2S_MIC_SCK, I2S_MIC_WS, I2S_MIC_SD);
    return ESP_OK;
}

static size_t mic_read(int16_t *buffer, size_t samples)
{
    size_t bytes_read = 0;
    esp_err_t ret = i2s_channel_read(mic_handle, buffer, samples * sizeof(int16_t),
                                      &bytes_read, pdMS_TO_TICKS(100));
    if (ret != ESP_OK) {
        ESP_LOGE(TAG, "Mic read error: %s", esp_err_to_name(ret));
        return 0;
    }
    return bytes_read / sizeof(int16_t);
}


/* --- I2S Speaker --- */

static esp_err_t spk_init(void)
{
    i2s_chan_config_t chan_cfg = I2S_CHANNEL_DEFAULT_CONFIG(I2S_NUM_1, I2S_ROLE_MASTER);
    chan_cfg.dma_desc_num = 8;
    chan_cfg.dma_frame_num = 480;

    ESP_ERROR_CHECK(i2s_new_channel(&chan_cfg, &spk_handle, NULL));

    i2s_std_config_t std_cfg = {
        .clk_cfg = I2S_STD_CLK_DEFAULT_CONFIG(SAMPLE_RATE),
        .slot_cfg = I2S_STD_PHILIPS_SLOT_DEFAULT_CONFIG(I2S_DATA_BIT_WIDTH_16BIT, I2S_SLOT_MODE_MONO),
        .gpio_cfg = {
            .mclk = I2S_GPIO_UNUSED,
            .bclk = I2S_SPK_BCLK,
            .ws   = I2S_SPK_LRC,
            .dout = I2S_SPK_DIN,
            .din  = I2S_GPIO_UNUSED,
            .invert_flags = {
                .mclk_inv = false,
                .bclk_inv = false,
                .ws_inv   = false,
            },
        },
    };

    ESP_ERROR_CHECK(i2s_channel_init_std_mode(spk_handle, &std_cfg));
    ESP_ERROR_CHECK(i2s_channel_enable(spk_handle));

    ESP_LOGI(TAG, "Speaker initialized (MAX98357A on GPIO %d/%d/%d)",
             I2S_SPK_BCLK, I2S_SPK_LRC, I2S_SPK_DIN);
    return ESP_OK;
}

static void spk_play_tone(int freq_hz, int duration_ms)
{
    int total_samples = SAMPLE_RATE * duration_ms / 1000;
    int16_t *tone = heap_caps_malloc(total_samples * sizeof(int16_t), MALLOC_CAP_SPIRAM);
    if (!tone) return;

    for (int i = 0; i < total_samples; i++) {
        float t = (float)i / SAMPLE_RATE;
        float envelope = 1.0f;
        if (i < 200) envelope = (float)i / 200.0f;
        if (i > total_samples - 200) envelope = (float)(total_samples - i) / 200.0f;
        tone[i] = (int16_t)(sinf(2.0f * M_PI * freq_hz * t) * 8000.0f * envelope);
    }

    size_t written = 0;
    i2s_channel_write(spk_handle, tone, total_samples * sizeof(int16_t), &written, pdMS_TO_TICKS(2000));
    heap_caps_free(tone);
}

static void spk_play_wake_sound(void)
{
    spk_play_tone(800, 80);
    vTaskDelay(pdMS_TO_TICKS(30));
    spk_play_tone(1200, 80);
}


/* --- WiFi --- */

// Provisioning state
static SemaphoreHandle_t provision_done_sem = NULL;
static esp_netif_t *sta_netif = NULL;
static esp_netif_t *ap_netif = NULL;
static httpd_handle_t portal_server = NULL;
static TaskHandle_t dns_task_handle = NULL;
// --- NVS helpers (multi-network) ---

typedef struct {
    char ssid[33];
    char pass[65];
} wifi_cred_t;

static int wifi_nvs_load_all(wifi_cred_t *creds, int max_creds)
{
    nvs_handle_t h;
    if (nvs_open("wifi_cfg", NVS_READONLY, &h) != ESP_OK) return 0;
    uint8_t count = 0;
    nvs_get_u8(h, "count", &count);
    if (count > max_creds) count = max_creds;
    int loaded = 0;
    for (int i = 0; i < count; i++) {
        char key_s[16], key_p[16];
        snprintf(key_s, sizeof(key_s), "ssid%d", i);
        snprintf(key_p, sizeof(key_p), "pass%d", i);
        size_t s_len = sizeof(creds[loaded].ssid);
        size_t p_len = sizeof(creds[loaded].pass);
        esp_err_t r1 = nvs_get_str(h, key_s, creds[loaded].ssid, &s_len);
        esp_err_t r2 = nvs_get_str(h, key_p, creds[loaded].pass, &p_len);
        if (r1 == ESP_OK && r2 == ESP_OK && strlen(creds[loaded].ssid) > 0) {
            ESP_LOGI(TAG, "NVS slot %d: '%s'", i, creds[loaded].ssid);
            loaded++;
        }
    }
    nvs_close(h);
    return loaded;
}

static esp_err_t wifi_nvs_save(const char *ssid, const char *pass)
{
    wifi_cred_t creds[WIFI_MAX_SAVED] = {0};
    int count = wifi_nvs_load_all(creds, WIFI_MAX_SAVED);

    for (int i = 0; i < count; i++) {
        if (strcmp(creds[i].ssid, ssid) == 0) {
            strncpy(creds[i].pass, pass, sizeof(creds[i].pass) - 1);
            ESP_LOGI(TAG, "Updated password for '%s' (slot %d)", ssid, i);
            goto save;
        }
    }

    if (count < WIFI_MAX_SAVED) {
        strncpy(creds[count].ssid, ssid, sizeof(creds[count].ssid) - 1);
        strncpy(creds[count].pass, pass, sizeof(creds[count].pass) - 1);
        count++;
        ESP_LOGI(TAG, "Added '%s' (slot %d)", ssid, count - 1);
    } else {
        for (int i = 0; i < WIFI_MAX_SAVED - 1; i++) {
            creds[i] = creds[i + 1];
        }
        strncpy(creds[WIFI_MAX_SAVED - 1].ssid, ssid, sizeof(creds[WIFI_MAX_SAVED - 1].ssid) - 1);
        strncpy(creds[WIFI_MAX_SAVED - 1].pass, pass, sizeof(creds[WIFI_MAX_SAVED - 1].pass) - 1);
        ESP_LOGI(TAG, "Replaced oldest, added '%s' (slot %d)", ssid, WIFI_MAX_SAVED - 1);
    }

save:;
    nvs_handle_t h;
    ESP_ERROR_CHECK(nvs_open("wifi_cfg", NVS_READWRITE, &h));
    nvs_set_u8(h, "count", (uint8_t)count);
    for (int i = 0; i < count; i++) {
        char key_s[16], key_p[16];
        snprintf(key_s, sizeof(key_s), "ssid%d", i);
        snprintf(key_p, sizeof(key_p), "pass%d", i);
        nvs_set_str(h, key_s, creds[i].ssid);
        nvs_set_str(h, key_p, creds[i].pass);
    }
    nvs_commit(h);
    nvs_close(h);
    ESP_LOGI(TAG, "Saved %d WiFi network(s) to NVS", count);
    return ESP_OK;
}

static esp_err_t wifi_nvs_clear(void)
{
    nvs_handle_t h;
    ESP_ERROR_CHECK(nvs_open("wifi_cfg", NVS_READWRITE, &h));
    nvs_erase_all(h);
    nvs_commit(h);
    nvs_close(h);
    ESP_LOGI(TAG, "WiFi credentials cleared from NVS");
    return ESP_OK;
}

// --- STA connection ---

static esp_event_handler_instance_t sta_any_id_handle, sta_got_ip_handle;
static bool sta_initialized = false;

static void wifi_event_handler(void *arg, esp_event_base_t event_base,
                                int32_t event_id, void *event_data)
{
    if (event_base == WIFI_EVENT && event_id == WIFI_EVENT_STA_START) {
        esp_wifi_connect();
    } else if (event_base == WIFI_EVENT && event_id == WIFI_EVENT_STA_DISCONNECTED) {
        if (wifi_retry_count < WIFI_MAX_RETRY) {
            esp_wifi_connect();
            wifi_retry_count++;
            ESP_LOGI(TAG, "WiFi retry %d/%d", wifi_retry_count, WIFI_MAX_RETRY);
        } else {
            ESP_LOGE(TAG, "WiFi connection failed after %d retries", WIFI_MAX_RETRY);
        }
    } else if (event_base == IP_EVENT && event_id == IP_EVENT_STA_GOT_IP) {
        ip_event_got_ip_t *event = (ip_event_got_ip_t *)event_data;
        ESP_LOGI(TAG, "WiFi connected! IP: " IPSTR, IP2STR(&event->ip_info.ip));
        wifi_retry_count = 0;
        xEventGroupSetBits(wifi_event_group, WIFI_CONNECTED_BIT);
    }
}

static void wifi_sta_init(void)
{
    if (sta_initialized) return;
    wifi_event_group = xEventGroupCreate();
    ESP_ERROR_CHECK(esp_netif_init());
    ESP_ERROR_CHECK(esp_event_loop_create_default());
    sta_netif = esp_netif_create_default_wifi_sta();

    wifi_init_config_t cfg = WIFI_INIT_CONFIG_DEFAULT();
    ESP_ERROR_CHECK(esp_wifi_init(&cfg));

    ESP_ERROR_CHECK(esp_event_handler_instance_register(WIFI_EVENT, ESP_EVENT_ANY_ID,
                                                         &wifi_event_handler, NULL, &sta_any_id_handle));
    ESP_ERROR_CHECK(esp_event_handler_instance_register(IP_EVENT, IP_EVENT_STA_GOT_IP,
                                                         &wifi_event_handler, NULL, &sta_got_ip_handle));
    sta_initialized = true;
}

static void wifi_sta_deinit(void)
{
    if (!sta_initialized) return;
    esp_wifi_stop();
    esp_wifi_deinit();
    esp_event_handler_instance_unregister(WIFI_EVENT, ESP_EVENT_ANY_ID, sta_any_id_handle);
    esp_event_handler_instance_unregister(IP_EVENT, IP_EVENT_STA_GOT_IP, sta_got_ip_handle);
    esp_event_loop_delete_default();
    esp_netif_destroy_default_wifi(sta_netif);
    sta_netif = NULL;
    vEventGroupDelete(wifi_event_group);
    wifi_event_group = NULL;
    sta_initialized = false;
}

static bool wifi_try_connect(const char *ssid, const char *pass)
{
    ESP_LOGI(TAG, "Trying WiFi: '%s'", ssid);
    wifi_retry_count = 0;
    xEventGroupClearBits(wifi_event_group, WIFI_CONNECTED_BIT);

    wifi_config_t wifi_config = {0};
    strncpy((char *)wifi_config.sta.ssid, ssid, sizeof(wifi_config.sta.ssid) - 1);
    strncpy((char *)wifi_config.sta.password, pass, sizeof(wifi_config.sta.password) - 1);
    wifi_config.sta.threshold.authmode = WIFI_AUTH_WPA2_PSK;
    wifi_config.sta.pmf_cfg.capable = true;
    wifi_config.sta.pmf_cfg.required = false;
    wifi_config.sta.scan_method = WIFI_ALL_CHANNEL_SCAN;
    wifi_config.sta.sort_method = WIFI_CONNECT_AP_BY_SIGNAL;

    esp_wifi_stop();
    ESP_ERROR_CHECK(esp_wifi_set_mode(WIFI_MODE_STA));
    ESP_ERROR_CHECK(esp_wifi_set_config(WIFI_IF_STA, &wifi_config));
    ESP_ERROR_CHECK(esp_wifi_start());
    esp_wifi_set_ps(WIFI_PS_NONE);  // keep WiFi fully awake — prevents stale/half-dead connections

    EventBits_t bits = xEventGroupWaitBits(wifi_event_group, WIFI_CONNECTED_BIT,
                                            pdFALSE, pdFALSE, pdMS_TO_TICKS(15000));
    if (bits & WIFI_CONNECTED_BIT) {
        return true;
    }

    ESP_LOGW(TAG, "WiFi '%s' failed", ssid);
    return false;
}
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
void app_main(void)
{
    ESP_LOGI(TAG, "=== Polly Connect - ESP32-S3 WebSocket Streaming ===");
    ESP_LOGI(TAG, "Firmware: v%s (%s)", FW_VERSION, FW_VARIANT);
    ESP_LOGI(TAG, "Free heap: %u bytes", (unsigned)esp_get_free_heap_size());
    ESP_LOGI(TAG, "Free PSRAM: %u bytes", (unsigned)heap_caps_get_free_size(MALLOC_CAP_SPIRAM));

    // Init NVS (needed for WiFi)
    esp_err_t ret = nvs_flash_init();
    if (ret == ESP_ERR_NVS_NO_FREE_PAGES || ret == ESP_ERR_NVS_NEW_VERSION_FOUND) {
        ESP_ERROR_CHECK(nvs_flash_erase());
        ret = nvs_flash_init();
    }
    ESP_ERROR_CHECK(ret);

    // OTA rollback validation
    const esp_partition_t *running = esp_ota_get_running_partition();
    esp_ota_img_states_t ota_state;
    if (esp_ota_get_state_partition(running, &ota_state) == ESP_OK) {
        if (ota_state == ESP_OTA_IMG_PENDING_VERIFY) {
            ESP_LOGI(TAG, "OTA: First boot after update — marking firmware valid");
            esp_ota_mark_app_valid_cancel_rollback();
        }
    }
    ESP_LOGI(TAG, "Running from partition: %s", running->label);

    // Init RGB LED + pulse task
    led_init();
    xTaskCreate(led_pulse_task, "led_pulse", 2048, NULL, 1, NULL);
    led_state_set(LED_WHITE_PULSE);  // White = booting up

    // Init microphone
    ESP_ERROR_CHECK(mic_init());

    // Init speaker
    ESP_ERROR_CHECK(spk_init());

    // Init WiFi (with provisioning — checks NVS, fallback to AP captive portal)
    // Note: story_button_init() moved AFTER wifi because wifi_provision_init
    // reads GPIO0 for force-provisioning before ISR is installed
    wifi_provision_init();

    // Init story button (after WiFi so GPIO0 check for provisioning works)
    story_button_init();

    // Allocate response audio buffer in PSRAM
    response_audio = heap_caps_malloc(RESPONSE_AUDIO_MAX, MALLOC_CAP_SPIRAM);
    if (!response_audio) {
        ESP_LOGE(TAG, "Failed to allocate response audio buffer!");
        return;
    }
    response_mutex = xSemaphoreCreateMutex();

    // Allocate JSON message accumulation buffer
    msg_accum = heap_caps_malloc(MSG_ACCUM_SIZE, MALLOC_CAP_SPIRAM);
    if (!msg_accum) {
        ESP_LOGE(TAG, "Failed to allocate message buffer!");
        return;
    }
    msg_accum[0] = '\0';

    // Init WebSocket client
    ESP_ERROR_CHECK(ws_init());

    led_state_set(LED_OFF);  // Ready — waiting for wake word
    ESP_LOGI(TAG, "Setup complete. Streaming audio to server...");

    // Start mic streaming task on core 1 (core 0 handles WiFi/WebSocket)
    xTaskCreatePinnedToCore(mic_stream_task, "mic_stream", 8192, NULL, 5, NULL, 1);

    // Start OTA update checker (low priority, checks every hour)
    xTaskCreate(ota_check_task, "ota_check", 8192, NULL, 2, NULL);
}

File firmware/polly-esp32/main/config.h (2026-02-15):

#ifndef CONFIG_H
#define CONFIG_H

#include "driver/gpio.h"

// WiFi Configuration
#define WIFI_SSID           CONFIG_WIFI_SSID
#define WIFI_PASSWORD       CONFIG_WIFI_PASSWORD
#define MAX_RETRY           CONFIG_WIFI_MAXIMUM_RETRY

// Server Configuration
#define SERVER_URI          CONFIG_SERVER_URI

// Audio Configuration
#define SAMPLE_RATE         16000
#define BITS_PER_SAMPLE     16
#define CHANNELS            1
#define FRAME_SIZE          512        // Porcupine frame size
#define FRAME_SIZE_BYTES    (FRAME_SIZE * 2)

// Buffer Configuration
#define AUDIO_BUFFER_SECS   CONFIG_AUDIO_BUFFER_SECONDS
#define AUDIO_BUFFER_SIZE   (SAMPLE_RATE * AUDIO_BUFFER_SECS * 2)

// GPIO Configuration (INMP441)
#define I2S_WS              GPIO_NUM_42
#define I2S_SD              GPIO_NUM_41
#define I2S_SCK             GPIO_NUM_40

// Porcupine Configuration
#define PORCUPINE_ACCESS_KEY    CONFIG_PORCUPINE_ACCESS_KEY
#define PORCUPINE_SENSITIVITY   0.5f

// Task Configuration
#define TASK_STACK_AUDIO        (8 * 1024)
#define TASK_STACK_WAKE         (16 * 1024)
#define TASK_STACK_STREAM       (8 * 1024)
#define TASK_STACK_WEBSOCKET    (8 * 1024)

// Task Priorities
#define TASK_PRIORITY_AUDIO     5
#define TASK_PRIORITY_WAKE      6
#define TASK_PRIORITY_STREAM    5
#define TASK_PRIORITY_WEBSOCKET 4

// Audio streaming configuration
#define STREAMING_DURATION_SEC  5      // Maximum command duration in seconds
#define STREAMING_MAX_FRAMES    ((STREAMING_DURATION_SEC * SAMPLE_RATE) / FRAME_SIZE)

#endif // CONFIG_H

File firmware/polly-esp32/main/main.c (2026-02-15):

#include <stdio.h>
#include <string.h>
#include "freertos/FreeRTOS.h"
#include "freertos/task.h"
#include "freertos/queue.h"
#include "esp_log.h"
#include "esp_system.h"
#include "nvs_flash.h"
#include "esp_heap_caps.h"
#include "mbedtls/base64.h"

#include "config.h"
#include "wifi_manager.h"
#include "websocket_client.h"
#include "audio_capture.h"
#include "porcupine_manager.h"
#include "state_machine.h"

static const char *TAG = "main";

// Global handles
static QueueHandle_t audio_queue = NULL;
static porcupine_ctx_t porcupine_ctx;
static TaskHandle_t streaming_task_handle = NULL;

/**
 * Wake word detection task
 * Processes audio frames and detects wake word using Porcupine
 */
void wake_word_task(void *pvParameters)
{
    int16_t *frame = heap_caps_malloc(FRAME_SIZE * sizeof(int16_t),
                                       MALLOC_CAP_8BIT);
    if (!frame) {
        ESP_LOGE(TAG, "Failed to allocate frame buffer for wake word task");
        vTaskDelete(NULL);
        return;
    }

    ESP_LOGI(TAG, "Wake word task started");

    while (1) {
        // Wait for audio frame from capture task
        if (xQueueReceive(audio_queue, frame, portMAX_DELAY) == pdTRUE) {
            // Only process wake word when in IDLE state
            if (state_machine_get() == STATE_IDLE) {
                bool detected = porcupine_process_frame(&porcupine_ctx, frame);

                if (detected) {
                    ESP_LOGI(TAG, "WAKE WORD DETECTED!");

                    // Transition to wake detected state
                    state_machine_set(STATE_WAKE_DETECTED);

                    // Notify streaming task
                    if (streaming_task_handle) {
                        xTaskNotifyGive(streaming_task_handle);
                    }
                }
            }
        }
    }

    free(frame);
    vTaskDelete(NULL);
}

/**
 * Audio streaming task
 * Streams audio to server after wake word detection
 */
void audio_streaming_task(void *pvParameters)
{
    ESP_LOGI(TAG, "Streaming task started");

    // Allocate buffer for Base64 encoding
    uint8_t *base64_buffer = heap_caps_malloc(2048, MALLOC_CAP_8BIT);
    if (!base64_buffer) {
        ESP_LOGE(TAG, "Failed to allocate base64 buffer");
        vTaskDelete(NULL);
        return;
    }

    int16_t *prebuffer = NULL;
    size_t prebuffer_frames = 0;

    while (1) {
        // Wait for wake word notification
        ulTaskNotifyTake(pdTRUE, portMAX_DELAY);

        ESP_LOGI(TAG, "Starting audio streaming...");

        // Send wake_word_detected event to server
        websocket_send_wake_detected();

        // Get pre-buffered audio (audio captured before wake word)
        prebuffer = audio_capture_get_prebuffer(&prebuffer_frames);
        size_t buffer_idx = audio_capture_get_buffer_index();

        ESP_LOGI(TAG, "Streaming %d frames of pre-buffered audio", prebuffer_frames);

        // Stream pre-buffered audio in correct order (oldest to newest)
        for (size_t i = 0; i < prebuffer_frames; i++) {
            size_t idx = (buffer_idx + i) % prebuffer_frames;
            int16_t *frame_ptr = &prebuffer[idx * FRAME_SIZE];

            // Base64 encode the frame
            size_t b64_len = 0;
            int ret = mbedtls_base64_encode(base64_buffer, 2048, &b64_len,
                                           (const uint8_t *)frame_ptr,
                                           FRAME_SIZE_BYTES);

            if (ret == 0) {
                base64_buffer[b64_len] = '\0';
                websocket_send_audio(base64_buffer, b64_len);
            }

            vTaskDelay(pdMS_TO_TICKS(5));  // Small delay to avoid overwhelming server
        }

        ESP_LOGI(TAG, "Streaming live audio (max %d seconds)...", STREAMING_DURATION_SEC);

        // Stream live audio for specified duration
        int frames_sent = 0;
        int16_t *live_frame = heap_caps_malloc(FRAME_SIZE * sizeof(int16_t),
                                                MALLOC_CAP_8BIT);

        if (live_frame) {
            while (frames_sent < STREAMING_MAX_FRAMES &&
                   state_machine_get() == STATE_WAKE_DETECTED) {
                if (xQueueReceive(audio_queue, live_frame, pdMS_TO_TICKS(100)) == pdTRUE) {
                    // Base64 encode
                    size_t b64_len = 0;
                    int ret = mbedtls_base64_encode(base64_buffer, 2048, &b64_len,
                                                   (const uint8_t *)live_frame,
                                                   FRAME_SIZE_BYTES);

                    if (ret == 0) {
                        base64_buffer[b64_len] = '\0';
                        websocket_send_audio(base64_buffer, b64_len);
                    }

                    frames_sent++;
                }
            }

            free(live_frame);
        }

        // Send command_end event
        websocket_send_command_end();
        ESP_LOGI(TAG, "Audio streaming complete (%d live frames sent)", frames_sent);

        // Transition to processing state (waiting for server response)
        state_machine_set(STATE_PROCESSING);

        // Wait a bit then return to IDLE
        vTaskDelay(pdMS_TO_TICKS(2000));
        state_machine_set(STATE_IDLE);
        ESP_LOGI(TAG, "Ready for next wake word");
    }

    free(base64_buffer);
    vTaskDelete(NULL);
}

/**
 * WebSocket event callback
 * Handles events received from server
 */
void websocket_event_callback(cJSON *event)
{
    cJSON *event_type = cJSON_GetObjectItem(event, "event");
    if (!event_type || !cJSON_IsString(event_type)) {
        return;
    }

    const char *type = event_type->valuestring;

    if (strcmp(type, "connected") == 0) {
        ESP_LOGI(TAG, "Server acknowledged connection");
        state_machine_set(STATE_IDLE);
        ESP_LOGI(TAG, "Ready to detect wake word");

    } else if (strcmp(type, "wake_ack") == 0) {
        ESP_LOGI(TAG, "Server acknowledged wake word");

    } else if (strcmp(type, "response") == 0) {
        cJSON *text = cJSON_GetObjectItem(event, "text");
        cJSON *transcription = cJSON_GetObjectItem(event, "transcription");
        cJSON *intent = cJSON_GetObjectItem(event, "intent");

        if (transcription && cJSON_IsString(transcription)) {
            ESP_LOGI(TAG, "Transcription: %s", transcription->valuestring);
        }

        if (intent && cJSON_IsString(intent)) {
            ESP_LOGI(TAG, "Intent: %s", intent->valuestring);
        }

        if (text && cJSON_IsString(text)) {
            ESP_LOGI(TAG, "Response: %s", text->valuestring);
        }

    } else if (strcmp(type, "audio_chunk") == 0) {
        // TODO: Implement TTS audio playback
        ESP_LOGD(TAG, "Received audio chunk (playback not yet implemented)");
    }
}
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

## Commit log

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2026-02-15 Switch to ESPHome + microWakeWord for wake word detection
    This commit replaces the ESP-IDF Porcupine approach with ESPHome +
    microWakeWord, providing better community support and easier customization.
    ## Why This Change?
    - microWakeWord has hundreds of community-created custom wake words
    - ESPHome provides YAML configuration (easier than C programming)
    - Home Assistant integration enables OTA updates and web dashboard
    - Proven ecosystem with thousands of users
    - Better hardware support for ESP32-S3
    ## New ESPHome Firmware (firmware/polly-esp32-esphome/)
    - Complete ESPHome YAML configuration
    - microWakeWord integration with "okay_nabu" model
    - INMP441 I2S microphone support
    - RGB LED stat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
    [partitions.csv]
2026-02-20 Add server-side wake word detection + ESP32 WebSocket streaming
    Server: OpenWakeWord loads hey_polly.onnx at startup, new /api/audio/continuous
    WebSocket endpoint receives continuous PCM from ESP32, detects wake word,
    buffers until silence, then runs Whisper STT -> intent -> TTS pipeline.
    Old /stream endpoint preserved.
    Firmware: Replaced ESP-SR WakeNet with esp_websocket_client. ESP32 continuously
    streams mic audio as binary WebSocket frames. Handles server events
    (wake_word_detected, response, audio_chunk) for beep/LED/TTS playback.
    Also adds wake-word training samples, model files, and scripts to repo.
    [partitions.csv]
2026-02-22 Fix TTS threading issue and database import
    - Remove asyncio.to_thread() from TTS calls to fix Windows COM threading issue
    - Fix PollyDB import in homeassistant.py (was incorrectly importing Database)
    - Update firmware and wake-word files
    [partitions.csv]
2026-02-22 Fix ESP32 firmware: remove beep feedback loop, improve WebSocket stability
    - Disable startup and wake word beep sounds (mic/speaker feedback loop)
    - Keep streaming during wake word detection (server needs audio for command capture)
    - Add 1s cooldown after response playback to prevent re-trigger
    - Add WebSocket connection check before sending
    - Increase send timeout to 2s with backoff on failure
    - Reduce WebSocket buffer to 4KB to lower memory pressure
    - Add network_timeout_ms to WebSocket config
    - Fix format strings for ESP-IDF v5.4.3 compatibility
    [main.c]
2026-02-24 Cloud migration + full feature build (Phases 0-7)
    - Abstract STT/TTS behind swappable interfaces (whisper/aws_transcribe, pyttsx3/aws_polly)
    - Convert JS data files to JSON, add DataLoader (1040 jokes, 312 questions)
    - Expand intent parser to 14 intents (jokes, questions, bible, meds, weather, nav)
    - Central CommandProcessor handles all intents across all API routes
    - Add AWS Transcribe STT, Amazon Polly TTS, and VAD wake word backends
    - Expand database schema (11 tables: items, devices, users, stories, meds, bible, etc.)
    - Add medication reminder scheduler, bible verse service, almanac weather
    - Add story mode recording, question engine, OpenAI follow-up generator
    - Add API key auth middlew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
2026-02-28 Raise VAD threshold and require consecutive frames to avoid false triggers
    - RMS threshold 300 -> 1500 to filter mic noise
    - Require 4 consecutive loud frames (~320ms of speech) before triggering
    - Add periodic RMS logging for threshold tuning
2026-02-28 Fix wake phrase detection and ESP32 state recovery
    - Add common mishearings of "polly" (play, holly, paulie, etc.)
    - Send no_wake_word event so ESP32 resumes streaming after false triggers
    - ESP32 handles no_wake_word to reset LED and unpause
    [main.c]
2026-02-28 Add 1.5s pre-roll buffer and fix silence detection threshold
    - Pre-roll captures audio BEFORE VAD trigger so wake phrase isn't cut off
    - Use VAD threshold (200) for silence detection during recording too
    (was using 300 which is higher than speech levels on this mic)
2026-02-28 Fix audio looping and speaker-to-mic feedback
    - Flush I2S DMA with silence after playback to stop audio repeating
    - Drain mic buffer for 2s after playback before resuming stream
    - Server-side 3s cooldown after response to ignore speaker feedback triggers
    [main.c]
2026-02-28 Add repeat/skip support in conversational mode
    - Add "ask me again", "what was the question", etc. to repeat phrases
    - Handle repeat intent in conversational mode: re-asks current question
    - Handle skip intent in conversational mode: moves to new question
2026-02-28 Skip wake phrase check in conversational mode
    In STORY_PROMPT/FOLLOWUP_WAIT mode, user answers without saying
    "Hey Polly" — don't reject their answer for missing the wake phrase.
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2026-02-28 Add family portal: setup, transcriptions, photos, AI memory scan, mobile-first redesign
    Phase 1: Device setup page (/web/setup) with owner/caretaker fields,
    relationship follow-up voice flow (AWAITING_RELATIONSHIP mode).
    Phase 2: Transcription review page (/web/transcriptions) with
    verify/edit/filter functionality.
    Phase 3: Photo gallery (/web/photos) with upload, tags, story linking.
    Memory page: AI photo scan using OpenAI Vision to identify items,
    editable cards with location autocomplete, batch save.
    All templates redesigned mobile-first with hamburger nav.
    DB migrations for new columns + photos table.
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2026-03-07 Fix stories showing original transcript instead of corrected, add question context
    - Dashboard and Stories pages now display corrected_transcript when available
    (was always showing original transcript even after verification edits)
    - Add question_text column to stories table so we know what question prompted each story
    - Save current_question when stories are recorded from family question sessions
    - Show "Q: ..." above each story on dashboard, stories, and transcriptions pages
2026-03-07 Add browser mic photo story recording
    Family members can now tap "Tell me about this photo" on any photo,
    record a voice memory using their phone's mic (no ESP32 needed), and
    the story gets transcribed and linked to that photo automatically.
    - Browser mic capture via AudioContext + ScriptProcessorNode (16kHz PCM)
    - POST /web/photos/{id}/record-story endpoint: receives audio, transcribes, saves
    - Recording modal with live volume meter, timer, error handling
    - Stories saved as source=photo_story with photo_id + question_text context
    - Bidirectional photo<->story linking
    - photo_id column added to stories table (migration)
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2026-03-07 Fix family tree photo modal: always-visible edit/delete buttons, first-name tag search
    - Replace group-hover edit/delete overlay with always-visible buttons to fix mobile tap interception
    - Add first-name fallback search so "Brooklyn Rogers" also finds photos tagged "Brooklyn"
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2026-03-07 Fix ESP32 freeze after empty transcription: send TTS audio for fallback response
    When Google STT returned empty, server sent response event with no audio.
    ESP32 paused mic streaming waiting for audio_chunk final:true that never came.
    Now sends TTS "I didn't catch that" so ESP32 gets audio and resumes normally.
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2026-03-07 Fix message board: capture full status phrase and clean name extraction
    - Status now captures full phrase like "going to the garage" instead of
    just "the garage"
    - Added "I will be going to" pattern for status updates
    - Name extraction strips wake phrases (hey, polly) and filler words
    so "hey Polly hey Polly where is Dad" doesn't get "Hey" as the name
    - Response says "I'll let everyone know dad is going to the garage"
    instead of "I'll remember dad is the garage"
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2026-03-08 Add kid jokes (fart/poop/unicorn) + fix joke punchline timing
    - 100 silly kid jokes for 5-6 year olds (potty humor, unicorns, dinosaurs)
    - New "tell me a kid joke" / "potty joke" / "fart joke" voice intents
    - SSML <break time="2s"/> pause before punchline on all jokes
    - AWS Polly auto-detects SSML when text contains <speak> tags
    - Waveshare ESP32-S3 audio board firmware (ES7210/ES8311/TCA9555)
    [partitions.csv]
2026-03-08 Add parrot squawk & chatter ambient sound system
    - Short squawks: random every 5-15 min idle, 20% after TTS, on wake word
    - Long chatter (3 parakeet clips ~50s each): random every ~2 hours
    - Interruptible: "be quiet", "shut up", "hush", "stop squawking", or wake word
    - Sassy quiet responses: "Okay okay! Squawk." / "Fine, I'll be quiet. For now."
    - All server-side, no firmware changes needed
2026-03-08 Fix squawk: remove wake squawk (caused mic feedback), lower volume to 30%
    - Wake squawk was playing audio right after wake detection, ESP32 played it
    instead of listening for command → "No wake phrase detected" loop
    - All squawks/chatter now at 30% volume to prevent mic pickup
    - Post-response squawk delay increased to 3.5-5s (past cooldown window)
2026-03-08 Fix concurrent WebSocket write crash — add send lock for squawk/TTS
    - Squawk background task was writing to WebSocket at same time as TTS,
    causing AssertionError in websockets drain → connection killed
    - Added asyncio.Lock per device shared between squawk sends and TTS sends
    - All _send_tts calls in continuous_stream now use the lock
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2026-03-08 Add WiFi provisioning (AP captive portal) to both firmwares
    Boot flow: NVS saved creds → hardcoded fallback → AP captive portal
    - "Polly-Setup" open AP with captive portal at 192.168.4.1
    - DNS redirect for auto-portal-open on iOS/Android/Windows
    - WiFi scan + network list with signal strength bars
    - Dark themed mobile-friendly setup page with parrot emoji
    - Credentials saved to NVS, device reboots to connect
    - Hold BOOT button 3s on startup → force provisioning mode
    - Works on both breadboard (COM3) and Waveshare (COM4)
    [main.c]
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2026-03-08 Fix message board: 'Everyone' sends as recipient instead of empty
    Prevents messages to Everyone from being read as status updates.
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2026-03-08 Add real weather via Weather.gov with IP geolocation
    - Auto-detects location from ESP32/browser client IP
    - IP → lat/lon via ip-api.com (free, no key)
    - lat/lon → Weather.gov for current conditions + forecast (free, no key)
    - 2-hour cache per IP to avoid API hammering
    - Falls back to Farmer's Almanac if API fails
    - Blends real weather with almanac fun facts
    - Reads X-Forwarded-For/X-Real-IP behind Nginx proxy
2026-03-08 Shorten weather response + dynamic cooldown for long TTS
    Weather: trimmed to current temp, today's forecast, tomorrow, almanac fact.
    No more humidity/wind/3-day details cluttering speech.
    Cooldown: now scales with TTS audio duration (base 3s + playback time)
    so the mic doesn't pick up speaker output during long responses.
2026-03-08 Fix tell_time crash, reset conversation state on reconnect, add bible phrases
    - Remove shadowing `from datetime import datetime` inside process() that
    crashed tell_time/tell_date with UnboundLocalError
    - Reset conversation state on device reconnect so stale FOLLOWUP_WAIT mode
    doesn't persist across WebSocket disconnects
    - Add "verse of the day" / "daily bible verse" to bible intent phrases
    - Fix confusing question wording ("this memorable trip" → "your most memorable trip")
2026-03-08 Add configurable squawk/chatter intervals + snooze for nap time
    - Default chatter interval reduced from 2 hours to 45 minutes
    - Web settings: dropdowns for short squawk (5-60 min) and chatter (15-240 min)
    - Snooze buttons: 30 min, 1 hr, 2 hr, 8 hr — silences all bird sounds
    - Snooze state shown with "Wake Up Polly" button to cancel
    - Settings update live — connected devices get new intervals immediately
    - DB: squawk_interval, chatter_interval, squawk_snoozed_until columns
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2026-03-08 Fix status update intent + WebSocket disconnect crash
    - Add "going for", "went for", "out for" to status update patterns
    ("dad is going for a walk" was hitting unknown intent)
    - Catch RuntimeError on websocket.receive() when device disconnects
    during startup squawk send
2026-03-08 Add test_A suite (183 tests), fix intent bugs, update docs
    Test suite:
    - 183 parametrized tests covering all voice intents
    - Greetings, jokes, bible, weather, time, meds, items, messages,
    status updates, stories, navigation, identity, false positives,
    contraction normalization
    Intent fixes found by test_A:
    - "wallet" falsely matched location (substring "wall") — use word boundaries
    - "what did i miss" / "what did you say" hit hear_stories — removed
    greedy "what did" phrase, replaced with specific patterns
    - "i'm going to bed" hit status_update — exclude bed/sleep destinations
    Docs updated:
    - FEATURE_MAP.md: Waveshare hardware, parrot sounds, message board,
    real weather, deplo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
2026-03-08 Fix squawk/chatter triggering false 'I didn't catch that' responses
    Speaker feedback after squawk playback was hitting VAD wake detection
    because there was no cooldown after squawks ended. Added last_squawk_end
    tracking to SquawkManager and cooldown checks in both conversational
    and wake word detection paths. 'Be quiet' interrupt still works mid-squawk.
2026-03-08 Update Waveshare firmware: increase WS buffer, fix idle disconnects
    - WS_BUFFER_SIZE 4096 → 8192 for larger messages
    - network_timeout 10s → 30s to prevent idle disconnects
    - Add ping_interval 20s to keep WebSocket alive
    - Add build_and_flash.bat convenience script
    [main.c]
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2026-03-08 Add firmware watchdog: auto-reboot after 60s disconnect, reset state on reconnect
    - Reset streaming_paused, response state, and story_recording on reconnect
    - LED off on disconnect to indicate connection lost
    - 60-second watchdog reboots device if WebSocket stays disconnected
    - Prevents stuck state after server restart
    [main.c]
2026-03-08 Fix watchdog: treat WebSocket send failure as disconnect
    Send failures (-1) now set ws_connected=false so the watchdog counter
    starts. Previously the device got stuck in an error loop without
    triggering the 60s reboot because the DISCONNECTED event never fired.
    [main.c]
2026-03-09 Rewrite squawk timers to clock-based scheduling
    Squawk/chatter timers were resetting on every WebSocket reconnect,
    causing chatter to fire only once per day and squawk clusters on
    reconnect. Now uses wall-clock epoch timestamps that survive
    disconnects. Single polling loop per device checks every 15s.
2026-03-09 Add OTA firmware updates, multi-network WiFi, squawk busy flag
    - OTA: dual partition layout, server check/download API, web portal page
    - WiFi: 5-slot NVS storage, scan-match-connect, PMF for iPhone hotspots
    - Squawk: busy flag prevents squawks during active conversations
    - Firmware: version reporting in WebSocket connect message
    [partitions.csv]
2026-03-09 Delay startup squawk 10s to prevent disconnect on connect
    The immediate squawk on WebSocket connect was arriving before the
    ESP32 finished initializing, causing "could not lock ws-client" and
    a disconnect.
2026-03-09 Fix firmware version not saving: use DB device_id for update
    The WebSocket device_id ("polly-waveshare") didn't match the DB
    device_id ("polly-c419eab2"), so the UPDATE had no effect.
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2026-03-09 Add admin dashboard: device health, usage stats, error tracking
    New device_events table tracks every command, connect, disconnect,
    and error per device. Admin-only /web/admin page shows: online/offline
    devices across all tenants, command counts, top intents (7-day),
    recent errors. All logging wrapped in try/except to never crash
    the audio pipeline.
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2026-03-13 Claim code provisioning: device gets credentials via captive portal + server API
    Firmware: captive portal now shows claim code field for new devices, stores
    claim code in NVS, calls /api/devices/provision after WiFi connects to get
    device_id + api_key. Credentials stored in NVS. Hardcoded DEVICE_ID/API_KEY
    become fallbacks only. All devices can now be flashed with identical firmware.
    Server: new POST /api/devices/provision endpoint (unauthenticated) accepts
    claim code, generates fresh API key, returns device_id + api_key. Web claim
    flow no longer clears claim_code (so device can still use it).
    [main.c]
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2026-03-14 Add adaptive TTS chunking and paused-state watchdog to fix ESP32 freeze
    Server: smaller chunks (4KB/80ms) for large audio, medium (6KB/60ms) for
    mid-size, prevents TCP buffer overflow on ESP32 during long prayers/stories.
    Firmware: new 45s paused-state watchdog catches device stuck waiting for
    response_complete that never arrives (ws_connected=true but frozen).
    [main.c]
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2026-03-24 Fix post-playback crash: clear stale buffer, reboot on dead WS, heap logging
    - Clear response buffer after playback to prevent stale data collision
    - Force reboot if WebSocket died during playback
    - Log heap/PSRAM after each playback for crash debugging
    - Version bump to 1.0.2
    [main.c]
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2026-03-25 Fix v1.0.2 regression: stale buffer clear was wiping incoming TTS
    The aggressive buffer clear after playback was resetting
    response_audio_len to 0 while new TTS chunks were arriving,
    causing the real response audio to never play. Removed the
    clear — play_response_audio() already resets the buffer.
    Version bump to 1.0.3.
    [main.c]
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2026-03-25 Fix device crash during long recordings (v1.0.4)
    Root cause: During 170+ second story recordings, sustained mic
    streaming starved the WebSocket ping/pong mechanism, causing
    the server to think the device disconnected.
    Fixes:
    - WebSocket task stack: 8KB → 12KB (prevent stack overflow on
    long sessions with lots of JSON parsing)
    - Ping/pong timeout: default → 60s (long recordings block sends)
    - Mic send timeout: 2s → 500ms (prevents blocking the entire
    loop, lets ping/pong breathe)
    - Send failure tolerance: 5 consecutive failures before disconnect
    (was instant disconnect on first failure, too aggressive)
    - Reset fail count on successful send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
    [main.c]
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2026-03-25 Fix build error: move send_fail_count declaration to outer scope
    [main.c]
2026-03-25 Fix v1.0.4 disconnect loop: revert send timeout to 2s (v1.0.5)
    500ms send timeout was too aggressive — caused transport_poll_write
    errors every 20-30 seconds even idle. Reverted to 2s. Keeps the
    other v1.0.4 fixes: 12KB stack, 60s pingpong, 5-strike tolerance.
    [main.c]
2026-03-25 Fix story_btn stack overflow + missing os import (v1.0.6)
    - story_btn task stack: 2048 → 4096 (was overflowing on v1.0.5)
    - Added missing 'import os' in audio.py (broke blessing playback)
    [main.c]
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2026-03-26 Remove hardcoded WiFi fallback — fresh devices go to captive portal
    SpectrumSetup-73 was hardcoded as fallback, preventing new devices
    from entering captive portal when flashed at home. Now only tries
    NVS-saved networks. Fresh flash = no saved WiFi = captive portal.
    [main.c]
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2026-03-28 RGB LED status: WS2812 color states for visual feedback
    - Green = listening (wake word detected)
    - White = thinking (processing on server)
    - Blue = playing audio response
    - Red = disconnected/error
    - Red blink = provisioning mode
    - Yellow = story recording
    - Off = idle, waiting for wake word
    - Uses ESP-IDF led_strip driver for proper WS2812 protocol on GPIO48
    - Same data line can drive external LEDs on PCB (Polly's eyes)
    [main.c]
2026-03-28 Captive portal: replace JS fetch with HTML form POST for bulletproof setup
    - Connect button is now a native <form> POST instead of JavaScript fetch()
    - Works on every mobile browser regardless of JS restrictions
    - Scan for Networks still uses JS (nice-to-have, not critical path)
    - Form has HTML5 validation (required fields, pattern for claim code)
    - Fixes the "button does nothing" bug Matt hit during setup
    [main.c]
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2026-03-29 Port RGB LED status to breadboard firmware (polly-s3-wakeword)
    Same color states as Waveshare:
    - Added led_strip dependency for WS2812 on GPIO48
    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
    [main.c]
2026-03-29 Fix breadboard firmware: update SERVER_HOST from old IP to polly-connect.com
    [main.c]
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2026-05-04 Track project assets, finalized PCB exports, drop dirty backups
    - LOGO_AND_IMAGES/: brand and marketing images
    - Polly_Multi_Device_Guide.pdf, flash_future_polly.docx: user docs
    - build_user_guide_docx.py: doc build script
    - polly_flyer.html, polly_logo_from_doc.png: marketing assets
    - hardware/polly-board/polly_pcb_{bom,cpl}_jlcpcb.csv + top-pos.csv:
    finalized JLCPCB-ready exports
    - .gitignore: ignore KiCad backup zips, broken-name `${polly_pcb}.csv`,
    and stale duplicate pos CSVs in wi_barbell-attachments/ + hardware/
    root (canonical copies live in hardware/polly-board/)
    [polly_pcb_bom_jlcpcb.csv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]
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2026-05-10 Replace stale v1 PCB files with Paul's v2 (canonical), add alt-fiverr slot
    - Move stale March-18 v1 KiCad/BOM/CPL files into hardware/polly-board/v1-archive/
    - Drop Paul's actual v2 KiCad project + production package into hardware/polly-board/
    (Polly_v2.kicad_pro/.kicad_sch/.kicad_pcb, EasyEDA library with 3D models,
    production/Polly_V2.zip + BOM CSV + positions CSV + IPC netlist)
    - Rewrite COMPONENTS_FOR_DESIGNER.md to match Paul's actual choices:
    AP7361-33 LDO (was AMS1117), SK6812SIDE-A-RVS (was WS2812B-Mini),
    SMD JSTs (S2B/S3B-PH-SM4-TB instead of through-hole),
    GAIN_SLOT to GND for 15dB max, SD_MODE on GPIO13 for software amp control,
    C2/C3 reset+boot RC filter caps, L1-L4 f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
    [Polly_V2_bom.csv, Polly_V2_designators.csv, Polly_V2_positions.csv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]
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2026-06-03 Add Polly v2 board bring-up firmware (ESP-IDF) — validated on hardware
    Confirmed working on Paul's canonical v2 board: boots clean, SK6812 LED lights
    (solid white then color sweep), amp un-muted via GPIO13. Pin map verified
    against schematic + netlist:
    amp MAX98357: DIN=10 LRCLK=11 BCLK=12, SD_MODE=13
    mic ICS-43434: SD=4 WS=5 SCK=6 (left)
    LED SK6812: data=48
    Console over USB-Serial-JTAG. LED-first + non-fatal audio init so a subsystem
    failure can't crash the app. Mic readout temporarily omitted; to be re-added.
    [main.c]
2026-06-03 Fix ~30s WebSocket drop on global-key devices (server-side root cause)
    The continuous audio handler crashed every ~30s with UnboundLocalError on
    'db_device_id' (audio.py:443, the "ping" handler). db_device_id was only
    assigned in the device-key auth branch, so devices using the GLOBAL key
    (device_info is None) hit the first keepalive ping and crashed → server closed
    the socket → device reconnected → repeat. Initialize db_device_id=None before
    the loop so the ping handler is safe on the global-key path.
    Also hardens the s3-wakeword firmware WebSocket config to match the waveshare
    build (network_timeout 30s, RFC6455 ping 20s, pingpong 60s) + USB-Serial-JTAG
    console so it runs/monitors o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
    [main.c]
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2026-06-06 Firmware v1.0.1: WiFi power-save off + TCP keepalive (stop stale connections)
    The device could go into a half-dead WebSocket state (connected but audio not
    flowing, wake word dead) that only a manual reset fixed. Disable WiFi modem
    power-save on both connect paths (esp_wifi_set_ps(WIFI_PS_NONE)) and enable
    OS-level TCP keepalive on the WebSocket (~25s dead-link detection -> auto
    reconnect). Version bumped to 1.0.1 and published to the OTA server (active
    for variant 'breadboard'), so devices self-update over WiFi.
    [main.c]
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
